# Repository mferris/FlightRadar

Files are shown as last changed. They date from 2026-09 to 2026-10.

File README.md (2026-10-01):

<p align="center">
  <picture>
    <source media="(prefers-color-scheme: dark)" srcset="assets/brand/logo-on-dark.svg">
    StratoScan
  </picture>
</p>

# StratoScan

*Formerly Radome, and before that FlightRadar.*

A live ADS-B flight radar on a round display, built on a
Raspberry Pi and a cheap SDR dongle — no subscription and no API keys. The
radar needs nothing but its own receiver and a browser; an optional iPhone
app brings it to your pocket.

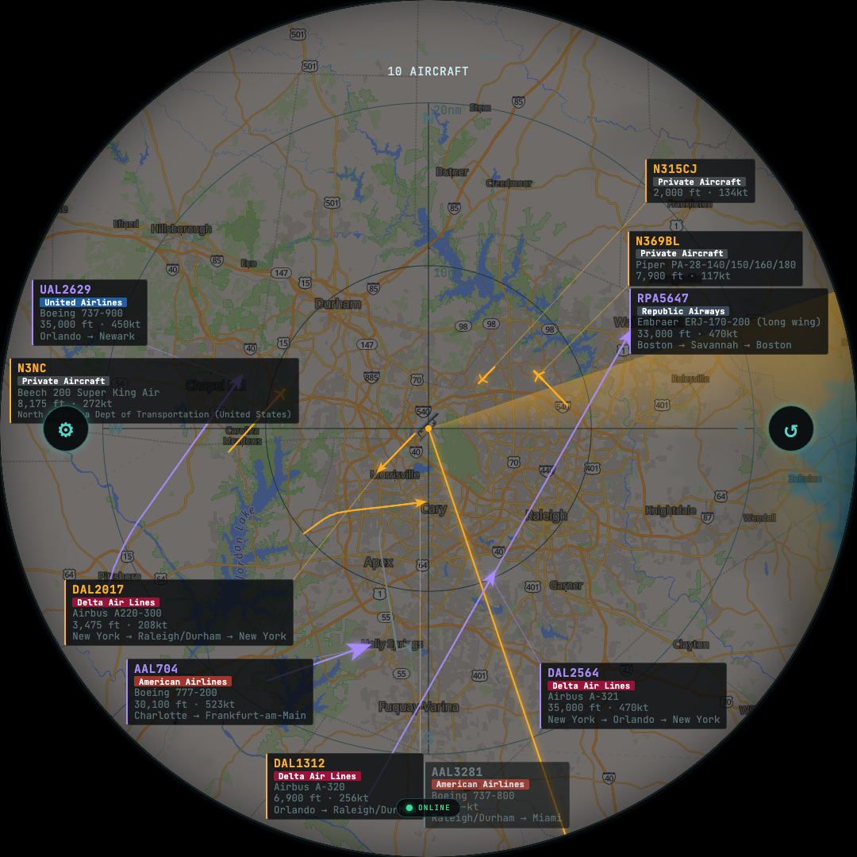
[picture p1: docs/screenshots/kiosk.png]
StratoScan running on the physical kiosk display


<sub>Centred on RDU airport. Map: OpenFreeMap © OpenMapTiles, data © [OpenStreetMap contributors](https://www.openstreetmap.org/copyright).</sub>

## Status

*As of 2026-09-30.* One unit (RDU) runs around the clock on release
`2026.09.30.11`. The plan is in [docs/ROADMAP.md](docs/ROADMAP.md), tracked
as [issues](https://github.com/mferris/StratoScan/issues), and the parts it still
needs are in the [shopping list](docs/SHOPPING.md).

| Area | State |
|---|---|
| The radar (kiosk) | Running unattended; updates itself from signed releases. One labelled aircraft feed on the unit for every screen (`/api/aircraft`); drawing cost halved |
| Phase 4 extras | Done: rewind, notable aircraft, empty-sky screen, spoken announcements, year in review, opt-in FlightAware feeding |
| Relay (push + fleet health) | Live on Cloudflare Workers |
| iPhone and iPad app | Working on a real iPhone: QR pairing, push alerts (including aircraft approaching *you*), widgets, Live Activity, home/away switching, the network's aircraft, zoom, a compass, Sky view with tracks, the logbook, weather, colour themes; a no-radar mode and an iPad layout (simulator-tested) |
| Apple Watch app | Built (glance radar, complications, Smart Stack); waiting for TestFlight to reach a real Watch |
| Security review | Full scan done 2026-09-28; every finding fixed and verified on the running unit |
| Factory SD image | Builds and passes its checks in CI; not yet test-flashed or published |
| Next up | Factory image test, the Watch on a real wrist, RTC battery fitting, alerts for aircraft approaching the phone, hardware v2 (light sensor, bezel) |

## What it does

Point an RTL-SDR dongle and a small antenna at the sky, and StratoScan turns
whatever ADS-B traffic it hears into a live circular radar display: bearing,
range, altitude, speed, heading, airline, aircraft type, route, and (when
available) a real photo of the airframe. It's designed to run unattended,
full-screen, on a small round touch panel — on a wall, or in the printed desk
cradle — but it's also just a web page, so it runs fine in a normal browser
too.

- **Live tracking** — polls a local [`readsb`](https://github.com/wiedehopf/readsb)
  instance every second; altitude-coded blips, smooth interpolation between
  polls, a "NO SIGNAL" banner on connection loss
- **Airline & route lookup** — badges each flight with its airline and shows
  its city-pair route where one's known, including multi-stop regional
  rotations
- **Aircraft type & photo** — human-readable type names ("Bombardier Regional
  Jet CRJ-900") and a real photo when one exists, falling back to a
  representative photo of the type
- **Background map** — real terrain, roads, and runway outlines (cached once
  fetched, so a restart doesn't wait on a fresh query), darkened and centered
  on the receiver, with an always-on live weather radar overlay and an
  optional satellite lightning-strike overlay
- **Approach visualization** — a real density heatmap of your home airport,
  built from actually observed landings over time rather than a canned
  flight-path overlay — busier stretches of the corridor read as more
  visually distinct than lightly-used ones, and it keeps sharpening the
  longer the receiver runs
- **Altitude-scaled blips** — a blip grows with altitude, from 0.68x on the
  ground to 1.30x at cruise, so height reads at a glance alongside the
  existing altitude colour. Deliberately not perspective: a higher aircraft
  is further away and would be smaller if this were about distance
- **Sighting counts** — every aircraft tracks how many distinct times this
  receiver has picked it up, and how many of those came within the
  nearby-alert radius; shown as a "SEEN ×N" badge once it's more than one,
  and as fields in the detail panel always
- **Registered-owner lookup** — for aircraft confirmed private (a real
  callsign, just not an airline one), the detail panel shows who the plane
  is registered to, pulled from public aircraft-registry data
- **Nearby-aircraft alert** — auto-pops flight details (with a chime) for
  anything passing within 2 miles of the receiver
- **Lightning proximity alert** — a chime + banner when a satellite-observed
  strike is detected within 15nm of the receiver, independent of the map's
  lightning overlay toggle
- **Rare aircraft alert** — a chime and an auto-popped panel for something
  worth walking outside for: an airframe on a military/government ICAO
  address, or an unusual type (747, A380, C-17, warbirds). Once the receiver
  has met enough traffic to know what normal looks like locally, it also
  flags aircraft it has never seen before
- **Emergency squawk alert** — an unmistakable alert (distinct chime + a red
  auto-popped panel) for 7500 (hijack), 7600 (radio failure), or 7700
  (general emergency)
- **Landing/takeoff highlight** — a bright green ring around the blip and
  label of anything currently landing or departing at your home airport, plus
  an optional quiet chime; pairs with an optional link to LiveATC.net's live
  approach/departure audio
- **Volume, mute, and a choice of alert sound** — every chime above goes
  through one master gain, adjustable up to 300% (with a limiter, so louder
  never means distorted) plus mute, and can play the original synth tones or
  real CC0-licensed recordings: cat sounds for a kitten-cased unit, or a real
  airline cabin chime for anyone — see `sounds/*/CREDITS.md` for what was
  recorded and how
- **Night dimming** — the display darkens between sunset and sunrise,
  computed from the receiver's own coordinates so it tracks the seasons
  without any configuration; alerts can optionally undim it
- **Screensaver** — the panel genuinely powers off after a configurable idle
  period (see [`deploy/`](deploy/)) and wakes on touch, or on an alert if
  you've enabled that
- **Settings menu** — a gear icon opens a menu grouped into short screens
  (Alerts, Map overlays, Display, ATC audio, Device setup) rather than one
  long list; every setting is one tap from the top, and the panel scrolls by
  dragging anywhere on it. Choices persist per-device
- **Configurable home airport** — 433 continental-US airports are bundled, so
  a unit can be moved or given away and re-pointed at a different field. The
  landing highlight, approach heatmap and ATC link all follow it
- **Set up entirely from the touchscreen** — WiFi (with an on-screen
  keyboard), receiver location, home airport, remote access and a factory
  reset, all without a phone or a shell. This is also the recovery path if
  the admin password is ever forgotten
- **First-run provisioning for a device you did not configure** — a unit with
  no known network raises its own `StratoScan-Setup` WiFi and displays what
  to join, what address to open and a claim code. A captive portal makes the
  setup page open automatically on a phone
- **Connectivity status** — a pill at the bottom of the display says whether
  the radar is actually working: online, on a network that is not reaching
  the internet, running its own setup WiFi, or receiving no aircraft data.
  On the device it reports what NetworkManager concludes about the
  connection; viewed remotely it falls back to whether data is still flowing
- **Restart from the screen** — a Restart row under Device setup, so a stuck
  unit does not need someone to find and pull the plug
- **Frozen-display watchdog** — the radar reports each painted frame to a
  local endpoint, and the device restarts the kiosk if the panel is powered
  on but nothing has been drawn for two and a half minutes. Chromium can
  lose its GPU context and stop painting while the page stays alive by every
  other measure, which otherwise leaves a stale radar on screen until
  somebody walks up to it. A blanked screen is not a fault: the watchdog
  checks the panel's real power state first
- **Statistics** — a Settings section that reads the accumulated flight
  history back: how many distinct aircraft have been heard and how many
  separate passes they made, how many came within two miles, and how much
  of it the antenna heard versus only saw through the network comparison.
  Broken down by operator (commercial / private / military — military
  recognised from the address block, so a military aircraft flying a
  civil-looking callsign still counts) and by airframe (heavy jets, jets,
  propeller, helicopters), using the same type database that decides each
  blip's shape. Plus all-time records — farthest contact, closest approach,
  highest, fastest — the busiest hour of the day and the busiest day of the
  week, and the most frequent visitors. The receiver scorecard lives here too
- **Network comparison** (on by default, and switchable off) — outlines the aircraft a public
  ADS-B network can see in your ring that your antenna did not hear, and
  keeps a scorecard of how you compare: overall coverage, which altitude
  bands and which bearings you are blind in, and position freshness against
  the network's. They are tracked, not just plotted: each keeps its identity
  between polls, is dead-reckoned forward from its last fix, and draws a
  dashed trail. Tap one to see what the network knows about it, clearly
  marked as reported rather than received. Measured here, the receiver was hearing 44% of the traffic
  in range, and 8 of the 9 it missed were below 4,000ft — the signature of a
  blocked horizon rather than a deaf receiver
- **Touch detail panel** — tap any aircraft for registration, squawk, vertical
  rate, and more
- **"What was that?"** — a rewind button lists the closest passes of the last
  hour and draws the chosen aircraft's track back onto the radar
- **Notable aircraft** — air ambulances, police, military and historic
  aircraft are labelled from [plane-alert-db](https://github.com/sdr-enthusiasts/plane-alert-db),
  refreshed weekly on each unit. Labels are neutral, and private owners'
  names are never shown
- **Empty-sky screen** — after 30 seconds with nothing overhead, a clock,
  the current weather and today's tally
- **Spoken announcements** (off by default) — a local
  [Piper](https://github.com/OHF-voice/piper1-gpl) voice names what is
  passing, generated on the unit with no cloud speech service
- **Year in review** — per-year counts of what the receiver heard
- **FlightAware feeding** (opt-in) — a setup-page card installs PiAware to
  share this receiver's data with FlightAware; it says plainly that the
  antenna's exact location is shared

### The iPhone app

A native SwiftUI app and widget ([`ios/`](ios/)), paired with a radar by
scanning a QR code on its screen:

- **The same radar in your pocket** — live aircraft, tap for details, and
  a label mode that keeps the map readable on a small screen
- **Alerts wherever you are** — emergency squawks, notable aircraft, low
  aircraft overhead and helicopters, pushed through the relay. Choose which
  kinds you want
- **Live Activity** (opt-in) — when the radar predicts a close pass (within
  2 miles in the next 3 minutes), a countdown appears on the lock screen and
  in the Dynamic Island, and closes itself after the pass
- **Home-screen and lock-screen widget** — how many aircraft are overhead and
  the nearest few; a radar widget for StandBy
- **Every aircraft, not just the ones the antenna hears** — the aircraft a
  public network (adsb.lol) reports are drawn hollow, with a "not heard" count
- **Zoom** — pinch on any spot, down to about a mile; the rings stay true
  distances from the radar. Follow an aircraft, or centre on yourself
- **Compass** — turn and the needle points at an aircraft, with which way it's
  coming from and going
- **Sky view** — hold the phone up and each aircraft's label sits where it is
  in the sky; tap one for its details. Away from home it can show the
  aircraft around you instead (opt-in; see [privacy](docs/privacy.md))
- **Logbook** — what your radar has seen: today, all-time totals, records
  (farthest, closest, highest, fastest), what flies over, when, and the
  regulars
- **Sky view tracks and Find in the sky** — each aircraft's path drawn
  across the sky; from any aircraft on the radar, a big arrow guides you to
  it in the camera view
- **Approaching you** (opt-in) — alerts for aircraft about to pass over
  where *you* are, not just the radar; your location is end-to-end
  encrypted to your own radar
- **Weather and themes** — rain, storms and lightning on the map, and the
  radar's four colour themes (Daylight by default)
- **iPad** — a big radar with details alongside, and a wall mode that dims
  at night
- **No radar yet?** — see live aircraft around you from the public
  adsb.lol network (opt-in), or play the demo
- **Home and away** — on your WiFi the app talks to the radar directly; away
  from home it switches to the radar's public HTTPS page by itself. The away
  address is learned from the radar
- **Demo mode** — a few minutes of real traffic recorded near RDU, so the
  app can be tried without a radar

## How it works

```
[Antenna] → [RTL-SDR dongle] → [readsb] → aircraft.json (local)
                                                 │
                                                 ▼
                                   [StratoScan: fetch + render]
                                                 │
                                                 ▼
                              [Chromium kiosk, full-screen] → [round display]

 Optional, for the phone app:

 [events.py on the unit] ──signed──▶ [relay: Cloudflare Worker + D1] ──APNs──▶ [iPhone]
        (what's worth an alert)        (pairing, push, fleet health)     (alerts, Live Activity)
```

The **relay** ([`relay/`](relay/)) is the project's one server. Units send it
signed events and opt-in health reports; it pairs phones with units and holds
Apple's push key, so no unit ever carries a secret that can act for the whole
fleet. The radar never depends on it: a unit that cannot reach the relay
works exactly as before. What it stores, and for how long, is in
[relay/README.md](relay/README.md).

`readsb` decodes raw ADS-B signals and writes `aircraft.json` to disk.
`index.html` is a single self-contained page — plain HTML/CSS/JS, Canvas for
the radar itself, [MapLibre GL JS](https://maplibre.org/) for the background
map — that polls that file and renders everything. No build step, no
framework, no server-side code beyond a couple of tiny same-origin proxies
(see [`deploy/`](deploy/)) for things browsers can't do directly, like
setting a custom User-Agent.

## Getting started

**Hardware and receiver setup** (Pi, RTL-SDR dongle, antenna, `readsb`
installation) is covered in [`docs/project-spec.md`](docs/project-spec.md),
including a suggested two-wave purchase plan so you can confirm reception
before buying a display.

One thing worth doing before you chase any reception problem: install
[`deploy/blacklist-rtlsdr.conf`](deploy/blacklist-rtlsdr.conf) to
`/etc/modprobe.d/`. The RTL2832U is sold as a TV tuner, so without it the
kernel's DVB-T driver claims the dongle on every plug and fights readsb for
it, producing `error -71` and constant disconnects.

**Running the web app locally**, against a receiver on your network:

```bash
python3 dev-server.py
```

Then open `http://localhost:8000/index.html`. `dev-server.py` proxies
`/tar1090/*` requests to your receiver so the page can be tested with the
exact same relative paths it uses once deployed — edit `PI_HOST` at the top
of the file to point at your own receiver. It's dev-only and isn't part of
the deployed app.

**Deploying as a kiosk**: `index.html` is a static file — copy it to your
receiver's web server docroot (same origin as `readsb`'s own web UI, to avoid
CORS). [`deploy/`](deploy/) has a systemd unit for launching Chromium in
kiosk mode on boot, plus small same-origin services: aircraft photos, the
shared approach-track store, the shared sighting-count store, the display-wake
endpoint, the optional network-comparison proxy, and (only relevant if you
expose the page to the public internet,
e.g. via Tailscale Funnel) a filtering gateway that rounds the receiver's
exact coordinates before they leave your network — see
[Security](#security) below.

**Device setup (optional)**: everything above works on a receiver you
configured yourself. If you want a unit someone *else* can set up — moved to a
new house, or given away — install the setup server:

```bash
sudo sh deploy/install-setup-server.sh
```

That adds a web setup page at `http://<device>/setup`, the same screens on the
radar's own touchscreen, and the pieces that make a device with no network
recoverable. The installer refuses to finish unless it can prove the public
gateway is refusing `/setup`, since that page accepts a WiFi password and a
Tailscale auth key.

How a fresh unit behaves:

1. It finds no known WiFi, so after ~45s it raises `StratoScan-Setup`
2. Its screen shows that network's name and password, the address to open,
   and an 8-character claim code
3. A phone joining that network gets the setup page automatically, via the
   captive portal
4. WiFi, receiver location, home airport and an admin password are set; the
   setup screen disappears

The same things can be done on the touchscreen instead, which is the only
route if the admin password is ever forgotten. **Erase everything** clears the
WiFi, the Tailscale identity, the password, the coordinates *and* the
accumulated flight history and approach heatmap — the last two are a record of
what flew over the previous owner's house — then raises the hotspot so the
next person can claim it.

Two services run as `systemctl --user` rather than system units (the
screensaver and display-wake endpoint) because they need the graphical
session's `WAYLAND_DISPLAY`. A `stratoscan-netwatchdog` timer rolls back any
unconfirmed network change at boot and raises the hotspot when there is no
usable connection — so a mistyped WiFi password reverts itself rather than
stranding the device.

**The 4am restart, and why it is a workaround.** Chromium on this platform
leaks unlinked `/dev/shm` mappings at roughly 200–300 MB/h of daytime
rendering. Left alone it fills the 4GB tmpfs in five to twelve hours, GPU
allocations start failing with `TransferBuffer::Initialize() failed`, and the
panel freezes on a stale frame — twice in one 34-hour stretch here.
`stratoscan-kiosk-restart.timer` restarts the kiosk at 04:00, when the panel
is already blanked and the sky is empty, returning `/dev/shm` from ~2GB to
~200MB. The frozen-display watchdog in `wake-listener.py` stays as the
backstop.

A second timer, `stratoscan-shmguard`, closes the gap the daily restart
leaves: it samples every five minutes and acts on the measurement rather than
the clock. **It reloads the page before it restarts the browser.** Tearing
down the document releases a third to a half of the accumulated shared memory
(151MB → 72MB and 124MB → 79MB, measured) without killing Chromium — no black
screen, no risk of coming back windowed — and the restart is kept as the
escalation for when a reload is not enough. Two marks, because a restart is only free when nobody is
looking — at **900MB it restarts only while the panel is blanked**, so most
restarts happen invisibly, and at **1500MB it restarts regardless**, which is
the one that actually prevents the freeze. It measures both `/dev/shm` usage
and the sum of Chromium's renderer shm mappings and acts on whichever is
larger, because the two diverge: `/etc/chromium.d/dev-shm` adds
`--disable-dev-shm-usage` when `/dev/shm` has under 3.8GB free at launch, so
after one bad day Chromium moves its backing to `/tmp` and the `df` number
stops tracking the leak. Restarts are rate-limited to one per 30 minutes — if
something other than the leak fills the arena, a guard that restarts forever
is worse than the freeze it was written to prevent. The 04:00 restart runs
through the same script (with `SHMGUARD_FORCE=1`) so both share that one rate
limit.

**Chromium must not be restarted while the panel is blanked.** It comes up
windowed — tab bar, address bar, desktop wallpaper — even with `--kiosk` on
its command line, because it cannot take an output that is off and does not
retry when the output returns. Reproduced both ways on the device: panel off
gives a windowed browser every time, panel on gives fullscreen every time.
This mattered most for the 04:00 restart, which by design runs when the
screensaver has blanked the panel, so it would have left the display windowed
every morning. The guard now wakes the panel, restarts, waits for Chromium to
take the display, and only then puts the panel back as it found it.

It also **repairs a windowed browser however it happens**, not just when the
guard itself caused it — that is the failure a recipient would simply live
with. Every run it grabs the screen and measures the top-left corner:
fullscreen reads 0 on this panel, windowed reads 232, so the threshold sits
at 60 with a wide margin. Verified by breaking it deliberately and watching
the guard put it back.

**A reload cannot be delivered while the panel is blanked**, and that took
two wrong diagnoses to see. The instruction rides the paint heartbeat, and
`reportPainted()` is driven by `requestAnimationFrame` — with nothing being
composited there are no frames, so the page never posts `/wake/alive` and
never collects the flag. Six attempts told the story cleanly: five with the
panel off freed 0MB each, with the listener logging no delivery at all, while
the one with the panel on freed **597MB of 700MB**.

The apparent pattern before that — "reloads stop working above ~600MB" — was
an artifact: every failed attempt happened to be panel-off. Memory level was
never the variable.

So the guard reloads only when the panel is on (at 700MB), and when the panel
is off it restarts outright at 600MB, which is invisible precisely because
the panel is off. A restart at 1400MB remains the backstop with the panel on.

The reload is requested without any control channel of its own. The page
already POSTs `/wake/alive` every 20 seconds as the frozen-display heartbeat;
the guard drops a file in `$XDG_RUNTIME_DIR`, and the listener answers that
next heartbeat with `{"reload":1}` instead of `204`. So there is no debug
port, no key-injection helper and no new listener: only a local process
running as the kiosk user can ask for a reload. Nothing is lost by reloading —
sightings, statistics and the approach heatmap all live in the server-side
stores — beyond trails and ghost tracks, which rebuild within a sweep.

It is a workaround and not a fix, because the cause is not in this codebase:
a blank page leaks the same way, the mappings are invisible to Chromium's own
`memory-infra` accounting, and a critical memory-pressure signal reclaims
none of them. Removing the map, the weather overlays and the canvas render
loop each failed to stop it. One caveat worth keeping in view: the observed
time-to-freeze was as short as 5.2 hours, so a single daily restart is not
guaranteed to cover a long, busy day on its own.

**The enclosure**: [`enclosure/`](enclosure/) has two printable cases for the
same hardware — the original ship's-instrument look, and one shaped like a
sitting cat with the round display as its face, printed in two colours. Both are parametric OpenSCAD,
everything deriving from the measured values at the top of each file. Each
folder's README covers how to export the parts, the interference checks, and
the dimensional mistakes that are easy to repeat.

**iOS app**: `ios/` is an [XcodeGen](https://github.com/yonaskolb/XcodeGen)
project (app plus widget extension, iOS 17.2 or later). Run `xcodegen generate`
inside `ios/` if you change `project.yml`, then open `StratoScan.xcodeproj` in
Xcode. To build your own, set your signing team, bundle id and App Group in
`project.yml`. On the radar, open Settings › Phone & Watch to show a pairing
code, then scan it from the app. Push alerts need your own relay and an APNs
key (see [relay/README.md](relay/README.md)); without them the app still
shows the live radar.

**Relay**: a Cloudflare Worker on the free plan. From `relay/`:
`npm test`, then `npm run db:init && npx wrangler deploy`. Apple's `.p8` key
goes in with `wrangler secret put APNS_KEY`, never into the repo.

## Project structure

```
index.html      the whole web app — single file, no build step
dev-server.py   local-only dev proxy (not deployed)
deploy/         systemd units, same-origin services, events, pairing and the setup server
docs/           roadmap, spec, privacy policy, gifting guide, screenshots
enclosure/      parametric OpenSCAD source for the printed cases (two designs)
tests/          regression tests for the security-critical paths
vendor/         vendored MapLibre GL JS (self-hosted, no CDN dependency)
sounds/         CC0 audio for the alert sound themes (see sounds/*/CREDITS.md)
ios/            native SwiftUI app, widget and Live Activity
relay/          Cloudflare Worker: pairing, push, fleet health
scripts/        signed release script
image/          factory SD-card image build (run in CI)
```

See [CHANGELOG.md](CHANGELOG.md) for release notes and
[HANDOFF.md](HANDOFF.md) for the detailed development history.

## Data sources

StratoScan leans entirely on free, no-key-required public data, same as
[tar1090](https://github.com/wiedehopf/tar1090) (GPL-2.0-or-later; it inspired
several of these choices, but no code is shared):

- **[readsb](https://github.com/wiedehopf/readsb)** — ADS-B decoding
- **[MapLibre GL JS](https://maplibre.org/)** (BSD-3-Clause, vendored under [`vendor/`](vendor/) — self-hosted, no CDN dependency) + **[OpenFreeMap](https://openfreemap.org/)** — background map tiles/style
- **[OpenStreetMap](https://www.openstreetmap.org/) via Overpass** — real runway/taxiway geometry
- **[adsb.im](https://adsb.im/)** — route (city-pair) lookups
- **[RainViewer](https://www.rainviewer.com/)** — live weather radar overlay (their API is free for personal/educational use only)
- **[planespotters.net](https://www.planespotters.net/)** — aircraft photos
- **[Wikimedia Commons](https://commons.wikimedia.org/)** — representative type photos when no tail-specific one exists, credited with author and license
- **[adsbdb.com](https://www.adsbdb.com/)** — registered-owner lookups for confirmed-private aircraft
- **[LiveATC.net](https://www.liveatc.net/)** — ATC audio for the configured airport, opened as a link to their own player (see [Security](#security) below for why it's a link, not an embed)
- **[SSEC RealEarth](https://realearth.ssec.wisc.edu/)** (UW-Madison) — satellite-observed lightning strike density (GOES-East GLM)
- **[Protomaps](https://protomaps.com)** OpenStreetMap builds (© OpenStreetMap contributors, ODbL) — the per-unit offline fallback map built by [`deploy/offline-map.py`](deploy/offline-map.py)
- **[OurAirports](https://ourairports.com/data/)** (public domain) — the bundled airport table in [`deploy/airports.json`](deploy/airports.json)
- **[plane-alert-db](https://github.com/sdr-enthusiasts/plane-alert-db)** (ODbL) — the notable-aircraft list
- **[tar1090-db](https://github.com/wiedehopf/tar1090-db)** — aircraft type and registration from the ICAO address, read from the unit's own tar1090 install
- **[Open-Meteo](https://open-meteo.com/)** — current weather on the empty-sky screen (free for non-commercial use)
- **[adsb.lol](https://adsb.lol/)** — community-run ADS-B aggregation, used only by the network comparison, which can be switched off. Queried at most once every 15s no matter how many people are viewing, with coordinates rounded to ~1.1km

Every obligation these carry, and how each is met, is in
[THIRD_PARTY_NOTICES.md](THIRD_PARTY_NOTICES.md). Please respect each
service's own terms if you build on this; RainViewer in particular is not
for commercial use.

## Security

If you expose this beyond your own LAN (e.g. a Tailscale Funnel URL, like the
live deployment this repo was built against), a few things are worth knowing
before you do:

- **The receiver's exact coordinates are not something you want publicly
  reachable.** `readsb`'s own `receiver.json` endpoint returns
  survey-precision lat/lon, and by default that's reachable by anyone who
  finds the URL. [`deploy/funnel-gateway.py`](deploy/funnel-gateway.py) sits
  in front of whatever you expose publicly and rounds those coordinates to
  ~0.7 mile precision for public traffic only — your LAN/kiosk always sees
  the exact value, which `readsb` itself needs for its own signal-range math.
  Point your public tunnel at this gateway instead of at `readsb`/lighttpd
  directly. The gateway also strips each aircraft's distance and bearing
  *from the antenna* (`r_dst`, `r_dir`) out of the public `aircraft.json`:
  with two or three aircraft positions, those fields pinpoint the receiver, which undid the rounding entirely.
- **External data (route text, photo credits, aircraft type) is escaped
  before it touches the DOM.** Some of it — a photographer's display name on
  planespotters.net, for instance — is third-party user-submitted content
  this app doesn't control.
- **The shared same-origin stores are read-only for public traffic.**
  `deploy/approach-store.py` and `deploy/sighting-store.py` have no
  authentication of their own, which was fine while only the LAN could reach
  them. Once the page is exposed through a tunnel they become writable by
  anyone holding the URL — confirmed by injecting a fake sighting through it
  — so the gateway now refuses any non-GET to `/sightings` and `/approaches`
  from public traffic (`READ_ONLY_PUBLIC_PATHS`). Reads stay open, because
  public viewers need them; the kiosk and LAN still write normally. They also
  cap request body size and validate input shape.
- **Privileged endpoints are refused for public traffic**, and the check
  normalises the path first. `/wake` (which powers the kiosk's panel on) and
  `/setup` are listed in `LOCAL_ONLY_PATHS` in
  [`deploy/funnel-gateway.py`](deploy/funnel-gateway.py) and 404 for anything
  arriving through the tunnel. The normalising matters: an earlier version
  compared the raw path, and because lighttpd percent-decodes and collapses
  traversal before routing, `/./wake`, `/x/../wake` and `/%77ake` all reached
  the endpoint anyway. [`tests/test_funnel_gateway_paths.py`](tests/test_funnel_gateway_paths.py)
  pins the behaviour — run it after touching that filter.
- **The setup server is split across a privilege boundary.** The HTTP tier
  runs unprivileged and can only ask a small root helper
  ([`deploy/setupd.py`](deploy/setupd.py)) to perform a closed list of verbs
  over a unix socket — there is no "run nmcli" passthrough, so compromising
  the HTTP parser does not yield arbitrary root. The root helper re-validates
  every parameter rather than trusting the caller, uses no shell, and keeps
  secrets out of argv (where any local user could read them from `/proc`).
  [`tests/test_setupd_validation.py`](tests/test_setupd_validation.py) pins
  the validation table and the `/etc/default/readsb` rewriter, which is a
  root-sourced shell file and therefore a command-execution sink.
- **On-device setup deliberately needs no password**, and the endpoint behind
  it is bound to loopback and not proxied, so reaching it means already being
  on the device. That is the same physical assumption every appliance makes,
  and it has to be true: it is the only way back in for someone who has
  forgotten the admin password. The web route, which *is* reachable across
  the LAN, still requires it.
- **Erasing a unit removes the accumulated data too.** The flight history
  and approach heatmap are a record of which aircraft passed over the
  previous owner's house — and the history now carries each aircraft's
  callsign and classification alongside its counts, which makes it more
  identifying than a bare tally, not less — so a full reset clears them
  along with the credentials and coordinates. A settings-only reset keeps them, and keeps
  the network, so it is safe to run remotely.
- **The network comparison is on by default and sends only a rounded
  position.** It can be switched off in Settings, and switching it off stops
  the device contacting adsb.lol at all. The device-side proxy makes
  no request of its own — it only fetches when a page with the setting on
  asks it to — and it queries with coordinates rounded to 2dp, the same
  precision the public gateway already exposes. Asking a stranger "what is
  near me" with survey-precision coordinates would undo the rounding the
  rest of this project does deliberately. `/network` is readable publicly
  but refuses writes, so nobody holding the URL can drive traffic at a
  community-run service on this device's behalf.
- **The display-wake endpoint answers only the device itself.** lighttpd
  refuses `/wake` from anything but `127.0.0.1` and `::1`, so a LAN device
  cannot power the panel on or fake the frozen-display heartbeat.
- **SSH is key-only.** The installer drops
  [`deploy/10-stratoscan-ssh.conf`](deploy/10-stratoscan-ssh.conf) into
  `sshd_config.d`: no passwords, no root login, no X11 forwarding. It
  validates the config with `sshd -t` before reloading.
- **Downloaded code is pinned.** The Piper speech engine installs with
  `pip --require-hashes` from
  [`deploy/tts-requirements.txt`](deploy/tts-requirements.txt), and its voice
  model is checked against [`deploy/tts-voice.sha256`](deploy/tts-voice.sha256).
- **Units and phones prove who they are to the relay.** Every unit request is
  signed with the unit's own Ed25519 key, and every phone request with a key
  generated on the phone. Pairing takes a one-time code shown on the radar's
  screen, which expires in 10 minutes or after five wrong guesses. Only a
  hash of it is stored.
- **No secrets in the repository or on units.** The radar's data sources are
  free and keyless (see [Data sources](#data-sources) above). The one secret
  the project has, Apple's push key, lives only in the relay as a Cloudflare
  secret.
- **ATC audio is a link, not an embed.** LiveATC.net's
  [Terms of Use](https://www.liveatc.net/legal/) require consulting them
  before linking directly to a raw audio stream, and separately bar making
  their service "directly available" through another dedicated application,
  for profit or not. The ATC toggle opens their own player page in a normal
  browser tab instead — ordinary use of their site, same as bookmarking it
  yourself — and is disabled outright on the kiosk itself (`?kiosk=1` on its
  launch URL), since a new browser window/tab inside `--kiosk` Chromium has
  no touch-reachable way back to the radar.

## License

MIT — see [LICENSE](LICENSE). The StratoScan name, logo and icons are not:
they identify the project, so a fork should use its own (see
[assets/brand/LICENSE](assets/brand/LICENSE)). Third-party components and data sources keep
their own licenses and terms; see [THIRD_PARTY_NOTICES.md](THIRD_PARTY_NOTICES.md).

## Setting one up somewhere else

The first build assumed the continental US in more places than was obvious,
and each one was a hard stop rather than a rough edge:

- **Coordinates were forced into the northern and western hemispheres.** The
  setup page and the touchscreen both "helpfully" made latitude positive and
  longitude negative, on the reasoning that a sign left off a US coordinate is
  unambiguous. It is — and it silently moved a receiver in the Netherlands
  (4.49°E) to 4.49°W, in the Atlantic, while making the entire southern
  hemisphere unreachable. `setupd` agreed, rejecting anything outside
  24–49.5°N and 66.5–125°W as "outside the continental US".
- **The airport list was 433 US airports.** Now 3,269 worldwide (large and
  medium fields with scheduled service, from OurAirports), so Schiphol and
  San Carlos are both a search away.
- **Time zone and WiFi region were baked into the image** as
  America/New_York and US, with no way to change either from setup. A unit
  abroad timestamped every sighting wrongly and ran its radio on the wrong
  channel set.
- **The lightning overlay is GOES-East**, which only sees the Americas.
  Outside that footprint every tile is a 404, so the setting now hides itself
  and says why rather than offering a toggle that cannot work.

**Location is entered as an address by default.** Nobody knows their
coordinates; everybody knows their address. The lookup runs on the *device*
rather than in the browser, because during first-time setup the phone is
joined to the device's own hotspot and has no route to the internet, while
the Pi was put on WiFi in the previous step — a browser-side lookup would
fail exactly when it is needed. The address reaches OpenStreetMap's
Nominatim and nothing else, the position it returns stays on the device, and
typing coordinates by hand remains one tap away for anyone who would rather
not send an address anywhere.

Picking the home airport sets the country, which seeds the time-zone step
with the one or two zones that country actually uses instead of all 485, and
sets the WiFi regulatory region to match. Both the phone page and the
touchscreen can complete setup on their own.

**The WiFi region only takes effect after a restart**, and both UIs say so.
Two things about `raspi-config nonint do_wifi_country` were found by running
it on the device rather than reading about it:

- **It exits non-zero on success.** Its NetworkManager and `wpa_cli` steps try
  to reach a session message bus, which does not exist when the call comes
  from a daemon, so it prints an error and returns 1 *after* writing the
  setting. Judging it by its exit code reports failure for a change that
  worked, so the result is judged by reading the value back instead.
- **The running regulatory domain does not change.** The Pi's Broadcom radio
  registers a custom regulatory table — `phy#0` reports `country 99` — so the
  driver overrides `iw reg set` and the global domain reads `98` until the
  next boot, when `cfg80211.ieee80211_regdom` on the kernel command line
  applies it for real.

The change is safe to make over WiFi: tested on a live link, the SSID, IP
address, connectivity, channel and an active SSH session were all unaffected
throughout.

Because it needs a restart, both surfaces offer one — but **only when the
region actually changed**. `set_wifi_country` reads the country before and
after and reports `changed`, so re-saving the same region never sends anyone
to power-cycle a working device. The prompt says the setting is stored, that
the radio still follows the old region until then, and that nothing else is
waiting on it, so leaving it until the next power-on is a legitimate choice
rather than an unfinished step.

## Updating a unit that has been given away

A gifted radar cannot be fixed by SSH, so it can update itself — carefully.

**Signed, or refused.** A release is accepted only if its manifest carries an
Ed25519 signature (`ssh-keygen -Y`) from the key in
`deploy/allowed_signers`, which is baked in before a unit ships. The private
half lives on the maintainer's machine and never touches a device, GitHub, or
CI. GitHub is delivery, not trust: a compromised account or token could
publish a release, it could not sign one. `ssh-keygen` rather than minisign or
gpg because it is already installed — no new dependency on a box nobody can
log into.

**Newer, or refused.** The device compares an integer serial, not a version
string. An old release stays correctly signed forever, so without this a unit
could be walked backwards onto a build whose bugs are already fixed.

**It undoes itself.** After installing, the display must paint a frame within
90 seconds or the previous files go back and the kiosk restarts again. This
reuses the heartbeat the frozen-display watchdog already depends on, so an
update that blanks the screen is caught by the thing already watching the
screen — with nobody in the room. Verified by signing and applying a build
that throws before rendering: it was staged, installed, failed to paint, and
rolled back, and the previous `index.html` came back byte-identical.

**It cannot install anywhere it likes.** Only an allowlisted set of
destinations is writable, which excludes `allowed_signers` itself — an update
must not be able to replace the key that vouches for it, or one bad release
owns the device forever.

Checking is a timer (twice a day, randomised). **Installing is a deliberate
act** from the settings screen or the setup page: a unit that silently
replaced its own software overnight would be a different thing to give
somebody. Neither surface ever claims "up to date" for a device that has
simply never looked.

The manifest carries each file's **executable bit** as well as its hash, and
only that bit — a manifest that could set arbitrary permissions on root-owned
files would be a much larger thing to sign off on than one that can say "this
is a program". It is there because the first real update installed a new
`ota.py` without its executable bit and broke its own updater; the services
survived only because their units run `python3 <script>` rather than exec'ing
it.

The paint check refuses to run at all if the heartbeat file is missing, rather
than rolling back every update. That, too, is from experience: the stamp
originally lived in `/run/stratoscan`, which is setupd's `RuntimeDirectory=`
— systemd recreates it root-owned whenever the root helper restarts, so the
kiosk user silently lost the ability to write it, and a perfectly good release
was reverted because nothing could record that the screen was painting. It now
lives in the kiosk user's own runtime directory.

To cut a release: `sh scripts/release.sh <version>`. It builds the bundle,
writes a manifest of per-file hashes, signs it, **verifies its own output with
the public key the devices carry**, and only then publishes to GitHub
Releases.

**Changed services are restarted.** A long-running service keeps its old code
until it restarts, and the updater originally restarted only the kiosk — so a
security fix to `funnel-gateway.py` was reported installed while the old
gateway kept running for hours. It now compares each file with the one it
replaces and restarts exactly the services whose code changed (and restarts
them again on a rollback). Like any change to `ota.py`, that behaviour starts
with the release *after* the one that installs it.

The serial is the commit count, so two releases cut from the same commit carry
the same serial and the second is refused as "not newer" — commit first.

## Built to run for ten years

Measured on the first unit and reviewed for a decade of unattended running at
busy sites (SFO, Schiphol) as well as quiet ones:

- **SD card wear.** The stores keep their data in memory and write at most
  every 10 minutes and on shutdown; they used to rewrite the whole file on
  every sighting (3.5 GB in 17 hours, ~100 GB/day at a busy site once full).
  Chromium's HTTP cache lives in RAM, and it keeps no shader cache on disk.
  Dirty pages are batched for two minutes before writeback. The history store evicts the aircraft
  seen *least recently*, so daily regulars survive a full store. Measured in
  steady state: 2.25 GB/day, about 8 TB over ten years, well under a 128 GB
  high-endurance card's rating.
- **Recovery without a person.** The hardware watchdog reboots a hung kernel;
  `kernel.panic=10` reboots a panicked one. `net-watchdog.py` also restarts
  `readsb` when its output goes stale and reboots after repeated failed
  restarts, and reboots when the frozen-display watchdog's browser restarts
  keep failing — never more than once every 6 hours, so a fault a reboot
  cannot fix degrades to a few reboots a day, not a loop.
- **A hung radio is power-cycled, not just rebooted.** The Pi 5 keeps USB
  power on through a reboot, so a wedged SDR stays wedged. Before rebooting,
  the watchdog cuts USB power with [uhubctl](https://github.com/mvp/uhubctl)
  for a few seconds and turns it back on (at most once every 30 minutes).
- **Security updates** via unattended-upgrades (Debian security and point
  releases, the Raspberry Pi archive, Tailscale), holding Chromium, the
  kernel and firmware — a bad unattended update to those strands a unit.
- **An offline map.** When the location is set or changed, the unit
  downloads its own area (2–7 MB) from [Protomaps](https://protomaps.com)'
  OpenStreetMap builds into `/offline-map/`, and the page falls back to it
  whenever OpenFreeMap can't be reached — so a dead tile service or a boot
  before WiFi is up shows a real map, not a blank disc.

These system-level pieces (unattended-upgrades, sysctl, unit files) are
installed by `deploy/install-setup-server.sh`, never by an update — re-run it
on any unit before it leaves the house. What remains is hardware: an RTC
battery (ML-2020, with `dtparam=rtc_bbat_vchg`) keeps the clock across power
cuts, and a high-endurance SD card or an NVMe drive is the better medium for
a decade.

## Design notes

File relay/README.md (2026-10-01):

# StratoScan relay

The one small server the project runs: a Cloudflare Worker with a D1
database. It receives **opt-in health reports** and **events** from units,
pairs phones with units by QR code, sends push alerts and Live Activities to
those phones through Apple (APNs), and shows the maintainer a fleet page. The design is
in [docs/ROADMAP.md](../docs/ROADMAP.md#architecture-the-relay).

**The radar never depends on it.** A unit that can't reach the relay, or has
reporting switched off, works exactly as before.

## What it stores

For each unit:
- its public key (which is its id);
- a name the maintainer gives it;
- first and last report times;
- its software version;
- its last ~30 days of health reports: uptime, receiver health, storage
  wear, temperature, clock battery, update state.

For each unit that sends **events** (roadmap 2.2; only once its owner
pairs a phone): the moments it decided a paired phone should hear about.
There are four kinds: emergency squawks, notable aircraft, low aircraft
overhead and helicopters. Each carries the aircraft's identity, type,
altitude, its distance from the unit rounded to half a nautical mile with
a compass direction, and its track (the direction it's travelling, which it
broadcasts itself). Events are kept for **48 hours** at most (500 per
unit), only long enough to deliver them. The fleet page shows how many
arrived, never what they were.

For **pairing** (roadmap 2.3): which phones are paired with which unit,
each phone's public key (its id) and the name it gave itself ("iPhone"),
and while a code is showing on a unit's screen, that code's SHA-256. The
code itself reaches the relay only when a phone presents it, is compared
and then discarded; it works once, and expires after 10 minutes or five
wrong guesses. A unit stops sending events when its last phone unpairs,
and the relay drops events from a unit with no phones.

For **push** (roadmap 2.1): each paired phone's APNs device token, whether
it is a development or App Store build, and which alert kinds it wants.
A token is only an address for Apple's push service. Apple tells the relay
when a token stops working, and the relay then forgets it. Each phone gets
at most 30 ordinary alerts an hour; emergencies always go through.

For **alerts about aircraft approaching a phone** (roadmap 2.7; only for
phones whose owner turns on "Approaching me"):
- each unit's X25519 "box" key, signed by the unit's own Ed25519 key;
- each such phone's latest location for each of its units, **as an opaque
  encrypted blob**. The phone seals it to that unit's box key, after
  checking the key's signature against the unit id it scanned at pairing,
  so the relay can neither read it nor substitute a key of its own. Kept 6
  hours at most, and deleted when the phone unpairs or turns the option
  off. The unit decrypts it and runs its approach prediction for that
  point; the approach event it sends back names the phone (it goes to that
  phone alone) and the aircraft, without distance or direction.

**No locations in the clear.** Reports or events carrying a latitude or
longitude field are rejected outright. No network addresses are stored either. An event
still says roughly where its unit is ("a helicopter passed within 2
miles"), which is why events are opt-in and kept so briefly.

## Security model

- Each unit signs every request with its own Ed25519 key, generated on the
  unit and never copied off it. No shared secret is baked into images.
- Requests are bound to their timestamp, method, path and body. The relay
  rejects anything more than 5 minutes off or replayed. Health reports may
  come at most every 10 minutes. Events are capped at 120 an hour per unit
  and 20 per request, and every field is validated and length-limited
  before it is stored.
- An unknown key registers on first contact. The number of units is capped,
  so this can't grow without bound.
- Phones sign the same way with their own Ed25519 key (CryptoKit on iOS),
  named in `X-FR-Phone`. A phone can only pair by presenting the code on a
  unit's screen, and can only unpair itself. A unit can list and remove its
  own phones.
- The fleet page requires HTTP Basic auth against the `FLEET_TOKEN` secret.
  With no secret set, the page doesn't exist at all. Its only form refuses
  cross-site posts.

## Deploy (once, by the maintainer)

```bash
cd relay
npm install
npx wrangler login                                  # opens a browser
npx wrangler d1 create stratoscan-relay             # copy the id into wrangler.toml
npm run db:init                                     # applies schema.sql
npx wrangler secret put FLEET_TOKEN                 # choose a long random password
npx wrangler secret put APNS_KEY < AuthKey_XXXX.p8  # the APNs auth key from developer.apple.com
                                                    # (key id, team id and app id go in wrangler.toml [vars])
npm run deploy                                      # serves the custom domain in wrangler.toml (and https://stratoscan-relay.<you>.workers.dev)
```

After a change to `schema.sql` (new tables only, never altered ones), run
`npm run db:init` again before `npm run deploy`. It is safe to repeat.

Then set `RELAY_URL` in `deploy/heartbeat.py` to that address and cut a
release; units that have opted in start reporting within a few minutes. The
fleet page is at `/fleet`.

The free Cloudflare plan covers this comfortably: one small request per unit
every 6 hours.

## Test

```bash
npm test
```

The tests run the Worker and its real SQL (Node's built-in SQLite behind a
D1 stand-in). They include a request signed by the Python unit client on a
real device, so the two sides can't silently drift apart.

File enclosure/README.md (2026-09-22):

# Enclosures

Two cases for the same radar. They use identical hardware — the 203.34mm round
panel, a Raspberry Pi 5, two 100×45mm speakers, a 30mm fan, an RTL-SDR dongle —
and identical fasteners, so a build can be moved from one to the other.

| | |
|---|---|
| [Retro Radar Enclosure](Retro%20Radar%20Enclosure/) | The original: ribbed, riveted, ship's-instrument look. Printed and validated. |
| [Kitten Enclosure Two-Tone](Kitten%20Enclosure%20Two-Tone/) | The round display as a cat's face — ears, whisker-dot speaker grilles, a nose on the bezel, and a stand with white paws, black toes and a black tail with a white tip. |

Neither has the old antenna turret. Both take the same bolt-on antenna mount,
screwed into brass inserts in the back plate, with the coax coming up through
the middle of the bolt circle. The retro's `antenna_turret_*` modules are
still in the file on purpose: they are the positive control for the
`no_turret` check, which cannot tell "the turret is gone" from "the probe
missed" without something for the probe to find.

## One case, two costumes

The interior and the back are the *same design*, not two designs that
resemble each other. Everything the hardware touches — the back plate and its
lip, USB-C cutout and grilles; the cradle rails, fan mount, speaker brackets
and back posts; the display retainer; the exhaust slots; the whole antenna
mount — is character-for-character identical in both `.scad` files, and all
115 shared parameters carry the same values. A back plate printed for one unit
fits the other; rendered from either file it is the same 15,474-triangle mesh.

Only three modules differ, and only outside: `shell` (rivets and ribs vs ears),
`front_trim` (the kitten adds a nose and whisker grooves, and omits the one
screw the nose sits on) and `stand`.

This is enforced, because drift here is invisible — both files still render,
and both still pass their own `checks.scad`. It went wrong once already: the
kitten's exhaust slots were upgraded to 12mm rounded slots and the retro was
left on the old flat rectangles for long enough that the retro still defined
`exhaust_slot_h = 12` without using it. `tests/test_enclosure_core.py` now
fails if a core module or a shared parameter diverges, or if a newly shared
module starts to.

STLs are committed alongside the source so each folder is self-contained, but
they are generated. Change a `.scad` and both must be re-exported and
committed together, or the mesh quietly stops matching the source it claims to
come from.

A single-colour kitten design lived here too and has been removed; the
two-tone one supersedes it, and `stand.stl` in that folder is the whole stand
in one piece if you do not want two filaments.

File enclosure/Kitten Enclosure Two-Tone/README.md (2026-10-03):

# Kitten enclosure — two-tone

The round display as a cat's face, in two colours: black stand, **white paws
with black toes**, and a **black tail with a white tip**. Ears, whisker-dot
speaker grilles, a nose on the bezel, and a stand with paws and a curled
tail.

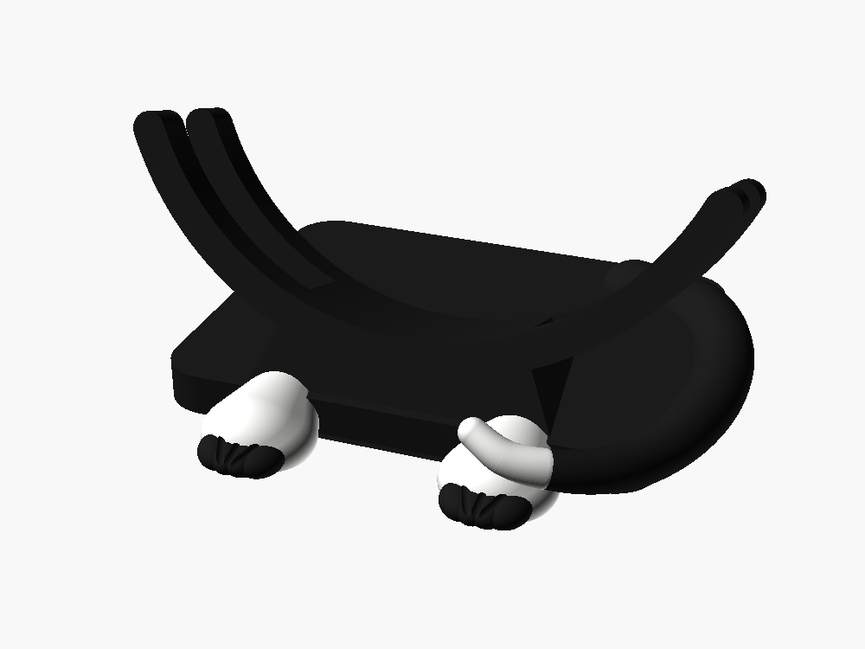
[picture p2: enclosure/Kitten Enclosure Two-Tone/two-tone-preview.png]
two-tone stand


Every dimension that touches a physical part comes verbatim from the
[Retro Radar Enclosure](../Retro%20Radar%20Enclosure/), which is printed and
validated: the 203.34mm round panel, the Pi's 58×49 standoff pattern, the two
100×45mm speakers, the 30mm fan, the M3 screw ring, the USB-C and SMA
bulkheads. Only the shape is new, so the two cases are interchangeable on the
same hardware.

This began as a fork of a single-colour kitten design, which has since been
removed — the paws and tail here are about 15% larger than they were in it,
because at two colours they stop being a silhouette detail and become the
thing the eye lands on. `stand.stl` is the whole stand as one piece if you
want it in a single filament.

## Parts

The head is one colour and prints as before:

| part | colour | what it is |
|---|---|---|
| `shell` | black | the head — body cylinder plus two ears, and all the internals |
| `front_trim` | black | the face — bezel ring with a nose, whisker grooves and seven screw holes |
| `retainer` | — | ring behind the glass (identical to the retro part) |
| `back_plate` | black | removable back — locating lip, standoffs, vents, one USB-C pass-through, antenna-mount inserts |
| `antenna_mount` | black | bolt-on arm carrying the antenna socket |
| `antenna_mount_sma` | alternative mount: same flange, arm and counter-tilt, ending in a panel-mount SMA jack instead of a socket cut for one antenna's base |
| `antenna_mount_twin` | **the one to print for the FlyCatcher:** same flange and three bolts, ending in a crossbar with two SMA jacks 80 mm apart, for the 1090 and 978 MHz whips; counter-tilted so both stand vertical with their hinges straight |
| `usbc_gauge` | — | test coupon: five candidate USB-C cutouts, to fit the connector before printing a plate |

The stand is split into five bodies, one per colour region:

| part | colour | what it is |
|---|---|---|
| `stand_body` | **black** | plinth, cradle arms, keel |
| `stand_paws` | **white** | both foot pads |
| `stand_toes` | **black** | the eight toe lobes |
| `stand_claws` | **white** | eight real claws, one per toe |

`kitten-stand-twotone.3mf` is all six of the above in one project file with
the filaments already assigned — the easiest way in, and the one that avoids
the multi-lump selection problem described under *Printing it in two colours*.
| `stand_tail` | **black** | the tail from root to the white tip |
| `stand_tail_tip` | **white** | the flicked-up end |

`stand` is the whole stand as one piece, the same shape in a single
filament — useful if you are not printing in two colours, and it is also the
reference the five coloured parts are checked against.

## The back comes off, and carries the antenna

The back used to be a fixed floor with the electronics standing on it, so the
only way in was through the glass. It is a separate plate now, screwed to
eight insert posts exactly as the faceplate is.

**This plate is the same part as the retro build's**, and so is the antenna
mount. Both cases are the same 223.34mm diameter, use the same eight-post
ring, and lean back by the same 18°. That is checked rather than asserted:
exported from each design, the two back plates are 15,410 facets that compare
equal as sets — the same solid, differing only in triangle order.

A rib on the inner face drops into the bore so the plate lands centred and
square and holds itself there while the screws go in, with a 1.2mm chamfer on
its outer top edge so it finds its own centre. It is eight arcs rather than a
ring: the insert posts span r=102.2–111.2 against a bore wall at
r=108.7–111.7, so they straddle the wall and a continuous ring would run
through all eight. Three checks hold it — `lip_present` as a positive
control, `lip_clears_posts`, and `lip_inside_bore`, since a lip larger than
the bore does not locate anything, it just stops the plate seating.

The two cable glands are gone, replaced by a single opening for a panel-mount
USB-C cable; the antenna's coax comes in through the mount's own bore
instead. **The cutout has been fitted to the real
connector** (2026-09-29): it fits, its two M3 mounting screws are 16.5mm
apart, and the holes are M3 clearance. For a different connector, print
`usbc_gauge`, a coupon carrying the cutout plus four neighbours at ±0.5 and
±1.0mm, and fit it before committing a plate.

The mount screws into three M3 heat-set inserts on the plate's inner face
rather than through bare holes, so it can be removed without holding a nut
inside the case. The insert pocket stops on a shoulder 1mm above the plate so
the insert cannot be pressed too deep. The bolt circle is clocked 30° off
vertical for clearance, not looks: at 0° one boss reaches y=106.5, into the
locating lip at 106.3.

The upper vent moved from y=+68 to y=−68. The mount's flange is a 40mm disc
centred at y=88, so at +68 the grille sat underneath it from y=68 to y=81,
venting into the back of a solid disc — which is what prompted this.
`vents_clear_of_mount` holds the new position, and `vents_were_under_mount`
is its paired control, finding the 257mm³ overlap the old one had.

The Pi is mounted to the LCD panel rather than to those standoffs, so taking
the plate off exposes the back of the Pi and its cabling rather than removing
it. **There is no fan mount** — the fan goes on the Pi. The two grille
patterns stay as plain vents.

The antenna mounts on the back of the plate rather than on a turret, since a
turret out of a cat's skull is a spike. It is a **bolt-on**: three M3 bolts
on a 30mm circle. That keeps both parts flat and support-free on the bed, and
lets the antenna angle change later without reprinting the tray. The cable
drops out of the socket and runs straight through the arm, the flange and the
plate into the case.

The mount sits inside the head's outline and cannot be seen from the front;
only the antenna shows, rising between the ears.

### Why the arm reaches straight back before the barrel rises

The arm goes **back** from the plate, and only then does a barrel rise from
its end along the antenna's own axis. That two-stage shape is forced, not
styled. A barrel coaxial with the antenna and rooted on the plate would have
to climb toward the head the whole way and would run into it.

The first attempt avoided that by hulling a pad on the plate to a disc at the
socket — which produced a *cone* with the socket bored into its flank, so the
antenna pointed sideways and down rather than up. A stub plus a barrel gives
a real cylindrical socket with a flat face square to the antenna.

The arm is 30mm because that is what the clearance costs. Swept against the
antenna's own envelope: at 22mm it fouls the head's top rim even at nominal
diameter, at 26mm it clears nominal but not +2mm, and at 30mm it still clears
with 6mm of radial slack. `antenna_clears_head` holds it.

## The plate fits one way only

The plate's locating rib is eight identical arcs between eight evenly
spaced posts, so it used to seat at any of eight positions 45° apart, and
only one of them puts the antenna mount at the top. A small block on the
shell's bore wall at 247.5° (lower left, between the posts at 225° and 270°)
now meets a matching notch in one arc of the rib: upright, the plate drops
in; turned to any other position, the block lands on the rib and the plate
stands proud before a screw goes in. It sits well clear of the antenna-mount
bosses at the top and the USB-C window, and both shells put it at the same
angle, so the one plate still fits both cases.

`key_fits` proves the upright plate meets the block with no volume, and
`key_blocks_45` … `key_blocks_315` prove each of the other seven positions
collides (43.7 mm³ each), each as its own check, because a key that blocked
only some angles would still let the plate in wrong.

## Printing it in two colours

The five stand bodies share one coordinate frame, so they occupy their true
positions relative to each other. That gives you two routes:

**Multi-material (AMS, MMU, tool changer).** Open
`kitten-stand-twotone.3mf`. It is the whole stand as one object with the six
bodies already inside it and a filament already assigned to each — nothing to
position, nothing to select.

That file exists because loading the STLs separately does not work well, for
a reason that is not obvious. Three of the bodies are physically several
disconnected lumps: two paws, two clumps of toes, and eight separate claws,
because that is what the shapes are. Slicers split a multi-lump mesh into
separate parts on import, so picking a filament for "the claws" colours **one
claw** and leaves the other seven — which looks like the tool ignoring you.
There is no way to fix that from the STL side; eight claws cannot be one
connected lump. So the assignment lives in the project file instead.

The filament slots are 1 for the black (body, toes, tail), 2 for the white
(paws, tail tip) and 3 for the claws, kept on their own slot so they can be a
third colour. Change any of them in the slicer.

If you would rather load the STLs by hand anyway: load the first, then "add
part"/"load as part" for the rest, which preserves their positions, and
assign a filament to each.
No supports needed for the paws or toes; the tail tip lifts off the paw and
wants a little support under the flick.

**Single extruder.** Print them as separate objects and glue. Every split
follows a real seam in the shape — pad to toe, tail to tip — so the joins
land where the eye already expects a line. Print `stand_body` flat on its
base; the paws, toes and tail parts are all small and sit stably on their cut
faces.

### Why the parts overlap slightly

The bodies deliberately interfere by 0.3mm (`colour_overlap`) along every
seam, and the first version of this design got that exactly backwards.

Cutting each part with the precise shape of its neighbour is the tidy answer
and it is the broken one. It produces a perfect partition — zero shared
volume — while leaving the two bodies sharing a *surface* at identical
coordinates. No renderer can decide which of two faces at the same depth is
in front, so the slicer stipples the seam with the other colour: a white paw
arrives speckled black, worst over the buried half of the paw where the
shared area is largest.

So each part is cut with a slightly inset copy of whatever takes precedence
over it, leaving a thin shell of shared material instead of a shared surface.
Nothing is coplanar, and the colour boundary moves by at most 0.15mm — a
fifth of a nozzle width, so which body a slicer awards the shell to cannot be
seen in the print.

The tail needed the opposite treatment. Its two parts are runs of the same
tapering tube, so wherever they overlap they carry the same outer skin —
and an overlap of identical skin is the very coincidence being avoided.
There the tip is grown rather than the body shrunk, so over the shared
stretch the white tip sits 0.15mm proud of the black tail it continues.

## The whisker grooves

Three short arcs engraved into the bezel face either side of the nose.

They were briefly in the wrong place, and it is worth recording how. The
nose sits at −y, the bottom of the face; the grooves were rotated about 0°
instead — the right-hand side — so all six landed 90° from the nose they
were meant to flank. That printed before anyone noticed, as six unexplained
indentations down one side of a faceplate.

They are now placed off `nose_angle` rather than a literal, and each sweeps
away from the nose so the two sides mirror. `whisker_off_nose` in
`checks.scad` pins it: the grooves must lie entirely within a 90° wedge
centred on where `nose()` actually puts itself. That wedge is written as a
literal 270 on purpose — deriving it from `nose_angle` would make the check
vacuous, since moving the angle would move the wedge along with the grooves.

## Where the colour goes, and why

- **Paws white, toes black.** The toes are the detail that makes a paw read
  as a paw, and they are small — they need the contrast more than the pad
  does. The clefts between them grew with the toes; the groove is the only
  thing making four toes read as four rather than one lumpy pad.
- **Claws are their own body, and they are real geometry.** The grooves
  between the toes were being read as the nails; they were never that — they
  are the only thing making four toes read as four. There are now eight
  actual claws, one off the front of each toe, following that toe's splay and
  drooping toward the desk the way a cat's does. Their base sits *inside* the
  toe rather than butted against it: a spike joined at a tangent point is a
  weak spot in the print, and a butted joint would share a surface with the
  toe, which is the coincidence that stipples the preview. The tip stops
  clear of the desk on purpose — claws that reached z=0 would carry the
  stand's weight on eight little points and rock, which `claws_off_the_desk`
  holds. `claws_stand_proud` is the paired positive control: a claw entirely
  buried in its toe passes every seam and volume check while being invisible
  on the print, which is exactly what the grooves-as-nails problem looked
  like.
- **Tail black, tip white, and the tip lifts.** The first version had the tip
  resting flat on the pad, which is what a sitting cat does — but that put a
  white tip on top of a white paw, where it vanished. The whole point of a
  white tip is that it reads against what surrounds it. Lifted, it is
  silhouetted from every angle, and a flicked tail tip is cat-like anyway.
  This was caught by rendering it and looking, not by any check.

## Smoothness

Curve resolution is set by `$fs` (0.4mm) and `$fa` (0.5°) in the `.scad`,
not by a fixed facet count.

A fixed count was what this had, and it makes the flats grow with the
feature — so the biggest, most looked-at surfaces come out roughest. At the
old `$fn = 96` the head's 223mm rim carried **7.3mm flats** and the cradle
8.2mm, while every 3mm screw hole also got 96 sides it had no use for. `$fs`
caps the chord — the width of one flat, which is what the eye reads as
faceting — so a large curve gets the facets and a small hole does not. The
head is now at 0.97mm and every sphere in the paws, toes and tail at 0.4mm,
which is one extrusion width: below that a 0.4mm nozzle cannot reproduce the
difference.

The meshes are exported as **binary STL**. At this resolution the stand is
173,000 facets, which is 52MB as ascii and 8.3MB as binary for byte-identical
geometry. Every slicer reads both.

`tail_smooth_steps` is the other half of it. The tail is hulls between
consecutive spheres, so every sphere leaves a crease running around the
tube. At the old resolution those creases were masked by the general
faceting; once the circumference was smooth they read as rings. 14 points
per control segment puts a joint every 2.4mm instead of 5.6mm, for about a
megabyte.

To go finer, lower `$fs` — but check the file sizes, because sphere cost
grows as the square.

**`use <>` does not carry `$fa`/`$fs`.** It imports modules and functions
only, so `checks.scad` and the preview files set them again at the top. Miss
that and they silently render at OpenSCAD's defaults, showing a faceting the
exported mesh does not have — or, worse, validating geometry that is not what
gets printed.

## Seven screws, not eight

The bezel has seven screw holes. There is an eighth insert post in the shell
at the same angle as the nose, and the nose stands on top of it — 2.6mm of
solid capping the hole, so that screw could never have been fitted. Rather
than leave a hole that cannot take a screw and reads as a moulding defect
under the chin, it is not cut at all.

The shell keeps all eight posts. An unused boss is invisible from outside and
keeps that part identical to the retro build it was copied from.

Found by probing the screw ring after a faceplate had already been printed.
`nose_screw_removed` now proves the hole is absent, and `other_screws_present`
is its paired positive control — an empty result from the first would also be
what a probe in the wrong place produces, so a probe at a normal position has
to find a real hole for the pair to mean anything.

## Heat-set inserts

Every screw that gets undone goes into a brass M3 heat-set insert. The holes are sized for the Kadrick M2–M5 kit: its M3 inserts are 4.5 mm across the knurl and 3.9 mm at the lead-in. Every insert hole is **4.0 mm**, so the lead-in drops in square and the knurl melts 0.25 mm a side into the plastic. (They were 4.2, which left a 4.5 mm insert only 0.15 mm of bite.)

| Where | Count | Insert | Screw | Notes |
|---|---|---|---|---|
| Front posts in the shell (front trim and retainer screw into these) | 8 posts, 7 used | M3 × 5 | M3 × 14 | Pressed from the front, flush with the shelf the retainer sits on |
| Back posts in the shell (back plate screws into these) | 8 | M3 × 6 | M3 × 8 | Pressed from the back face, flush |
| Antenna mount flange | 3 | M3 × 5 | M3 × 8 | The pocket is in the mount; the screws come from inside the case, through the back plate |
| Speaker bosses (optional) | 8 | M2 × 3 | M2 × 6 | The 2.6 mm pilot takes an M2 insert or the speaker's self-tapping screws |

**The front posts are new.** They used to be only 2 mm tall: an insert sat in 2 mm of plastic with open air under it and the wall on one side only (measured: a third of the ring round it was solid). Now each post hangs 8 mm below the shelf, merged into the wall, with a 45° cone under it so it prints without support. The holes are cut after the whole shell is unioned, so the speaker brackets at 0° and 180° can't fill them.

- `front_inserts_surrounded` proves every front insert has a 1.75 mm ring of plastic all round it for its full length. Run against the old shell, it finds 545 mm³ missing.
- `front_insert_holes_open` is its positive control.

The kitten's bezel has seven screws (see *Seven screws, not eight*). The post under the nose needs no insert.

**Pressing them:** a soldering iron with an M3 insert tip, at about 220 °C for PLA or 245 °C for PETG.
1. Start the insert square in the hole.
2. Let it sink under its own weight plus light pressure. Don't push hard.
3. Stop when it is flush.
4. Hold a flat, cool piece of metal on it for a few seconds while the plastic sets, so it stays square.

### The twin mount: 1090 and 978 MHz

The FlyCatcher has two antenna inputs, 1090 and 978 MHz, and the Nooelec bundle has a hinged whip for each. `antenna_mount_twin` holds both.
- **Same base as the others:** the flange and three bolts, so nothing else changes.
- **A crossbar** with a bulkhead jack at each end, 80 mm apart. Antennas this close in frequency detune each other when bunched together.
- **Counter-tilted,** like the single mounts, so the whips stand vertical with their hinges straight. Hinges hold firmly only at their stops, and part-way they sag over time.

**Cables:** two SMA male to SMA female bulkhead jumpers, RG316, about 30 cm (SMA, not RP-SMA). The small right-angle pigtails in the antenna bundle are MCX, for Nooelec's USB sticks, and aren't used.

**Fitting the cables:** thread each one plug-first, down its tower, along the tunnel in the crossbar, down the arm, and through the back plate's 11 mm hole. Then push the bulkhead up through its tower's panel and put the nut on top. The 1090 whip is the shorter one.

**Checks:**
- `twin_plug_path_clear`: an SMA plug's width is open along the whole route. A probe 12.5 mm across, too fat for the bore, does hit it.
- `twin_antennas_clear_case`: both whips, swept 220 mm up, miss the case (and the kitten's ears). The same envelopes moved 60 mm down do hit it.
- `twin_vs_plate`, `twin_vs_stand`: no collisions with the back plate or the stand.
- `twin_panels_present`, `twin_holes_open`: positive controls; the panels are there and the jack holes are open.

## Checks

`sh run-checks.sh` runs every target in `checks.scad` and reports the
**volume** each produces.

Volume, not facet count. A boolean between parts that touch leaves
zero-thickness films along the boundary — thousands of facets and no volume —
so counting facets calls a correct model broken. The threshold is 1mm³
against a paw of roughly 27,000mm³, and a real interference has nowhere to
hide in that gap.

Volume alone is not enough either, which is what the speckled first version
proved: a shared surface has no volume at all. That is what
`check-coincident.py` below is for.

Alongside the fit checks on the head and cradle, the colour split adds:

- `material_lost` — must be **zero**: a region of the one-piece stand that no
  coloured part claims. That would print as a hole.
- `material_gained`, `paws_vs_toes`, `body_vs_paws`, `tail_vs_tip` — must be
  **small but non-zero**: these are the colour seams, and zero here means the
  parts share surfaces instead of overlapping, which is the speckling bug.
  Bounded at 1500mm³, which is 0.15mm of thickness over 10,000mm² of shared
  surface — far more than these parts have.
- `canary` — must produce geometry. Without it, a typo in the `use <>` path
  makes every check above pass against nothing, which has happened here
  before.

`check-coincident.py` makes the check the volume tests cannot: it compares
the exported meshes face by face and counts triangles two parts have at
identical coordinates. Two parts sharing a surface have zero shared volume
and still stipple, so nothing about that bug is visible in a volume
measurement. All ten pairs must come out at zero. With the overlap disabled
(`-D colour_overlap=0`) the same check reports 3,502 shared faces between the
paws and the toes, which is precisely the speckling.

Run everything with `sh run-checks.sh`, which also runs the coincidence
check.

## Regenerating

```sh
for p in shell front_trim retainer stand back_plate antenna_mount usbc_gauge \
         stand_body stand_paws stand_toes stand_claws stand_tail stand_tail_tip; do
  openscad --backend=manifold --export-format binstl \
           -D "part=\"$p\"" -o "$p.stl" kitten-enclosure-twotone.scad
done
```

**The exporter is not deterministic.** Two consecutive exports of unchanged
source differ — 135 facets out of 210,448 on the stand, and even the facet
count moves (210,758 vs 210,448 across runs). It shows up on the stand and
not on the simple parts, which is consistent with it coming from the hundreds
of hulls the paws and tail are built from. Two consequences: re-exporting
everything makes the stand files show as modified whether or not anything
changed, so only re-export what actually changed; and comparing two STLs byte
for byte is not a test of whether they are the same shape — compare the
triangle sets instead.

The `.stl` files are committed alongside the source so the folder is
self-contained, but they are generated. Change the `.scad` and both must be
re-exported and committed together, or the mesh quietly stops matching the
source it claims to come from.

### The connector has to fit through, not just the cable

The bore was 9mm and the coax **connector** is 9.15mm across its widest
point, so it did not pass at all. Worse, the straight bore is cut along the
plate's normal while the socket above it is tilted by `stand_angle`, so the
two were not coaxial and the socket floor met the bore at an angle — leaving
a shoulder across the opening for the antenna's base to land on. Widening the
bore alone would not have removed that; it is a consequence of the two axes
disagreeing.

The socket floor is now opened square to the **antenna's** axis and hulled
down onto the straight run, so there is one continuous passage with no step
anywhere across it. `connector_passes` sweeps a 9.15mm plug gauge along that
path and must touch nothing; `connector_gauge_works` is its paired control,
an oversized gauge that must be caught. Swept by hand the passage clears
10.5mm and blocks at 11.0mm, so the connector has 1.35mm of margin.

Note for anyone tuning this: `-D` on the command line reaches `echo` but not
the CSG tree for these files, so a gauge sweep driven by `-D` silently
measures the file's own value at every step and reports that everything
passes. Edit the number instead.

### The antenna socket, and the lip that holds the base

The socket was Ø33 and a printed mount would not take the antenna at all: the
base is a flared cone slightly wider than that where it has to pass, so it
never got under the rim. It perched on top and tipped over — while the cable
underneath ran through perfectly, which is the part that had been checked.

Then the second printed one had its **rim snap off** while a base was being
levered under it, which says the approach was wrong and not just the number.
A 2mm chamfer left 2.5mm of wall at the edge, and a printed rim that thin,
pried outwards across its layer lines, is weak. Stiffness goes as thickness
cubed, so the barrel went 45 → 48 and the chamfer 2 → 1.2mm: 4.8mm of wall at
the edge, roughly seven times stiffer.

The deeper point is that **the base is held by depth, not by an overhang**.
The socket is 8mm deep, the antenna sits down inside it, and the chamfer is a
lead-in for a base that is already smaller than the hole — not a ramp for
forcing an oversized one past. If it has to be levered, the socket is too
small; make it bigger rather than pushing harder.

### What was actually stopping it, after three wrong guesses

The base measures **31.25mm across its flared bottom**, and **the lead leaves
the SIDE of the base 7.98mm above it** — both measured. The original socket was
Ø33, already 1.75mm of clearance, so *the bore was never what stopped it*, and
three attempts to fix the bore were fixing the wrong thing: that the base was
wider than the hole, that it was a cone flaring above a narrow bottom, that
the connector needed room beneath. None of them were true.

With the base seated, the lead is 7.98mm above the socket floor — and it
cannot go down through that floor, because the base is sitting on it. It has
to leave sideways. The printed mount gave it nowhere to go, so the connector
ended up jammed in the notch where the cable passage happens to break through
the wall, holding the base up at an angle. That notch was an accident of the
geometry; there is now a deliberate slot, 7mm wide, running from the floor up
past the rim.

It faces local +Y in the antenna's frame, which works out to world
(0, +0.309, −0.951) — down and back toward the plate — so the lead drops
straight into the passage that was already there instead of being led around
the barrel. `cable_slot_open` checks a rod at the measured exit height passes
out through the wall, and `cable_slot_other_side` is its control: the same rod
on the far side must be blocked, or "the slot is open" would be
indistinguishable from "the probe missed the mount".

`socket_takes_base` holds it, with `socket_gauge_works` as its paired control.
Its first version was wrong in a way worth recording: it ran a full-diameter
disc 12mm into the air above the mouth and failed at 283mm³, which was the
arm alongside. A 35mm cylinder held 12mm above the socket really does overlap
the arm — and means nothing, because the base is a cone that narrows and comes
in from outside. The question is whether the base fits the socket.

## Two antenna mounts, and which to print

`antenna_mount` holds the antenna itself: a 33mm socket cut around the
FlightAware desktop puck's 31.25mm base, with a slot for the lead that leaves
the side 7.98mm up. It fits that antenna beautifully and nothing else, which
makes the case choose the antenna.

`antenna_mount_sma` inverts that. Same flange, same three bolts into the same
inserts, same counter-tilt -- only the far end changes, to a panel-mount SMA
jack. Anything with an SMA plug now works: the same puck, a tuned whip
standing straight off the back, or coax running to an antenna somewhere with
a view of the sky. Swapping it is three screws; the back plate and both
shells are untouched.

Print the SMA one unless you specifically want the puck held on the case.
Measured on this hardware, an indoor puck saw **1 aircraft** while a properly
sited antenna saw **14 of the same sky at the same moment** -- so the ability
to put the antenna somewhere else is worth more than any mount that holds it
here.

The counter-tilt is the part not to touch. ADS-B is vertically polarised, and
`ant_axis_frame()` is what keeps the jack vertical while the case leans back
18 degrees in its cradle.

Four things are checked rather than assumed, and the interesting one is
`sma_passage_joins`: the cavity behind the jack has to actually meet the
cable bore, or the jack threads into a sealed pocket and the coax has nowhere
to go. That failure is invisible in preview -- both volumes are cut, the part
looks hollow, and the wall between them only exists in the print.

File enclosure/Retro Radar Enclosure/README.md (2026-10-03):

# Retro radar enclosure

The 3D-printable case for the retro build, as a single parametric
OpenSCAD source. Everything is driven from the measured values at the top of
[`retro-enclosure.scad`](retro-enclosure.scad) — change those and
the rest follows.

## Parts

| part | what it is |
|---|---|
| `shell` | the body: Pi, dongle, wiring, speakers |
| `front_trim` | bezel in front of the glass, rabbeted so it seats flush |
| `retainer` | ring behind the glass; the glass rests on its front face |
| `stand` | desk cradle — two ring-arc arms on a plinth with two ridges all the way round, standing 4mm proud so the slicer supports their undersides (BambuStudio skipped the old 1mm strips and they printed rough) |
| `back_plate` | removable back — locating lip, PCB standoffs, both vent grilles, one USB-C pass-through, antenna-mount inserts |
| `antenna_mount` | bolt-on arm carrying the antenna socket (identical to the kitten's) |
| `antenna_mount_sma` | alternative mount: same flange, arm and counter-tilt, ending in a panel-mount SMA jack instead of a socket cut for one antenna's base |
| `antenna_mount_twin` | **the one to print for the FlyCatcher:** same flange and three bolts, ending in a crossbar with two SMA jacks 80 mm apart, for the 1090 and 978 MHz whips; counter-tilted so both stand vertical with their hinges straight |
| `usbc_gauge` | test coupon: five candidate USB-C cutouts, to fit the connector before printing a whole plate |

Two extra targets, `test_antenna` and `test_speaker`, clip the real shell
geometry to a small box so a fit test prints in minutes instead of hours.

## Rendering and exporting

Set `part` at the top of the file, or override it from the command line:

```bash
openscad --backend=manifold --export-format binstl \
         -D 'part="shell"' -o shell.stl retro-enclosure.scad
```

Binary STL: the shell is 75,000 facets, which is far smaller as binary than
as ascii for byte-identical geometry, and every slicer reads both.

`part="preview"` shows the whole stack assembled; `part="exploded"` separates
it.

Exporting an STL already forces a full geometry evaluation, and OpenSCAD
prints the result on stderr — check for `Status: NoError` and the
`Top level object is a 3D object (manifold)` line before printing. (Earlier
notes here said to pass `--render`; as of OpenSCAD 2026.06 that flag takes an
argument and a bare `--render` just prints the usage text, so a script using
it silently exports nothing.)

## Things that are easy to get wrong

These are all mistakes that were actually made and fixed here, kept as
warnings rather than as history:

- **`glass_thickness` is the glass sheet alone (1.62mm), not
  `panel_glass_depth`** (6.45mm, the whole panel module). The rabbet spans
  the glass; using the module depth leaves a gap you have to squeeze shut.
- **The antenna mount is counter-tilted forward by `stand_angle`.** The case
  leans back by that same angle in the cradle, so the two cancel and the
  antenna ends up vertical. Get the sign wrong and it is off by double.
- **The cradle only cups the case; the retention rails are what hold it.**
  With the bowl's axis tilted, gravity pushes the case straight down that
  axis, and nothing else opposes it.
- **Speaker brackets must be clipped to the outer cylinder.** They are flat
  slabs across a curved wall, so their corners otherwise punch through it.
- **Grille holes have to cut through the bracket as well as the wall**, or
  they dead-end in solid plastic and no sound gets out.

## The back comes off

The back used to be a fixed floor with the electronics standing on it, which
meant the only way to a Pi was through the glass. It is a separate plate now,
screwed to eight insert posts exactly as the faceplate is, and everything
that stood on the floor went with it. Undo eight screws and the tray lifts
out as one assembly.

**This plate is the same part as the kitten's.** Both cases are the same
223.34mm diameter, both use the same eight-post ring, and both lean back by
the same 18°, so one plate and one antenna mount serve both builds. That is
checked rather than asserted: exported from each design, the two meshes are
15,410 facets that compare equal as sets — the same solid, differing only in
triangle order.

**There is no fan mount.** There was a plate standing perpendicular to the
tray carrying a 30mm fan; the fan goes on the Pi instead. `fan_mount()` and
its variables are left defined but unused — the same treatment the wall-mount
keyhole code above gets — so putting it back is a one-line change. Both
grille patterns stay as plain vents.

The insert holes are drilled in `shell()`'s difference stage rather than
inside the post module. The speaker brackets reach the wall at 0° and 180°,
exactly where two of the posts stand, so a hole subtracted inside the module
gets unioned shut again by the bracket landing on top of it — two of the
eight would have printed solid. `back_inserts_open` is the check that holds
this, and it is a positive control: it has to *find* eight open bores.

### The locating lip

A rib on the plate's inner face drops into the bore, so the plate lands
centred and square and stays put while the screws go in, instead of being
juggled against eight holes at once. The outer top edge is chamfered by
1.2mm so it finds its own centre rather than catching square.

It is eight arcs, not a ring. A continuous ring at bore diameter is the
obvious shape and it is unbuildable here: the insert posts span r=102.2–111.2
and the bore wall is r=108.7–111.7, so the posts straddle the wall and a ring
would run through all eight of them. One arc per gap between posts locates
just as well — three points fix a circle and this has eight.

Three checks hold it, because a single "does the plate fit" test passes just
as happily when the lip is missing: `lip_present` (a positive control — it
must find the lip at all), `lip_clears_posts`, and `lip_inside_bore`, since a
lip larger than the bore does not locate anything, it just stops the plate
seating.

### One pass-through, not two

The USB-C power gland and the SMA antenna gland are replaced by a single
opening for a panel-mount USB-C cable. The antenna no longer needs a bulkhead
here at all — its coax comes in through the antenna mount's own cable bore,
inside the bolt circle.

**The cutout has been fitted to the real connector** (2026-09-29): it fits
the window, and its two mounting screws are 16.5mm apart. Those screws are
M3, so the holes are M3 clearance (3.4mm) like every other screw hole. The
listing publishes no cutout size, so for a different connector print
`usbc_gauge` — the cutout plus four neighbours at ±0.5 and ±1.0mm — and fit
it before committing a back plate. A coupon is minutes; a plate is hours.

### The plate fits one way only

The plate's locating rib is eight identical arcs between eight evenly
spaced posts, so it used to seat at any of eight positions 45° apart, and
only one of them puts the antenna mount at the top. A small block on the
shell's bore wall at 247.5° (lower left, between the posts at 225° and 270°)
now meets a matching notch in one arc of the rib: upright, the plate drops
in; turned to any other position, the block lands on the rib and the plate
stands proud before a screw goes in. It sits well clear of the antenna-mount
bosses at the top and the USB-C window, and both shells put it at the same
angle, so the one plate still fits both cases.

`key_fits` proves the upright plate meets the block with no volume, and
`key_blocks_45` … `key_blocks_315` prove each of the other seven positions
collides (43.7 mm³ each), each as its own check, because a key that blocked
only some angles would still let the plate in wrong.

### The antenna mounts on the back, and the turret is gone

The turret grew the socket out of the top of the case wall. The socket now
lives on a bolt-on arm on the removable plate, which is the same part the
kitten build uses — so both cases carry the identical antenna assembly, and
the angle can be changed without reprinting a shell.
`antenna_turret_solid()`/`antenna_turret_cuts()` are left defined but unused,
the same treatment the wall-mount keyhole code gets.

`no_turret` holds it, and its first version was wrong in an instructive way:
"nothing may stand proud of `outer_dia`" reported 13,632mm³ of turret that
was actually the decorative rivets and the cradle rails, which stand proud on
purpose out to r=115.7. The turret reached r=128, so the probe sits at 116.67
— outside the rivets, well inside a turret. `turret_probe_works` is its
paired control: the retired turret module has to be *caught* by that same
probe, or an empty result would only prove the probe was set too wide.

### The antenna mount screws into inserts

Three bosses on the plate's inner face take M3 heat-set inserts, so the mount
screws into the plate rather than needing a nut held inside the case while
the bolt is turned outside. The bores are two diameters on purpose: the
insert pocket stops on a shoulder 1mm above the plate rather than running out
through it, so the insert cannot be pressed too deep and the bolt still
passes freely from outside.

The bolt circle is clocked 30° off the vertical, which is not cosmetic. At
the obvious 0° one bolt points straight up the plate, putting its boss at
y=103 with an outer edge at 106.5 — into the locating lip, whose inner face
is at 106.3.

### The vents moved

Both grille patterns stay as plain vents, but the upper one moved from
y=+68 to y=−68. The antenna mount's flange is a 40mm disc centred at y=88, so
at +68 the grille sat underneath it from y=68 to y=81 — venting into the back
of a solid disc. `vents_clear_of_mount` holds the new position and
`vents_were_under_mount` is its paired control, finding the 257mm³ overlap
the old position had.

### Side slots: top only, and cut through

The shell's side slots were cut all the way round. At each speaker, three of them ran across the grille. Underneath, six landed on the cradle's retention rails. None of them were vents: each cut was centred on the outer face, so it went only 2.5mm into the 3mm wall.

Now there are nine, across the top between the speakers (`exhaust_a0`..`exhaust_a1`, 30–150°), and they go right through. That gives the fan's air a way out at the top, where warm air goes anyway.

- `exhaust_top_only` checks that nothing is cut outside that arc.
- `exhaust_reaches_inside` checks that each slot breaks out past the wall's inner face. It finds about 115mm³, about 13 per slot; a blind dent finds nothing.

### Speaker grilles: one clean block each

Each speaker's grille is now only the rows in front of the ribs: five rows of 21 holes. Two things went:

- **The single row between the two ribs.** It read as a stray line of holes, not part of the grille.
- **The three rivets of the front ring that fell on each grille.** They stood up among the holes. The ring keeps its other 18.

These checks hold the change:
- `grille_in_front_of_ribs` and `rivets_clear_of_grilles` must come out empty. Both find the old geometry when run against it.
- `grille_present` and `rivets_present` are their positive controls.

## Heat-set inserts

Every screw that gets undone goes into a brass M3 heat-set insert. The holes are sized for the Kadrick M2–M5 kit: its M3 inserts are 4.5 mm across the knurl and 3.9 mm at the lead-in. Every insert hole is **4.0 mm**, so the lead-in drops in square and the knurl melts 0.25 mm a side into the plastic. (They were 4.2, which left a 4.5 mm insert only 0.15 mm of bite.)

| Where | Count | Insert | Screw | Notes |
|---|---|---|---|---|
| Front posts in the shell (front trim and retainer screw into these) | 8 | M3 × 5 | M3 × 14 | Pressed from the front, flush with the shelf the retainer sits on |
| Back posts in the shell (back plate screws into these) | 8 | M3 × 6 | M3 × 8 | Pressed from the back face, flush |
| Antenna mount flange | 3 | M3 × 5 | M3 × 8 | The pocket is in the mount; the screws come from inside the case, through the back plate |
| Speaker bosses (optional) | 8 | M2 × 3 | M2 × 6 | The 2.6 mm pilot takes an M2 insert or the speaker's self-tapping screws |

**The front posts are new.** They used to be only 2 mm tall: an insert sat in 2 mm of plastic with open air under it and the wall on one side only (measured: a third of the ring round it was solid). Now each post hangs 8 mm below the shelf, merged into the wall, with a 45° cone under it so it prints without support. The holes are cut after the whole shell is unioned, so the speaker brackets at 0° and 180° can't fill them.

- `front_inserts_surrounded` proves every front insert has a 1.75 mm ring of plastic all round it for its full length. Run against the old shell, it finds 545 mm³ missing.
- `front_insert_holes_open` is its positive control.

**Pressing them:** a soldering iron with an M3 insert tip, at about 220 °C for PLA or 245 °C for PETG.
1. Start the insert square in the hole.
2. Let it sink under its own weight plus light pressure. Don't push hard.
3. Stop when it is flush.
4. Hold a flat, cool piece of metal on it for a few seconds while the plastic sets, so it stays square.

### The twin mount: 1090 and 978 MHz

The FlyCatcher has two antenna inputs, 1090 and 978 MHz, and the Nooelec bundle has a hinged whip for each. `antenna_mount_twin` holds both.
- **Same base as the others:** the flange and three bolts, so nothing else changes.
- **A crossbar** with a bulkhead jack at each end, 80 mm apart. Antennas this close in frequency detune each other when bunched together.
- **Counter-tilted,** like the single mounts, so the whips stand vertical with their hinges straight. Hinges hold firmly only at their stops, and part-way they sag over time.

**Cables:** two SMA male to SMA female bulkhead jumpers, RG316, about 30 cm (SMA, not RP-SMA). The small right-angle pigtails in the antenna bundle are MCX, for Nooelec's USB sticks, and aren't used.

**Fitting the cables:** thread each one plug-first, down its tower, along the tunnel in the crossbar, down the arm, and through the back plate's 11 mm hole. Then push the bulkhead up through its tower's panel and put the nut on top. The 1090 whip is the shorter one.

**Checks:**
- `twin_plug_path_clear`: an SMA plug's width is open along the whole route. A probe 12.5 mm across, too fat for the bore, does hit it.
- `twin_antennas_clear_case`: both whips, swept 220 mm up, miss the case (and the kitten's ears). The same envelopes moved 60 mm down do hit it.
- `twin_vs_plate`, `twin_vs_stand`: no collisions with the back plate or the stand.
- `twin_panels_present`, `twin_holes_open`: positive controls; the panels are there and the jack holes are open.

## Checks

`sh run-checks.sh`. Every target must come out with no real volume except
`back_inserts_open`, which must find geometry, and `canary`, which proves
the modules are being found at all — without it a typo in the `use <>` path
makes every other check pass against nothing.

## Smoothness

Curve resolution is set by `$fs` (0.4mm) and `$fa` (0.5°), not a fixed facet
count.

A fixed count makes the flats grow with the feature, so the biggest surfaces
come out roughest. At the old `$fn = 96` this shell's 223mm rim carried
**7.3mm flats** and the cradle 8.2mm, while every 3mm screw hole also got 96
sides it had no use for. `$fs` caps the chord — the width of one flat, which
is what the eye reads as faceting — so a big curve gets the facets and a
small hole does not.

**This is the only design here that has actually been printed**, so the small
fit-critical features keep their own explicit `$fn` and are untouched. What
changed is the geometry that had no explicit setting, plus the four wide
arcs. Measured against the previous meshes, the largest dimensional change
anywhere is **+0.064mm** on the shell's outer diameter — the flats moving
outward toward the true circle, which is the direction that matters — and
every other extent moves by 0.003mm or less. Volumes rise 0.08–0.15%. All of
that is an order of magnitude under print tolerance, so nothing about the
fit changes.

## Generated STLs

Committed alongside the source so the folder is self-contained, but they are
generated. Change the `.scad` and both must be re-exported and committed
together, or the mesh quietly stops matching the source it claims to come
from.

### The connector has to fit through, not just the cable

The bore was 9mm and the coax **connector** is 9.15mm across its widest
point, so it did not pass at all. Worse, the straight bore is cut along the
plate's normal while the socket above it is tilted by `stand_angle`, so the
two were not coaxial and the socket floor met the bore at an angle — leaving
a shoulder across the opening for the antenna's base to land on. Widening the
bore alone would not have removed that; it is a consequence of the two axes
disagreeing.

The socket floor is now opened square to the **antenna's** axis and hulled
down onto the straight run, so there is one continuous passage with no step
anywhere across it. `connector_passes` sweeps a 9.15mm plug gauge along that
path and must touch nothing; `connector_gauge_works` is its paired control,
an oversized gauge that must be caught. Swept by hand the passage clears
10.5mm and blocks at 11.0mm, so the connector has 1.35mm of margin.

Note for anyone tuning this: `-D` on the command line reaches `echo` but not
the CSG tree for these files, so a gauge sweep driven by `-D` silently
measures the file's own value at every step and reports that everything
passes. Edit the number instead.

### The antenna socket, and the lip that holds the base

The socket was Ø33 and a printed mount would not take the antenna at all: the
base is a flared cone slightly wider than that where it has to pass, so it
never got under the rim. It perched on top and tipped over — while the cable
underneath ran through perfectly, which is the part that had been checked.

Then the second printed one had its **rim snap off** while a base was being
levered under it, which says the approach was wrong and not just the number.
A 2mm chamfer left 2.5mm of wall at the edge, and a printed rim that thin,
pried outwards across its layer lines, is weak. Stiffness goes as thickness
cubed, so the barrel went 45 → 48 and the chamfer 2 → 1.2mm: 4.8mm of wall at
the edge, roughly seven times stiffer.

The deeper point is that **the base is held by depth, not by an overhang**.
The socket is 8mm deep, the antenna sits down inside it, and the chamfer is a
lead-in for a base that is already smaller than the hole — not a ramp for
forcing an oversized one past. If it has to be levered, the socket is too
small; make it bigger rather than pushing harder.

### What was actually stopping it, after three wrong guesses

The base measures **31.25mm across its flared bottom**, and **the lead leaves
the SIDE of the base 7.98mm above it** — both measured. The original socket was
Ø33, already 1.75mm of clearance, so *the bore was never what stopped it*, and
three attempts to fix the bore were fixing the wrong thing: that the base was
wider than the hole, that it was a cone flaring above a narrow bottom, that
the connector needed room beneath. None of them were true.

With the base seated, the lead is 7.98mm above the socket floor — and it
cannot go down through that floor, because the base is sitting on it. It has
to leave sideways. The printed mount gave it nowhere to go, so the connector
ended up jammed in the notch where the cable passage happens to break through
the wall, holding the base up at an angle. That notch was an accident of the
geometry; there is now a deliberate slot, 7mm wide, running from the floor up
past the rim.

It faces local +Y in the antenna's frame, which works out to world
(0, +0.309, −0.951) — down and back toward the plate — so the lead drops
straight into the passage that was already there instead of being led around
the barrel. `cable_slot_open` checks a rod at the measured exit height passes
out through the wall, and `cable_slot_other_side` is its control: the same rod
on the far side must be blocked, or "the slot is open" would be
indistinguishable from "the probe missed the mount".

`socket_takes_base` holds it, with `socket_gauge_works` as its paired control.
Its first version was wrong in a way worth recording: it ran a full-diameter
disc 12mm into the air above the mouth and failed at 283mm³, which was the
arm alongside. A 35mm cylinder held 12mm above the socket really does overlap
the arm — and means nothing, because the base is a cone that narrows and comes
in from outside. The question is whether the base fits the socket.

## Two antenna mounts, and which to print

`antenna_mount` holds the antenna itself: a 33mm socket cut around the
FlightAware desktop puck's 31.25mm base, with a slot for the lead that leaves
the side 7.98mm up. It fits that antenna beautifully and nothing else, which
makes the case choose the antenna.

`antenna_mount_sma` inverts that. Same flange, same three bolts into the same
inserts, same counter-tilt -- only the far end changes, to a panel-mount SMA
jack. Anything with an SMA plug now works: the same puck, a tuned whip
standing straight off the back, or coax running to an antenna somewhere with
a view of the sky. Swapping it is three screws; the back plate and both
shells are untouched.

Print the SMA one unless you specifically want the puck held on the case.
Measured on this hardware, an indoor puck saw **1 aircraft** while a properly
sited antenna saw **14 of the same sky at the same moment** -- so the ability
to put the antenna somewhere else is worth more than any mount that holds it
here.

The counter-tilt is the part not to touch. ADS-B is vertically polarised, and
`ant_axis_frame()` is what keeps the jack vertical while the case leans back
18 degrees in its cradle.

Four things are checked rather than assumed, and the interesting one is
`sma_passage_joins`: the cavity behind the jack has to actually meet the
cable bore, or the jack threads into a sealed pocket and the coax has nowhere
to go. That failure is invisible in preview -- both volumes are cut, the part
looks hollow, and the wall between them only exists in the print.

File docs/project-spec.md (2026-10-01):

# StratoScan — Project Spec & Shopping List
*(Pi 5 build, two-wave purchase order)*

A live ADS-B flight radar on a true round 7" display, built custom (not ported), 3D-printed enclosure on the Bambu H2D.

---

## 1. Concept

- Local RTL-SDR receiver picks up real ADS-B signals from aircraft overhead
- A small local web app renders a circular radar UI, full-screen on the round panel
- Runs as a kiosk — boots straight into the display, no desktop, no monitor/keyboard needed after setup
- Pi, dongle, and display all live together in one enclosure on the wall — only a power cord and antenna cable exit it

## 2. Architecture

```
[Antenna] --> [RTL-SDR USB dongle] --> [readsb/dump1090] --> aircraft.json (local)
                                                                    |
                                                                    v
                                          [Small web app: fetch + render]
                                                                    |
                                                                    v
                                    [Chromium kiosk, full-screen] --> [7" round HDMI panel]
```

All housed in one wall-mounted enclosure. Power cord runs down to the nearest outlet inside a paintable cord raceway. Antenna cable runs a short distance to the nearest window.

**Why this is simpler than it sounds:** your panel is HDMI (video) + USB-C (touch as a standard USB input). To the Pi, it's just a monitor. No custom drivers, no ribbon cables, no firmware overlays.

## 3. Purchase Plan — Two Waves

**Wave 1 — validate reception before the big spend (~$168):**
Confirms you actually receive real aircraft at your location before committing to the display.

| Item | Spec | Approx. Price | Buy |
|---|---|---|---|
| Raspberry Pi 5, 8GB | — | $80 | [pishop.us](https://www.pishop.us/product/raspberry-pi-5-8gb/) |
| Official Active Cooler | — | $5 | [pishop.us](https://www.pishop.us/product/raspberry-pi-active-cooler/) |
| Official 27W USB-C PSU | — | $12 | [pishop.us](https://www.pishop.us/product/raspberry-pi-27w-usb-c-power-supply-black-us/) |
| microSD card | 32–64GB, A2 rated | $8 | Amazon, generic is fine |
| FlightAware Pro Stick Plus (RTL-SDR) | Built-in 1090MHz filter/amp, SMA input | $46 | [flightaware.store](https://flightaware.store/products/pro-stick-plus) |
| Basic indoor/window 1090MHz antenna | SMA, short cable | $18 | [Amazon bundle](https://www.amazon.com/1090MHz-ADS-B-Antenna-Filter-FlightAware/dp/B01F8DQV24) |

**→ Checkpoint:** install `readsb`, confirm real aircraft show up in `aircraft.json`. Only proceed to Wave 2 once this is working.

**Wave 2 — the display and finishing hardware (~$195):**

| Item | Spec | Approx. Price | Buy |
|---|---|---|---|
| Waveshare 7" Round LCD | 1080×1080 IPS, HDMI, 10-pt capacitive touch, USB-C | $160 | [waveshare.com](https://www.waveshare.com/7inch-1080x1080-lcd.htm) |
| Short HDMI + USB-C cables (panel to Pi) | — | $12 | Amazon |
| Paintable cord raceway (3–6ft) | For the power cable run to the outlet | $12 | Amazon / hardware store |
| Wall anchors / mounting screws | Skip if you already have some on hand | $10 | any hardware store |
| Filament for enclosure | Matte PLA/PETG, 2 colors via AMS2 Pro | — | you already have this |

**Total: roughly $360–370**

## 4. Software Project Spec (for Claude Code)

**Goal:** a local web app, rendered full-screen in a Chromium kiosk on the Pi, showing a live circular radar of aircraft overhead using local ADS-B data.

**Stack:**
- Backend: `readsb` (or `dump1090-fa`) for signal decoding → serves `aircraft.json` on localhost
- App: single-page web app (plain HTML/CSS/JS), Canvas for the radar — a working prototype of the renderer already exists and proves the circular geometry, sweep animation, and bearing/range plotting
- Display: Chromium `--kiosk` pointed at `http://localhost:PORT`, launched by systemd on boot
- Target hardware: Raspberry Pi 5 (8GB) — comfortable headroom for the renderer, with room to add live map tiles later if desired

**Milestones — build in this order:**
1. **Environment** — flash Raspberry Pi OS, confirm the panel works as a plain HDMI monitor + USB touch device, nothing custom needed
2. **ADS-B pipeline** — install `readsb`, confirm `aircraft.json` is populating with real aircraft; note your home lat/long for range/bearing math *(this is Wave 1's checkpoint)*
3. **Wire up the existing prototype** — replace the prototype's fake `planes` array with a `fetch()` against the local `aircraft.json`, convert lat/lon to bearing/range from home
4. **Live data validation** — confirm real aircraft plot correctly, basic altitude/speed labels
5. **Interaction (optional)** — tap an aircraft for a detail panel
6. **Kiosk + boot** — Chromium kiosk mode + systemd service, auto-restart on crash, comes up clean on power-on
7. **Polish** — color-coded altitude (already in the prototype), plane icons, dark theme matching your enclosure finish

**Hand this section to Claude Code as-is**, along with the existing prototype file, to kick off the build — it's scoped as incremental steps with a visual checkpoint at each stage.

**License:** plan to publish the finished app on GitHub under MIT — the foundation (`readsb`, Raspberry Pi OS, Chromium) is all open source, and this makes your renderer a contribution back rather than just a consumer of it.

## 5. Enclosure Plan (Bambu H2D)

- **All-in-one housing** — Pi, dongle, and cabling live inside the same enclosure as the display; only power and antenna cables exit
- **Bezel ring** — thin, flush frame around the glass edge; this is the part people see, worth the extra print time for a clean fit
- **Rear shell** — houses the Pi 5, RTL-SDR dongle, and cable routing; leave an access panel for the microSD card
- **Cable exits** — two small grommeted openings at the bottom edge: one for power (feeding into the cord raceway), one for the antenna cable
- **Wall mount** — French cleat or keyhole slots printed directly into the rear shell
- **Two-tone option** (AMS2 Pro) — matte black bezel with a thin accent-color ring for a premium finish
- **Ventilation** — a few discreet slots on the rear shell near the active cooler; don't seal it up completely for 24/7 operation

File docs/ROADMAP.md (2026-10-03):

# Roadmap: the five phases

**Baseline:** [v2.0.0](https://github.com/mferris/StratoScan/releases/tag/v2.0.0),
identical to OTA release `2026.09.27.15`. It is the revert point for
everything below.

Progress is tracked as GitHub
[milestones](https://github.com/mferris/StratoScan/milestones) and
[issues](https://github.com/mferris/StratoScan/issues). This file holds
the design decisions those issues depend on.

## Ground rules

- **Open source, license-clean.** Nothing is added without checking its
  license and terms first, and recording it in
  [THIRD_PARTY_NOTICES.md](../THIRD_PARTY_NOTICES.md). Anything
  non-commercial-only (such as RainViewer) is labelled as such.
- **The radar never depends on a cloud service.** The relay (below) adds
  push and fleet health. A unit that can't reach it keeps working exactly
  as it does today.
- **Privacy by default.** The exact home location never leaves the device.
  Anything sent off-device is opt-in, minimal and rounded.
- **No secrets on units.** Gifted units are in other people's houses. Keys
  that can act for the whole fleet (such as Apple's push key) live only in
  the relay.
- **Every fix is verified on the running device**, not just installed.

## What to buy

The parts each item needs are in [SHOPPING.md](SHOPPING.md).

## Architecture: the relay

One small **Cloudflare Worker** (`relay/`) with a D1 database. It is the
only server the project runs.

```
unit ──(signed heartbeat, events)──▶ relay ──(APNs)──▶ iPhone / Watch
unit ◀────(nothing: units only ever call out)──────────┘
phone ──(pairing, notification rules)──▶ relay
```

- **Unit identity:** each unit generates an Ed25519 keypair at install, and
  signs every request with it. The relay stores public keys only. Nothing
  shared or fleet-wide is baked into images.
- **Pairing:** the unit's screen shows a QR code with its ID plus a
  one-time pairing secret (valid 10 minutes). The phone scans it, and the
  relay links that phone's push token to the unit.
- **Heartbeat (opt-in):** every 6 h the unit sends its version, uptime,
  receiver health, SD wear estimate and last-error class. **No location.**
  A fleet page shows the maintainer every unit's health.
- **Events:** the unit decides locally what matters (notable aircraft,
  emergency squawk, low overhead…) and posts a small event. The relay fans
  it out to paired devices over APNs. Payloads carry aircraft data only,
  never the home location: identity, type, altitude, and distance rounded
  to half a nautical mile with a compass direction. That still hints where
  a unit is, so events are off until the owner pairs a phone, and the relay
  keeps them only 48 hours. A factory reset turns them off.
- **Failure mode:** if the relay is down, units keep a short queue, drop it
  on overflow, and the radar is unaffected.

## Phase 1: reliability you can see

| # | Item | Done when |
|---|---|---|
| 1.1 | RTC battery support: installer sets `dtparam=rtc_bbat_vchg` when a rechargeable cell is fitted; clock health in status | A unit keeps correct time across a power cut with no network |
| 1.2 | Storage off the SD card: NVMe boot via the Pi 5 M.2 HAT+ (or CM5 eMMC). Migration script, enclosure fit, installer checks | A unit boots and runs from NVMe; the enclosure fits |
| 1.3 | Relay foundation: Worker, D1 schema, signed-request auth, heartbeat endpoint, fleet status page | Deployed; tests pass; RDU's heartbeat shows on the fleet page |
| 1.4 | Unit side: keypair generation, opt-in heartbeat (setup toggle), sent every 6 h | RDU reports; turning it off stops it |
| 1.5 | Factory image: pi-gen build in GitHub Actions (Arm runner); first boot runs the installer; GPL source offer for readsb/tar1090 included | A fresh SD flashed from the release boots to the setup hotspot |
| 1.6 | Re-measure SD writes after the storage fixes (scheduled 2026-09-28) | Result recorded; any remaining large writer fixed |
| 1.7 | Recover a hung radio without a human: the watchdog power-cycles USB (uhubctl) before it reboots, since a Pi 5 reboot keeps USB powered | A hung SDR comes back on its own on a real unit |
| 1.8 | Core feed on the device: one service merges the antenna's and the network's aircraft, labels them once (operator, type, route, owner, notable), caches the lookups, and serves `/api/aircraft` to every screen; no antenna-relative fields | Live on RDU; labels match the kiosk's on a recorded sample |
| 1.9 | Kiosk and public page read the core feed; route and owner lookups move off visitors' browsers onto the unit | Same picture as before; public visitors no longer contact adsb.im or adsbdb |
| 1.10 | ~~`events.py` reads the core feed;~~ the copied classification tables are deleted. **Done 2026-09-30:** the tables are shared from `labels.py`; `events.py` stays on readsb's `aircraft.json` on purpose (it needs the antenna-relative fields, and alerts shouldn't depend on the core feed) | Same alerts from the same fixtures, with no tables of its own |
| 1.11 | Cut the radar's drawing cost: static layers drawn once, the sweep rotated by the compositor, only moving things redrawn | Measured on RDU: the GPU process well under half its current ~94% of a core, and cooler |
| 1.12 | Visitor counts for each radar's public page, for its owner: views, unique visitors (a daily-salted hash, never stored), the owner's app counted apart, hour of day, device type, referring site; no cookies, no stored addresses; on the radar's screen, setup page and app (#50) | Visits from a phone on mobile data show within a minute; nothing stored holds an address |
| 1.13 | Fleets with their own administrators on the relay: radars join by their owner's invite code and can leave any time; administrators see health and visit counts per radar and in total, never locations, phones or alerts; per-administrator sign-in (#51) | The family fleet with RDU in it; a second fleet sees none of it |

## Phase 2: the pocket

| # | Item | Done when |
|---|---|---|
| 2.1 | Relay push: APNs token auth, fan-out, per-phone rules, rate limits | A test event reaches a real iPhone |
| 2.2 | Unit events: notable / emergency / low overhead / helicopter, decided on the unit and queued to the relay | Events arrive for real traffic at RDU |
| 2.3 | QR pairing on the device screen, and in the app | Pair and unpair with a phone, end to end |
| 2.4 | iOS app v2: notification rules, home and lock-screen widgets, Live Activity (inbound overhead), StandBy radar | Each feature working on a real phone |
| 2.5 | iOS app v2: away mode (community feed when not home), logbook/collection, AR sky view fed by the unit | Each feature working on a real phone |
| 2.7 | Location-aware app: a "You" marker relative to the antenna and a centre-on-me map; opt-in alerts for aircraft approaching the phone, its location end-to-end encrypted to the paired radar, which runs the prediction | Alerts for aircraft near the phone arrive on a real iPhone away from home, within the radar's coverage |
| 2.8 | App shows the network's aircraft too (the kiosk's "not heard" ghosts from `/network`), marked distinctly, with matching counts and the ODbL credit; setting to turn off | The app and the kiosk show the same sky on a real iPhone |
| 2.9 | Zoom in the app: pinch from 20 nm to about 1 nm, centred on the radar, the phone, or a followed aircraft; optionally the same on the kiosk, returning to full view by itself | A real aircraft sits on the right street at full zoom on a real iPhone |
| 2.10 | Logo and app icon: a round radar-sweep mark with a nod to altitude, legible at 16 px and in one colour; app icon (with dark and tinted variants), favicons, README header, repo social preview; logo files under their own notice, not MIT | Claude | The icon on a real iPhone home screen, and favicons everywhere the project shows its face |
| 2.11 | iPad app: a big radar with details, logbook and settings in a side panel; landscape and portrait; optional full-screen wall mode | On a real iPad, both orientations, nothing changed on the iPhone |
| 2.12 | Sky view tracks: a fading line where each aircraft has been and a dotted one where it's going, projected across the sky like the labels | Outdoors on a real iPhone, the lines follow the aircraft's real path |
| 2.13 | The app without a radar: live aircraft around the phone from adsb.lol (opt-in, rounded location), radar view and Sky view; alerts and the logbook stay radar-only | On a real iPhone with no radar: real aircraft around you; pairing later switches cleanly |
| 2.14 | Weather in the app: the kiosk's precipitation radar (RainViewer) and lightning (RealEarth) on the iPhone and iPad map, with the same switches | On a real iPhone, rain shows where the kiosk shows it |
| 2.15 | The kiosk's four colour themes in the app, Daylight by default (the kiosk's default too, from 2026-10-01), and a lighter map | Each theme matches the kiosk on a real iPhone; new installs open in Daylight |
| 2.16 | Alerts about where I am, the radar, or both: low overhead, helicopter and notable alerts measured from the phone's (encrypted) location as well as the antenna, by the owner's choice; within the radar's reach first | Away from home, a helicopter near the phone alerts "near you"; one over the house doesn't |
| 2.17 | Radar names: set during setup (default from the place), shown on the radar and carried to phones by the pairing link; a rename on the radar reaches phones that haven't named it themselves | A new radar pairs and shows its own name on the phone |
| 2.18 | Set up a new radar from the app: one QR code on the first-boot screen, the app joins the setup hotspot, sends home WiFi, the phone's location, time zone and name, and pairs in the same session; the browser and on-screen setup stay | A radar fresh from the factory image is set up and paired from the app alone |
| 2.19 | Public web address during first setup: nothing to type or renew; proposed: the relay mints a one-time `tag:stratoscan` Tailscale key for a radar being set up (Cloudflare Tunnel the alternative) | A radar set up from the app is reachable away from home, and can reach nothing on the tailnet |
| 2.20 | CarPlay, within what Apple allows without an entitlement: the approach Live Activity in CarPlay (iOS 26) and a text-only nearest-aircraft widget; alerts already reach CarPlay. No CarPlay app: a radar isn't one of Apple's CarPlay categories | In a CarPlay car or the CarPlay simulator: the Live Activity, the widget, an alert |

## Phase 3: the wrist

| # | Item | Done when |
|---|---|---|
| 3.1 | watchOS app: nearest-plane complication, glance radar | Complication live on a real Watch |
| 3.2 | Distinct wrist taps per alert type; Smart Stack Live Activity | Felt on a real Watch |
| 3.3 | "Look up" mode: a compass arrow toward the aircraft, and a countdown to overhead | Arrow points correctly outdoors |
| 3.4 | Approach compass on the phone as well as the Watch: where the aircraft is, where it is coming from and heading, in the notification, a north-up dial on the Live Activity, and a live compass in the app | The needle points at a real aircraft outdoors, on a phone and a Watch |

## Phase 4: delight

| # | Item | Done when |
|---|---|---|
| 4.1 | "What was that?": the unit keeps a rolling hour of tracks in RAM; tap to rewind and see what passed overhead | Rewind works on the kiosk and in the app |
| 4.2 | Notable aircraft from plane-alert-db (**license check first**) | Categories show and alert; notices updated |
| 4.3 | Empty-sky mode: clock, weather (source license checked), today's tally | Shows when nothing is in range, and leaves when traffic returns |
| 4.4 | Spoken announcements with offline TTS (Piper; **voice license checked**, permissive only) | Announces real traffic with no internet |
| 4.5 | Yearly "Wrapped" from the sighting store, shareable from the app | Generated from RDU's real history |
| 4.6 | Opt-in feeding to FlightAware / FR24 (their feeder licenses checked; precise-location sharing is explicit) | A unit feeds; the perk account activates |
| 4.7 | Quiet hours: silence the unit's alert sounds (chimes and speech) in a set window or sunset to sunrise; alerts still show on screen; emergencies can still sound | No sound inside the window on RDU, and sound returns on time |

## Phase 5: hardware v2

| # | Item | Done when |
|---|---|---|
| 5.1 | Rotating bezel (rotary encoder) for range and paging: enclosure redesign plus input handling | Turning the bezel changes range on the kiosk |
| 5.2 | Presence wake (LD2410 mmWave over UART, or PIR) replacing the 20-min idle timer | The screen wakes on approach and sleeps when the room is empty |
| 5.3 | 978 MHz UAT receiver for US units (dump978 into readsb) | UAT-only GA aircraft appear on the radar |
| 5.4 | Retro stand: ridges all the way round the plinth, standing out ~4 mm so the slicer supports them (as the case ribs were fixed) | Printed, with clean ridges on all four sides |
| 5.5 | Ambient light sensor: dim the display with the room, with an adjustable darkest level; a sensor window on both cases; first find a real backlight control (the panel's HID report 9, or DDC) | The display follows the room on RDU, down to the owner's floor |
| 5.6 | Key the back plate so it seats only upright (antenna at the top): a key on each shell's bore wall and a matching gap in one arc of the plate's locating rib; checks prove the seven wrong orientations are blocked | The plate goes in only upright, on both cases |

## Work order (agreed 2026-09-30)

The open items are done in this order, chosen so the display is never
at risk for long.

**Rules**

- **One change to the unit at a time.** Each goes out as a small signed
  update, which rolls itself back if the screen stops painting. Leave 2–3 days
  on RDU between updates.
- **Add, then switch, then delete.** A new service runs alongside the old
  path with nothing depending on it. Screens move onto it one at a time,
  riskiest last. Old code goes only once the new path has proved itself.
- **The phone app goes first.** App changes cannot break the radar, so the
  app is where a new foundation is tested for real.
- **Hardware features change nothing without the part.** A unit without the
  sensor, bezel or receiver behaves exactly as it does today.

| Step | Items | Why here | Risk to the display |
|---|---|---|---|
| 0. Quick wins, anytime | 5.4 stand ridges, 5.6 back-plate key (CAD only); 4.7 quiet hours (off by default); 1.1 RTC cell and 1.7 radio recovery (confirm when the cell arrives or a hang happens) | Small and independent | None, or minimal |
| 1. Measure, then cool it down | **1.11** drawing cost | Its measurement script is how every later step is checked. It changes only drawing, not data | Low: screenshot comparison |
| 2. Core service, alongside | **1.8** core feed | Nothing reads it yet. Run for days with a live comparison against the kiosk's labels | None |
| 3. First user: the app | 2.8 network aircraft in the app | Real use; a bug only affects the app, which falls back to the old feed | None |
| 4. Alerts, trial run first | 1.10 `events.py` | Run the old and new logic side by side for days, logging disagreements, then switch | Alerts only |
| 5. The kiosk, last | 1.9 kiosk and public page | Riskiest change, after a week or more of the feed. Tried on the public page first; the old path kept for one release | Medium, contained |
| 6. App features | 2.9 zoom, the map part of 2.7, 3.4 (phone), the rest of 2.4/2.5, then the alerts part of 2.7 | Map parts are app-only; 3.4's direction of travel and 2.7's alerts need step 4 | None (app); low (alerts) |
| 7. Watch | 3.1 → 3.2 → 3.3 / 3.4 (Watch) | Straightforward once there is one feed to read | None |
| 8. Hardware v2 | 5.5 light sensor, 5.1 bezel, 5.2 presence, 5.3 978 MHz | As parts arrive: case, print, then software that changes nothing without the part. 5.5's first step (finding a real backlight control) is read-only and can be done anytime | Low |
| Factory image | 1.5 | Test-flash today's image soon, to prove the pipeline; rebuild after step 5 so gifted units carry the new architecture | None |

**Next, agreed 2026-10-03** (after the radar names and app setup work):
1. **Releases to RDU**, 2–3 days apart: the location-polling fix with the radar side of 2.18 (about Oct 4–5), then 1.9's switch to the core feed on its own (about Oct 7).
2. **1.12** visitor counts (#50).
3. **1.13** fleets (#51). Moved ahead of CarPlay because the family gift units need them.
4. **2.20** CarPlay (#49).

**Dependencies** (still true within the order above)

- 1.8 comes before 1.9, 1.10 and 2.8. 1.11 is independent.
- 2.7's alerts and 3.4's direction of travel need 1.10.
- 3.x needs 3.1 first; 3.4 extends 3.3.
- 1.5's final image comes after 1.9.

## Status

| Item | State | Waiting on |
|---|---|---|
| 1.1 RTC battery | Software done: the installer reports the battery; `RTC_RECHARGEABLE=1` enables charging | Fitting a cell and checking the clock survives a power cut |
| 1.3 Relay | **Done.** Live at relay.stratoscan.io (D1 attached; the old workers.dev address still answers); RDU reporting; fleet page password-protected | — |
| 1.4 Health reports | **Live**; RDU opted in and reporting every 6 h | — |
| 1.6 SD re-measure | **Done.** 2.25 GB/day in steady state (was 8.8): about 8 TB over 10 years against a rough 40–70 TB ceiling for a 128 GB card. Last fixes: 2-minute writeback batching, no Chromium shader disk cache. Remaining: journald ~1 GB/day, kept on purpose (logs that survive a crash are worth more) | — |
| 1.2 Storage off the SD card | **Not needed**, from the 1.6 measurement. Gift units use high-endurance SD cards. The fleet page flags any unit writing over 5 GB/day | Reopen #2 if a unit is ever flagged |
| 4.1 "What was that?" | Done: rewind button, closest passes from tar1090's in-RAM hour, track on radar | — |
| 4.2 Notable aircraft | Done: plane-alert-db weekly on each unit; neutral labels; no private names; PIA dropped | — |
| 4.3 Empty-sky screen | Done: clock, weather (Open-Meteo), today's tally after 30 s of empty sky | — |
| 4.4 Spoken announcements | Done: Piper + LJSpeech voice on the unit; setting off by default | — |
| 4.5 Year in review | Done: per-year counters; RDU's history carried over (44,332 visits in 2026) | — |
| 4.6 FlightAware feeding | Done: opt-in setup-page card; PiAware relays readsb; remote updates off; FR24 linked, not automated | Owner turns it on and claims the feeder |
| 2.2 Unit events | **Done.** `deploy/events.py` service on RDU; relay `POST /v1/events` live. First real events 2026-09-28: a US Army helicopter (ZEUS11), sent as notable + helicopter. Off by default on new units until a phone pairs (2.3) | — |
| 2.3 QR pairing | **Done.** A real iPhone paired with RDU from its screen (2026-09-28); RDU listed it and switched its events on. Unpairing from either side verified in the simulator | — |
| 2.1 Relay push | **Done.** Token-based APNs from the relay. Verified in the simulator, then on a real iPhone paired with RDU: the test notification arrived (2026-09-28) | — |
| 2.4 Widgets, Live Activity, StandBy | Widget done. **Live Activity done** and verified on a real iPhone (2026-09-28): RDU predicts a close pass (low, helicopter or notable, within 2 mi in the next 3 min), the relay starts a lock-screen / Dynamic Island countdown by push-to-start and ends it after the pass. Opt-in (Settings › Alerts › Approaching aircraft). Also: tap-for-details, compact labels, demo mode. **StandBy radar built** (181c308): a Radar widget (small and large) for StandBy and the home screen | A real-iPhone check of the StandBy widget |
| 2.5 Away mode, logbook, AR sky view | Away mode done and verified on a real iPhone (2026-09-28): the app and widget switch between the radar's home address and its public HTTPS page (Tailscale Funnel) as the phone leaves and rejoins home WiFi; the away address is learned from the radar. **Sky view verified on a real iPhone** (2026-09-30): hold the phone up and each aircraft's label (callsign, type, altitude, range) sits where it is in the sky, upright however the phone is held; tap for details, sideways too. Motion sensors plus the camera picture (ARKit never started on the phone). Away from the radar, opt-in: the aircraft around the phone from adsb.lol, location rounded to ~5 km. **Logbook built** (2fbf5cd) and installed on the owner's iPhone: today, all-time totals, records, what flies over, arrivals by hour, the regulars, this year | Sky view's "around me" away from home; the owner's look at the logbook |
| 1.8 Core feed | **Live on RDU** (2026-09-30, release 2026.09.30.8 plus the installer): `deploy/core-feed.py` serves `/api/aircraft`, labelled by `deploy/labels.py`, the one shared copy; `?network=1` adds the network's aircraft. Read-only on the public address (POST refused). 23 service checks, 14 parity checks | — |
| 2.8 Network aircraft in the app | Built (c8e25d9): the app reads the core feed, draws the network's aircraft hollow, counts "not heard", falls back to aircraft.json on radars without the feed. **Verified on a real iPhone with RDU** (2026-09-30): hollow network blips and the "not heard" count | — |
| 4.7 Quiet hours | **Done** (2026-09-30): Settings › Alerts › Quiet hours silences chimes and speech in a set window (default 22:00–07:00, half-hour steps) or sunset to sunrise; alerts still show; emergencies can sound; sounds you trigger in Settings still play. Off by default | — |
| 1.7 Hung-radio recovery | **Done: recovered a real failure on RDU** (2026-09-30): the FlyCatcher dropped off USB at 16:50 ("Cannot enable", error -71; no under-voltage); the watchdog restarted readsb three times, then power-cycled USB at 16:57 and the radio came back, data flowing again within a minute. About 7 minutes of "No signal" in all | — |
| 2.10 Logo and app icon | **Done** (2026-09-30): the Climb mark in Stratosphere colours. App icon (light, dark, tinted) verified on a real iPhone; Watch icon. The logo on the radar's start-up and empty-sky screens, its settings and the setup page (live on RDU); in the app's header and Settings, the Watch glance, the widget and the Live Activity. Favicons; README header; social preview ("Window to the Sky"). Files in `assets/brand/`, all rights reserved, not MIT | The social preview uploaded on GitHub; the fleet page favicon with the next relay deploy |
| 2.11 iPad app | First version built (38352db): scaled-up radar and controls, details in a side panel, wall mode. Simulator only | A real iPad; landscape layout with the panel; night dimming in wall mode |
| 2.7 Approaching me | **Live** (2026-10-01): relay deployed, RDU on 2026.10.01.1, the owner's phone opted in; RDU decrypts its location and watches for approaches to it. One countdown per aircraft per phone (3b46f89) | A real "approaching you" alert |
| 2.13 App without a radar | Built (45cf2ff): live aircraft around the phone from adsb.lol (opt-in, rounded location), centred on you; radar view, Sky view, weather, themes; logbook and alerts explained as radar-only | On a real iPhone with no radar paired |
| 2.14 App weather | Built (b7a5f81): rain and storms (RainViewer) and lightning (RealEarth) on the app's map, with switches; RainViewer is personal-use only, so a commercial release needs another source | Seen with real rain in view |
| 2.15 App colour themes | Built (826a16e): the kiosk's four themes, Daylight by default; map filter and labels follow; logo light/dark | The owner's look on the real phone |
| 2.16 Alerts about where I am | Built and live (relay 5b11035 deployed, unit release 2026.10.01.4 on RDU, app 9276216): Settings › Alerts › "Nearby alerts are about" My radar / Where I am / Both. Low overhead, helicopter and notable alerts measured from the phone's encrypted location, titled "near you"; emergencies still go to every phone. Within the radar's reach only | Away from home: an alert near the phone, none for the house |
| 2.17 Radar names | **Verified** on a real iPhone and RDU (2026-10-02): a Name setting on the radar (its screen and the setup page), suggested from the home airport's city; carried in the pairing code; a paired phone follows a rename when it's home, unless it was named on the phone. LAN only: not on the public page, not on the relay | — |
| 2.18 Set up from the app | Built: one QR code on the first-run screen; the app joins the setup network, claims the radar (admin password kept in the Keychain), sets location, airport, time zone, region and name from the phone, sends the home WiFi (the radar joins and confirms in the background), and pairs with a code only the phone holds. Tested in the simulator against the real setup server with a stand-in for setupd; also fixed the setup page's time-zone and update buttons, which had never saved | A real first-time setup: needs a radar that hasn't been set up (a gift unit) |
| 1.11 Radar drawing cost | **Done** (2026-09-30, release 2026.09.30.12): GPU process 96% → 37% of a core, Chromium total 128% → 52%. Aircraft canvas at 5 fps with the sweep on the compositor (smooth), and labels that touch the page only when something changed. Measurements on #35 | — |
| 2.9 Zoom | **Verified on a real iPhone** (2026-09-30): pinch from 20 nm to 1 nm on any spot (it stays under the fingers), double-tap to zoom in on a spot, drag to move, follow an aircraft, centre on the phone. The app's map is now at the radar's true scale (63e21ed; it had been drawn at twice it) | Kiosk zoom (optional) |
| 2.7 Location-aware app | Map part **verified on a real iPhone** (2026-09-30): a "You" marker where the phone is, and centre-on-me; location stays on the phone. The alerts near the phone are 2.7 Approaching me and 2.16, both live | — |
| 3.4 Approach compass | Built: the approach alert says where the aircraft comes from and heads (258778f, relay deployed 2026-09-30); a live compass in the app (a165624, **verified on a real iPhone** 2026-09-30: it points at the aircraft); a north-up dial on the Live Activity | A real approach alert with the new wording; the Watch |
| 3.1 watchOS app | Built (037b07a): a glance radar and complications, fed by the phone; runs in the Watch simulator. The maintainer's Watch can't be reached by Xcode (2026-09-30): not listed after re-pairing, Bluetooth off, the iPhone's hotspot, and everything on one Wi-Fi; the Watch never offers itself for pairing on the network, so Developer Mode never appears. A development build is refused without it | Install through TestFlight once the App Store Connect record exists |
| 3.2 Wrist taps, Smart Stack | Smart Stack Live Activity built (4853ebc); distinct taps not started | A real Watch |
| 5.4, 5.5 | Planned 2026-09-29 as issues #26, #27 | — |
| 1.5 Factory image | Built: CI produces a 1.6 GB image that passes its checks (working unit, no per-unit secrets, GPL sources attached). Last built 2026.09.28 under the old name; to be rebuilt as StratoScan after 1.9. Not yet published | A test flash on a spare SD card |

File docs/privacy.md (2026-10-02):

# StratoScan privacy policy

*Last updated 2026-09-29.*

StratoScan is an open-source radar for the aircraft flying over your home,
built around a receiver you own. This page covers the StratoScan radar, the
StratoScan iPhone app, and the small StratoScan relay service that connects them.
The code for all three is public at
[github.com/mferris/StratoScan](https://github.com/mferris/StratoScan).

## The short version

- Your radar's exact location never leaves it.
- The app uses your phone's location only if you ask it to show you on the
  radar, and only on the phone. One exception, off unless you turn it on:
  Sky view away from home asks adsb.lol for the aircraft around you, with
  your location rounded to about 5 km. It doesn't track you and shows no ads.
- The relay keeps the minimum it needs to deliver alerts, and deletes it
  when it's no longer needed.

## The radar

The radar receives aircraft broadcasts with its own antenna and keeps that
data on the device. It sends data off the device only for features you
turn on:

- **Phone alerts** (on when you pair a phone): short messages about notable
  aircraft, emergencies, helicopters and low aircraft nearby. Each message
  names the aircraft and gives its distance rounded to half a nautical
  mile with a compass direction, and the direction the aircraft is
  travelling (which it broadcasts itself). It never includes a position.
- **The radar's name** (from its home airport's city unless you choose one)
  stays on your home network. It's in the pairing code on the radar's
  screen, so a phone you pair shows it, and a paired phone reads it again
  when it's home. It's not on the public page and doesn't go to the relay.
- **Health reports** (off unless you turn them on): software version,
  receiver health, storage wear, temperature. No location, no network
  details, nothing about what flew over.
- **Network comparison** (off unless you turn it on): sends an approximate
  location to adsb.lol, to compare what your antenna hears with theirs.
- **Map tiles, routes, photos and weather** are fetched from the public
  services credited on the radar and in the app. Like any web request,
  they see an IP address and the area or aircraft being looked up.

## The iPhone app

The app reads your radar directly on your home network. To deliver alerts
it gives the StratoScan relay:

- a random key it generates (so your radars can recognise your phone);
- Apple's push-notification address for your phone;
- the generic device name iOS provides (for example "iPhone").

It collects nothing else: no location (but see Sky view below), contacts,
usage analytics or advertising identifiers.

**Your location.** If you tap the location button to see yourself on the
radar, iOS asks whether the app may use your location while it's open. It
is used on your phone, to place a "YOU" marker, centre the view and aim the
compass and Sky view. It is never sent to your radar or the relay. You can
turn it off at any time in the iPhone's Settings.

**Alerts for aircraft approaching you** (off unless you turn on
"Approaching me" in the app's alert settings). So your radar can warn you of
an aircraft about to pass over where *you* are, the app tells your paired
radar where your phone is when it moves significantly (iOS's
significant-change service: roughly every 500 m or more, which needs the
"Always" location permission). The location is **end-to-end encrypted to
your radar**: the app seals it with your radar's own key, which it checks
against the identity it learned when you paired, so the StratoScan relay
that carries it only ever stores an unreadable blob, for at most 6 hours.
Your radar decrypts it, keeps it in memory to run the prediction, and
never writes it down, logs it or sends it on. The alert itself names the
aircraft and when it will pass, not how far or which way from you; but an
aircraft's track is public, so an alert does hint where you were, to
anyone who could read it on its way through the relay (it is kept only
briefly). Turning the option off withdraws your location from every radar.

**Aircraft around you, without a radar** (off unless you turn it on: "See
aircraft around you", or Settings › Without a radar). For someone with no
StratoScan radar, the app shows live traffic around the phone from adsb.lol,
centred on where you are. To ask for it, the app sends adsb.lol your
location **rounded to about 5 km** (0.05°), every 5 seconds while the app is
open. adsb.lol sees that rounded location and your IP address, like any web
request. Nothing goes to the StratoScan relay. The map is centred on your
exact position on the phone only. Pairing a radar switches this off.

**Sky view away from home** (off unless you turn it on). When the phone is
more than 3 nm from your radar, Sky view offers to show the aircraft around
you instead. If you say yes, the app asks adsb.lol, a public ADS-B network,
for the aircraft within 25 nm of your location **rounded to about 5 km**
(0.05° of latitude and longitude), every 5 seconds while Sky view is open.
adsb.lol sees that rounded location and your IP address, like any web
request. Nothing else is sent, and a button in Sky view turns it off again.
The camera picture in Sky view is never recorded or sent.

### Setting up a radar from the app

Scanning a new radar's first-run code lets the app set it up:
- It joins the radar's own setup network.
- It sends the radar **this phone's location** (you are standing next to it), time zone and region.
- It sends a name and your home WiFi password, over that network straight to the radar.
- It claims the radar with an admin password that it makes and keeps in this phone's Keychain.

Pairing needs no second code. The phone makes a one-time secret and gives the radar only a fingerprint of it, which the radar hands the relay once it's online. Nothing from setup is kept in the app beyond the paired radar and that password.

## The relay

The relay is a small service run by the StratoScan maintainer on Cloudflare.

| What | Kept for |
|---|---|
| Which phones are paired with which radar | Until either side unpairs |
| A phone's push address and alert choices | Until it is no longer paired with any radar |
| Alerts waiting to be delivered | At most 48 hours (500 per radar) |
| Health reports (only if turned on) | About 30 days |
| A one-time pairing code's fingerprint (never the code itself) | Until used, or 10 minutes |

A factory reset of a radar unpairs its phones and gives it a new identity.
Nothing on the relay is sold or shared, or used for advertising or
tracking.

## Contact

Questions or requests:
[github.com/mferris/StratoScan/issues](https://github.com/mferris/StratoScan/issues).

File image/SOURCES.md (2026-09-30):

# Source code for the StratoScan factory image

The factory image is Raspberry Pi OS with StratoScan installed on top. It
contains software under the GNU GPL and other copyleft licences. As its
distributor, the StratoScan project offers the corresponding source as
follows.

**StratoScan itself** (MIT): https://github.com/mferris/StratoScan, at the
project commit named in `MANIFEST.txt`.
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

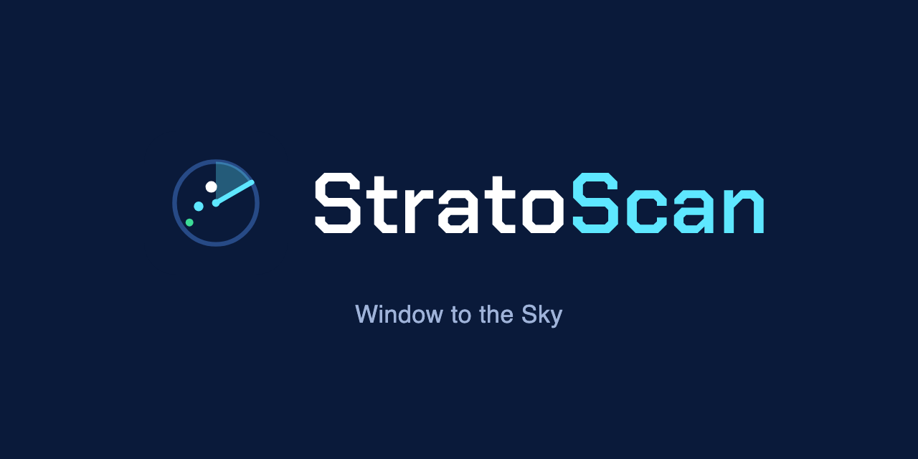
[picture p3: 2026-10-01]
assets/brand/social-preview.png

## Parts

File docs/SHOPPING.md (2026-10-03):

# Shopping list

Everything you need to build a StratoScan from nothing: the radar, the case, and
optionally the iPhone app. After that is what is still to come for the
features in progress.

Claude keeps this current. A part is added when the design or an issue first
needs one, and moved along as it is ordered and fitted.

*Last updated 2026-09-30. Prices are approximate, in US dollars.*

## Build one StratoScan

### 1. The radar: receiver, computer, power

You need all of these. They also make a working radar on their own, in a web
browser, before any display or case.

| Part | Qty | Approx. | Notes |
|---|---|---|---|
| [Raspberry Pi 5, 8 GB](https://www.raspberrypi.com/products/raspberry-pi-5/) | 1 | $80 | What StratoScan is developed and measured on. The kiosk browser needs the headroom |
| [Raspberry Pi Active Cooler](https://www.raspberrypi.com/products/active-cooler/) | 1 | $5 | Needed: it drives the radar full-time, and the case holds heat in |
| [Raspberry Pi 27 W USB-C power supply](https://www.raspberrypi.com/products/27w-power-supply/) | 1 | $12 | A weaker supply causes under-voltage and USB drop-outs |
| High-endurance microSD card, 64–128 GB | 1 | $15–25 | For example SanDisk High Endurance or Samsung PRO Endurance. Writes measure about 2.25 GB/day, fine for about 10 years on an endurance card |
| ADS-B receiver (1090 MHz SDR with a built-in filter) | 1 | $30–46 | Either the Nooelec FlyCatcher (what RDU uses) or the [FlightAware Pro Stick Plus](https://flightaware.store/products/pro-stick-plus) |
| [NooElec ADS-B Discovery 5 dBi antenna bundle](https://www.amazon.com/NooElec-ADS-B-Discovery-Antenna-Bundle/dp/B01J9DH9U2) | 1 | $25 | Hinged whips for 1090 and 978 MHz; the FlyCatcher has an input for each. Its small right-angle pigtails are MCX, for USB-stick receivers, and aren't needed. **Placement matters more than any part:** a window or outdoor spot heard 14 aircraft where an indoor puck heard 1 |

**Connect the receiver directly.** The FlyCatcher mounts on the Pi as a HAT,
but its data still goes over USB: use the short USB-A to micro-USB jumper that
comes with it, plugged straight into one of the Pi's ports. **Don't add a
USB adapter or extension** (a right-angle USB-A adapter, a panel-mount
passthrough). On RDU a right-angle adapter made the receiver drop off USB
dozens of times an evening ("Cannot enable. Maybe the USB cable is bad?");
the screen showed NO SIGNAL each time until the watchdog reset it. With the
adapter removed, the drop-outs stopped.

**If the speakers won't fit beside it** (2026-10-02): the straight USB-A plug in
the Pi, plus the curve of its cable, sticks out about 35–45 mm past the Pi's
edge, where the cases' side speakers sit. The fix to try first is a **one-piece
short micro-USB to USB-A cable, about 15–20 cm, with a right-angle (90°) USB-A
end**. It's moulded as one part, so unlike the adapter it adds no extra
connection. Angled ends come as "up" or "down"; which one turns the cable toward
the back plate depends on which of the Pi's ports it's in, so a pair of each is
the easy way (about $8–12). If the drop-outs come back with it, go back to the
FlyCatcher's own cable: the watchdog still recovers the receiver either way.

**Check first:** set up the Pi, receiver and antenna, and confirm real
aircraft appear before you buy the display. See
[project-spec.md](project-spec.md), "Purchase Plan".

### 2. The display

| Part | Qty | Approx. | Notes |
|---|---|---|---|
| [Waveshare 7″ round LCD, 1080×1080](https://www.waveshare.com/7inch-1080x1080-lcd.htm) | 1 | $160 | HDMI video plus USB touch. The cases are designed around it |
| Micro-HDMI to HDMI cable, short (30 cm or less) | 1 | $8 | The Pi 5 has **micro**-HDMI ports. A slim or right-angle cable is easier to fit in the case |
| USB-A to USB-C **data** cable, short | 1 | $6 | Carries the touch signal from the panel to the Pi. **Charge-only cables leave touch dead** while the picture still works |
| Waveshare 8 Ω 5 W speaker pair | 1 pair | $10 | For the alert chimes and spoken announcements. They connect to the panel's driver board, and the sound travels over HDMI. The cases have brackets for them |

### 3. The case (3D printed)

Two designs, both in [`enclosure/`](../enclosure/):
- **Retro:** a ship's-instrument look.
- **Kitten:** a cat with the display as its face.

They share the back plate and antenna mount.

| Part | Qty | Approx. | Notes |
|---|---|---|---|
| SMA male to SMA female **bulkhead** jumper, RG316, ~30 cm (12") | 2 | ~$8–10 a pair | One per antenna, for the twin antenna mount (`antenna_mount_twin`): the bulkhead end in the mount, the plug on the FlyCatcher. **SMA, not RP-SMA** (RP-SMA has no centre pin) |
| Filament: **ASA** recommended | ~1 kg | $25–30 | Retro: one colour. Kitten: two colours for the head, more for the stand; see its README. **Why ASA:** a radar usually sits in a window for reception, where sun on a dark case can pass 60 °C. PLA starts to soften around 55–60 °C, so it's fine for a test fit but can sag or warp in a sunny window. PETG holds to about 75–80 °C; ASA and ABS hold to about 95–100 °C. ASA also doesn't yellow or go brittle in sunlight, and prints as cleanly as ABS. It needs an enclosed printer (the Bambu H2D is one). On a two-nozzle printer, print the support *interface* in a material that won't bond, so supports lift off cleanly: PETG under ASA/ABS (or Bambu Support for ABS), PLA under PETG. **Bought on Amazon:** Polymaker ASA, Dark Grey Green for the retro case (Grey if it sits in full sun), with PETG as the support interface |
| M3 brass heat-set inserts: **have them** (Kadrick M2–M5 kit, 520 pcs) | 19 per case (18 for the kitten) | — | Holes sized for this kit (4.0 mm). 8 × M3×5 for the front, 8 × M3×6 for the back plate, 3 × M3×5 in the antenna mount; optionally 8 × M2×3 for the speakers. Pressed in with a soldering iron. Any M3 insert about 4.5 mm across fits |
| M3 socket-head screws | 21 per case (20 for the kitten) | $8 | **M3 × 14:** 8 for the front trim (7 on the kitten). **M3 × 8:** 8 for the back plate and 3 for the antenna mount. 2 more for the USB-C connector, if it doesn't come with its own. A kit with these lengths is easiest |
| M2 × 6 screws (optional) | 8 | — | Only if the speakers go on M2 inserts rather than their self-tapping screws |
| M2.5 screws, about 6 mm | 4 | — | Hold the Pi onto the back plate's standoffs. Usually in the same kit |
| Panel-mount USB-C extension cable, **rated 5 A / 100 W (e-marked)**, with two M3 screw holes 16.5 mm apart | 1 | $10–15 | Brings power in through the back plate. **The rating matters:** a thin extension dropped the Pi's 5 V supply to 4.96 V and caused under-voltage several times an hour, gone when the supply was plugged straight in (5.08 V). The cutout is 11 × 6.5 mm; print `usbc_gauge` to test-fit a different connector first |
| **Antenna mounting, choose one:** | | | |
| · puck socket (`antenna_mount`) | — | — | Holds FlightAware's desktop puck antenna directly. Nothing extra to buy |
| · SMA jack (`antenna_mount_sma`), **recommended** | | | Takes any SMA antenna, such as the whip above, or coax to a better spot |
| SMA female-to-female bulkhead barrel, with O-ring and nut | 1 | $8 (2-pack) | For example [onelinkmore](https://www.amazon.com/onelinkmore-Female-Waterproof-Bulkhead-Adapter/dp/B0GTV677Z4). **Not RP-SMA** |
| SMA male-to-male RG316 jumper, about 20 cm | 1 | $8 (2-pack) | Barrel to receiver. For example [HCFeng](https://www.amazon.com/HCFeng-Extension-Coaxail-coaxial-Assembly/dp/B0C2KQB1H3). **Not RP-SMA** |

**Tools:**
- a 3D printer (designed on a Bambu Lab printer, with an AMS for the kitten's colours);
- a soldering iron with a heat-set insert tip;
- hex keys.

### 4. Optional

| Part | For | Approx. | Notes |
|---|---|---|---|
| ML-2020 **rechargeable** RTC cell | Keeping the clock through power cuts | $5 | Plugs into the Pi 5's battery connector. Run the installer with `RTC_RECHARGEABLE=1`. **Never enable charging for a CR2032**, which isn't rechargeable |
| Wall anchors and screws | Wall mounting | — | Both cases also have a desk stand |

### 5. The iPhone app

| Need | Notes |
|---|---|
| An iPhone on iOS 17.2 or later | For the app, widget, alerts and Live Activity |
| An Apple Watch, Series 5 / SE or later | Only for the Watch app, still to come (Phase 3). Earlier models have no compass |
| **To build the app yourself:** a Mac with Xcode, and the Apple Developer Program ($99/yr) | Only needed to build and install the app yourself |
| **To run your own relay (push alerts):** a free Cloudflare account | See [relay/README.md](../relay/README.md) |

**Rough total for one unit:** about $400, plus filament and the phone you
already have.

## Coming later

These are for roadmap items that aren't built yet. **Wait until each item
starts before buying:** the exact part may change.

| Part | For | Approx. |
|---|---|---|
| [Adafruit VEML7700 lux sensor (#4162)](https://www.adafruit.com/product/4162) and [STEMMA QT cable (#4397)](https://www.adafruit.com/product/4397) | [5.5 light sensor](https://github.com/mferris/StratoScan/issues/27) | $6 |
| Rotary encoder | [5.1 rotating bezel](https://github.com/mferris/StratoScan/issues/22) | ~$5 |
| Presence sensor: LD2410 mmWave, or a PIR | [5.2 presence wake](https://github.com/mferris/StratoScan/issues/23) | ~$10 |
| 978 MHz SDR, for example FlightAware's 978 MHz Pro Stick Plus (the antenna is already in the bundle above) | [5.3 UAT receiver, US only](https://github.com/mferris/StratoScan/issues/24) | ~$25–40 |

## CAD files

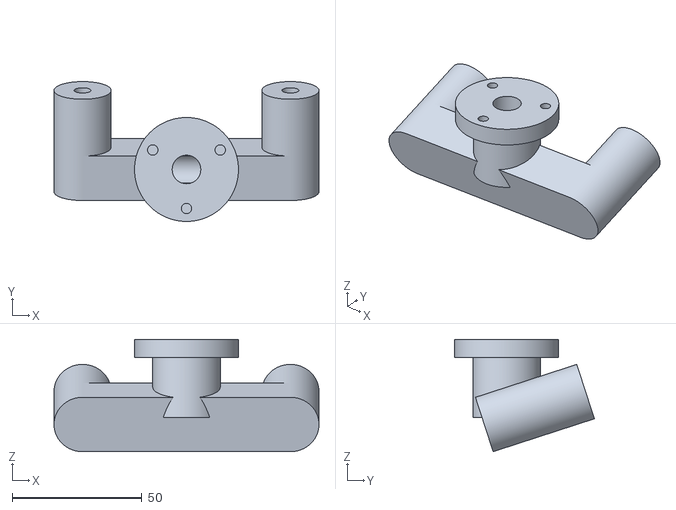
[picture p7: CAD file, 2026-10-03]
enclosure/Kitten Enclosure Two-Tone/antenna_mount_twin.stl
102.0 x 53.8 x 43.2

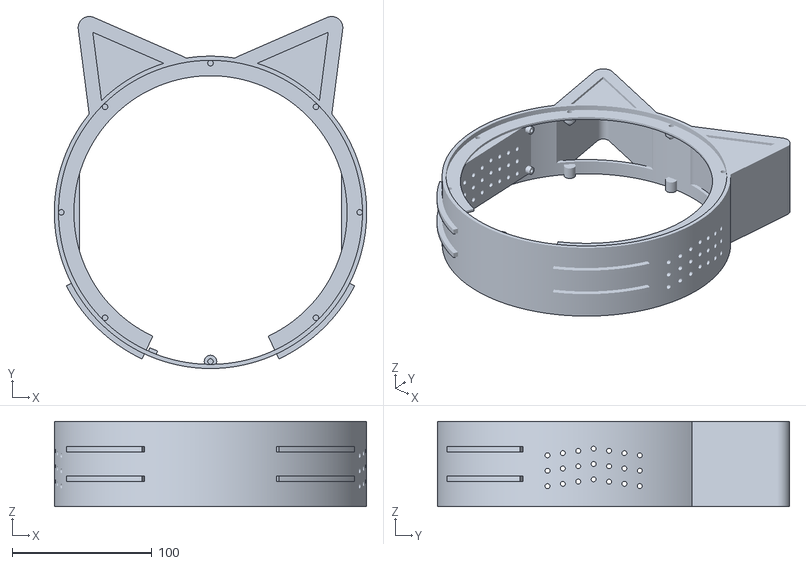
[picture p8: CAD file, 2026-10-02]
enclosure/Kitten Enclosure Two-Tone/shell.stl
223.3 x 251.7 x 61.0

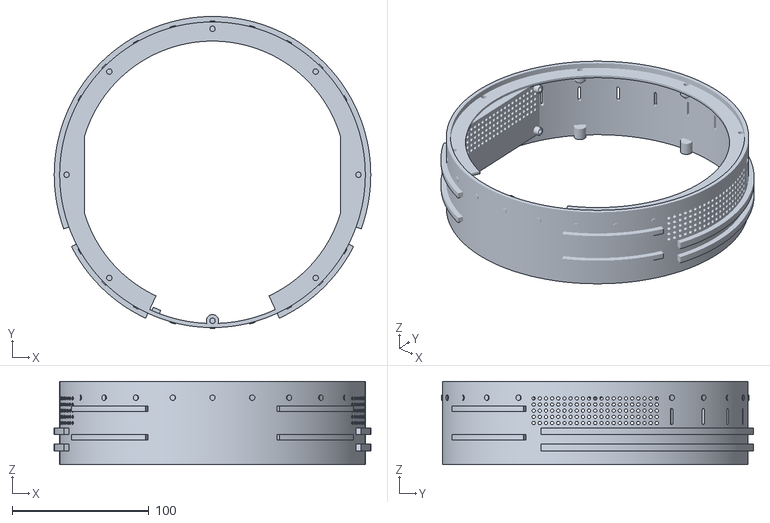
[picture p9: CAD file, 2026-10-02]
enclosure/Retro Radar Enclosure/shell.stl
231.3 x 228.0 x 61.0

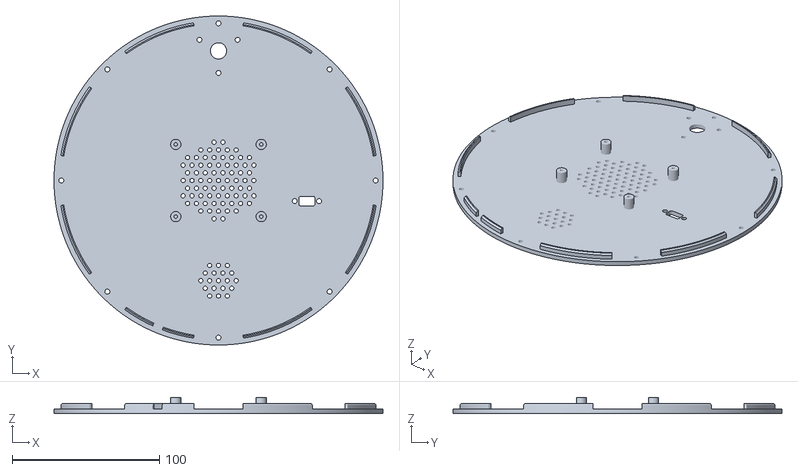
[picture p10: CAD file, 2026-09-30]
enclosure/Kitten Enclosure Two-Tone/back_plate.stl
223.3 x 223.3 x 11.0

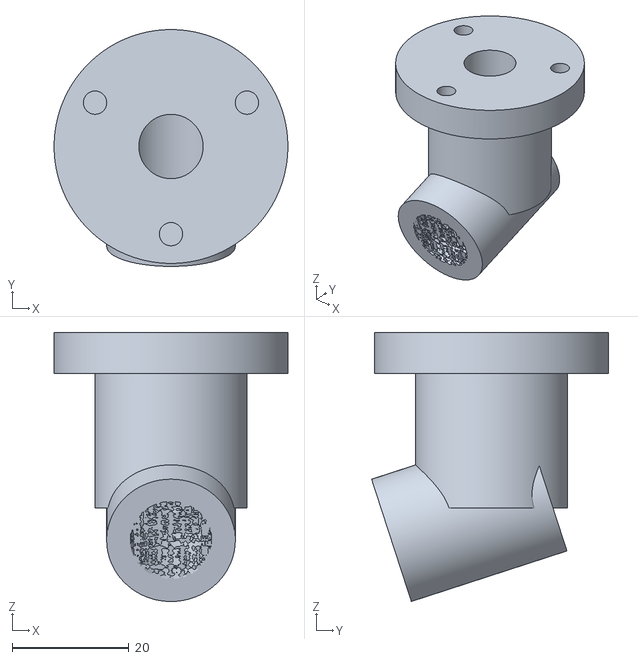
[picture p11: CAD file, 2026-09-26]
enclosure/Kitten Enclosure Two-Tone/antenna_mount_sma.stl
40.0 x 40.5 x 46.0

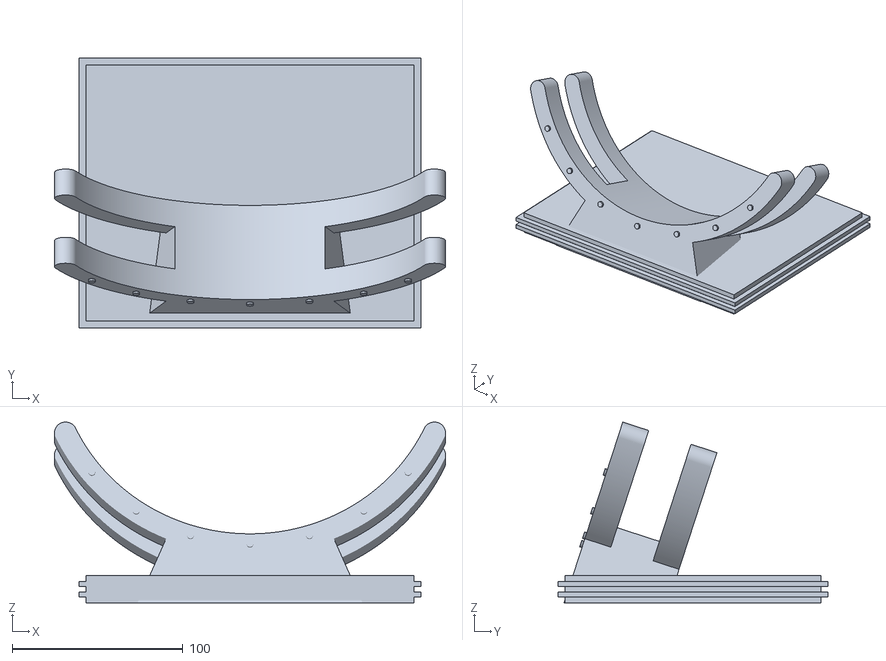
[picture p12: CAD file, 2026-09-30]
enclosure/Retro Radar Enclosure/stand.stl
229.0 x 158.0 x 105.9

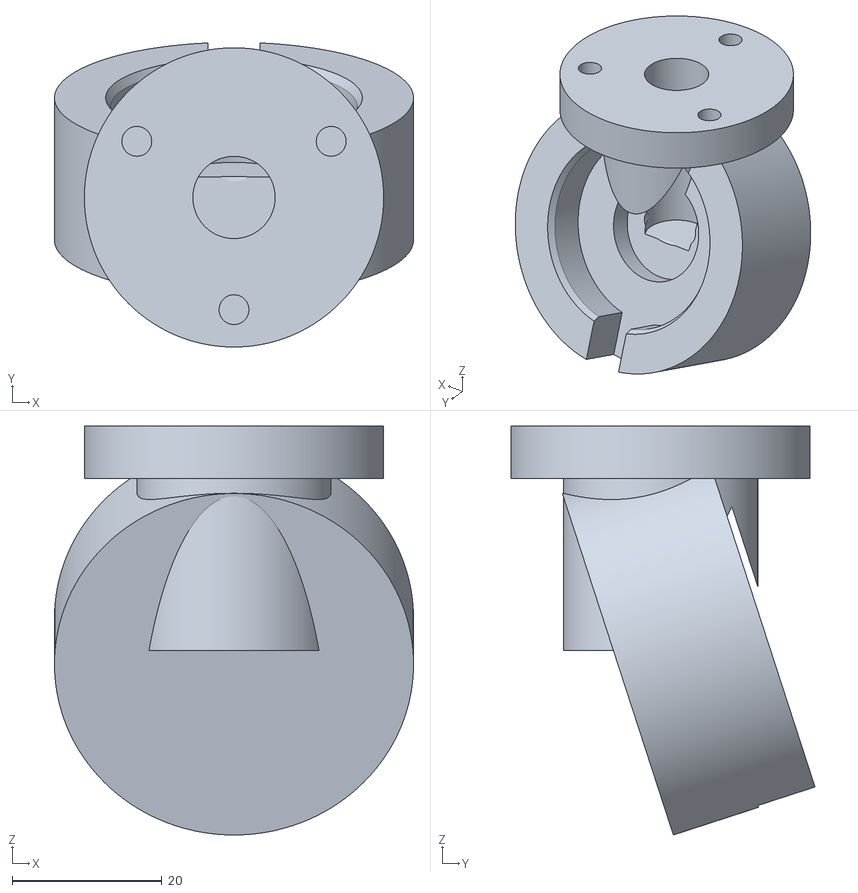
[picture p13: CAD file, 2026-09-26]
enclosure/Kitten Enclosure Two-Tone/antenna_mount.stl
48.0 x 40.7 x 54.7

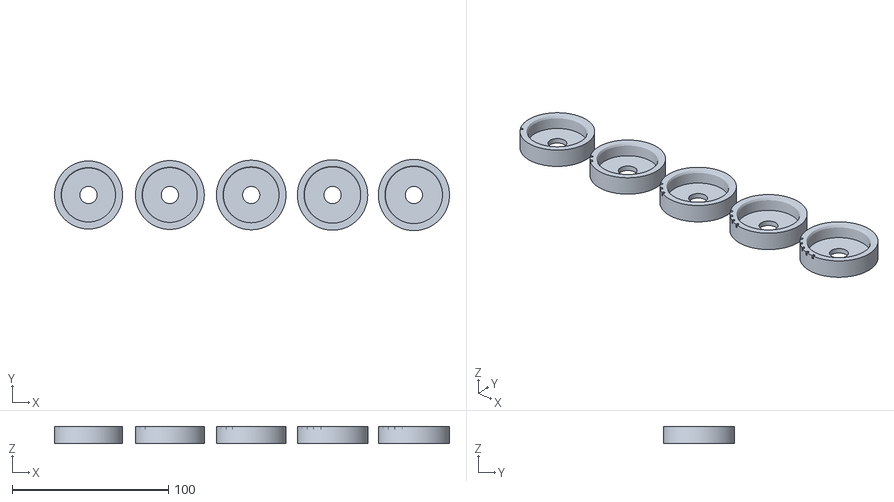
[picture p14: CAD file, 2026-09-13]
enclosure/Kitten Enclosure Two-Tone/antenna_socket_gauge.stl
252.5 x 45.5 x 11.0

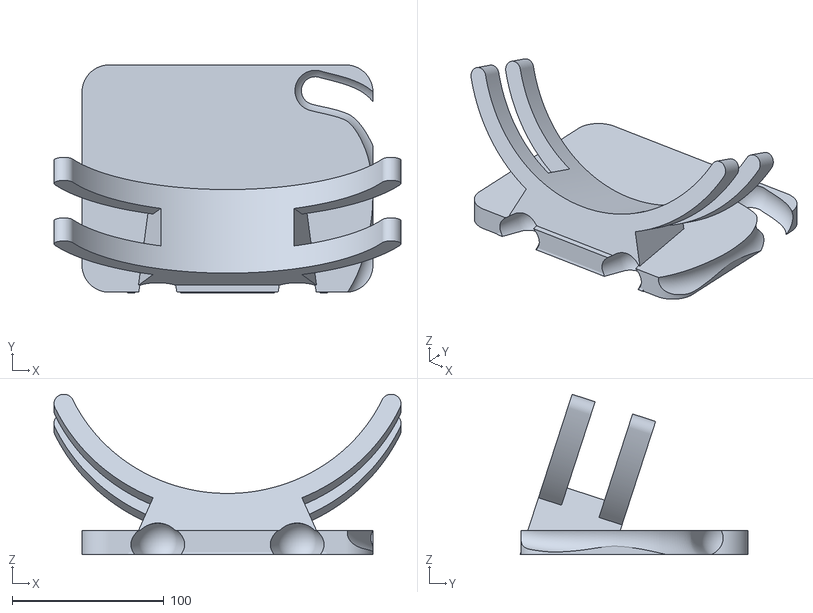
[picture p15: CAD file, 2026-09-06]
enclosure/Kitten Enclosure Two-Tone/stand_body.stl
229.0 x 150.5 x 105.9

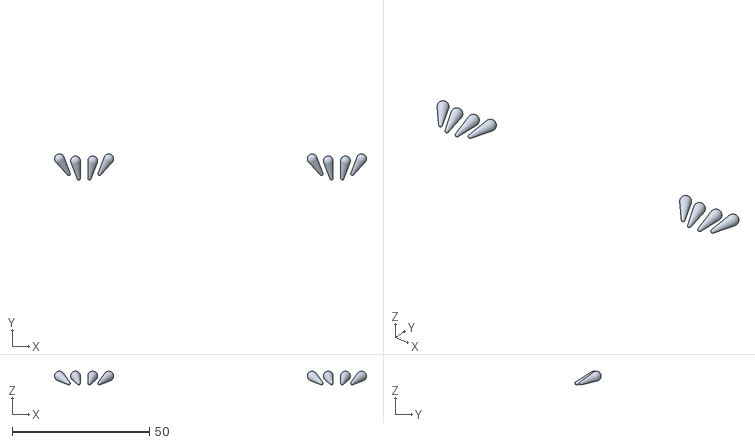
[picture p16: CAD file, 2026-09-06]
enclosure/Kitten Enclosure Two-Tone/stand_claws.stl
113.6 x 9.57 x 4.96

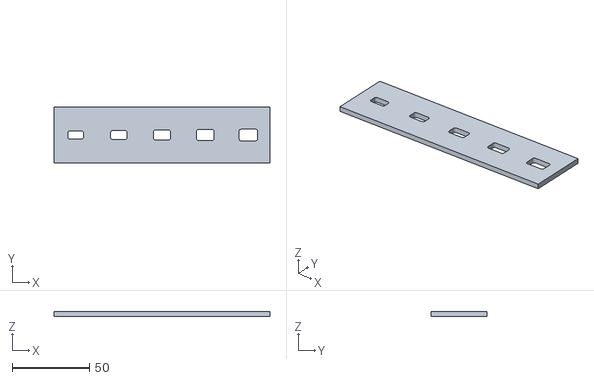
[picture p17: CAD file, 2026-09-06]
enclosure/Retro Radar Enclosure/usbc_gauge.stl
140.0 x 36.0 x 3.00

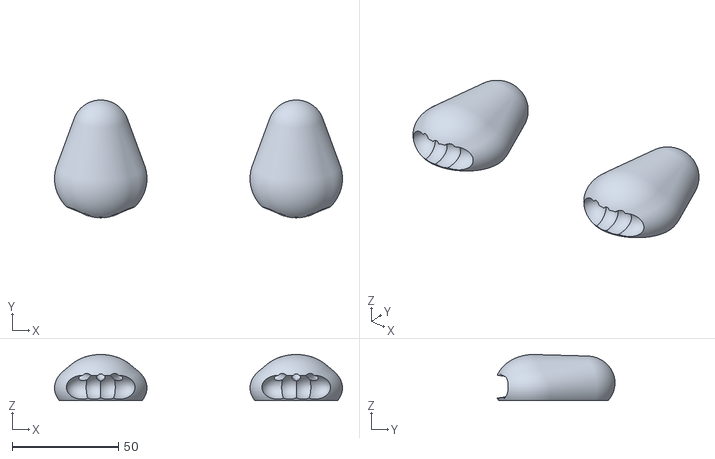
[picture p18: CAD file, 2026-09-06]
enclosure/Kitten Enclosure Two-Tone/stand_paws.stl
135.5 x 55.5 x 21.6

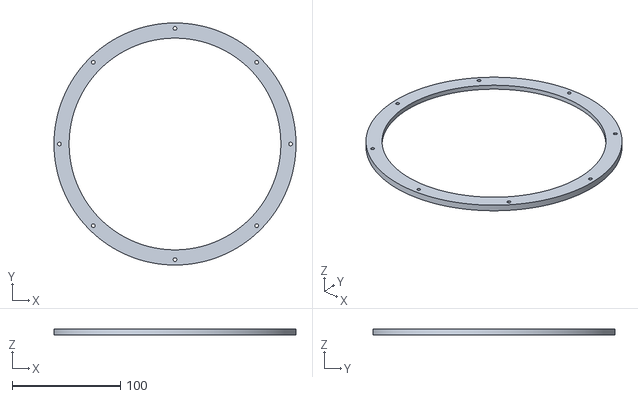
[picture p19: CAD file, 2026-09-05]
enclosure/Retro Radar Enclosure/front_trim.stl
223.3 x 223.3 x 5.62

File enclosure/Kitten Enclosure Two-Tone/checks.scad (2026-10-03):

// Fit checks for the two-tone kitten enclosure. Each target is an
// INTERSECTION (or a DIFFERENCE) that must come out with no real volume.
//
// Not "empty": run these with `sh run-checks.sh`, which measures the volume
// of what each produces. Wherever two parts share a surface -- which is the
// whole point of the colour split -- a boolean leaves a zero-thickness film
// along that boundary, with thousands of facets and no volume. Judging by
// facet count calls a correct model broken.
//
// Lives beside the design on purpose: `use <>` resolves
// relative to the file that contains it, so a copy in /tmp silently finds
// nothing and every check "passes" against empty geometry.
use <kitten-enclosure-twotone.scad>
check = "none";
// front heat-set inserts (restated): shelf top face, insert length, hole
fi_top = 57; fi_len = 5; fi_hole = 4.0;
// Must match the design's resolution or the checks validate different
// geometry from what gets exported. This said $fn=96 while the design moved
// to adaptive $fa/$fs, and the giveaway was the canary reporting volume to
// the milligram across a resolution change that should have moved it.
$fs = 0.4;
$fa = 0.5;
outer_dia=223.34; shell_depth=61; wall=3; lip_height=6; shelf_h=2;
screw_r=106.67; n_screws=8; post_od=9;
screw_clear_dia=3.4; nose_angle=270; front_trim_h=4;
back_plate_t=3; ant_mount_y=88; ant_stub_len=30; ant_barrel_len=14; ant_socket_dia=33; ant_socket_depth=6;
speaker_bracket_depth=15; speaker_d=45;
cradle_id=outer_dia+2; cradle_od=cradle_id+26; arm_gap=26; arm_w=16;
base_h=16; stand_angle=18;
// Restated because `use <>` imports modules and functions but NOT variables.
// These must track the design file: paws and tail are bigger here than in
// the single-colour version, and a stale value here would check the old
// geometry and pass.
paw_x=46; paw_h=18;
n_toes=4; toe_dia=13.5; toe_splay=21; claw_len=6.5;
ant_conn_dia=9.15; ant_boss_dia=45; ant_socket_lead=2;
// Measured off the antenna: 31.25mm across the flared bottom, its widest
// point. ant_relief_* is the clear space under the socket floor for the
// connector, which is what was actually stopping the base from seating.
ant_base_dia=31.25; ant_relief_dia=18; ant_relief_h=4;
ant_cable_slot_w=7; ant_cable_exit_h=7.98; ant_flange_t=7; ant_flange_insert_d=5.5;

// The SMA bulkhead variant. Restated here for the same reason as everything
// above: `use <>` brings in modules, not variables, so a check that names one
// of these directly needs its own copy.
ant_sma_hole=6.5; ant_sma_panel_t=3; ant_sma_cavity=14;
ant_sma_boss_d=22; ant_sma_boss_h=10; ant_sma_cavity_d=25;

// The back-plate features added with the locating lip. Restated here for the
// same reason as everything above: `use <>` brings in modules, never values.
back_lip_h=4; back_lip_t=2; back_lip_gap=0.35; back_lip_skip=9;
back_post_h=9; ant_bolt_pcd=30; n_ant_bolts=3; ant_flange_d=40;
usbc_cut_pos=[60,-14]; usbc_cut_w=11.0; usbc_cut_h=6.5; usbc_screw_pitch=16.5; usbc_screw_dia=3.4;
mount_hole_x=58; mount_hole_y=49;

if (check=="ear_vs_post") {
  intersection() {
    ears_hollow();
    for (i=[0:n_screws-1]) { a=i*360/n_screws;
      translate([screw_r*cos(a), screw_r*sin(a), shell_depth-lip_height-1])
        cylinder(d=post_od+1, h=shelf_h+3); }
  }
}
// Does the inner-ear dish reach an insert post? That is the thing that
// actually matters. An earlier version of this check probed the whole rim
// band with a +0.01 fudge on its outer diameter, which reported a 0.06mm
// "interference" that was nothing but the 96-gon's flats dipping inside
// the true radius at the shared boundary -- a measurement artifact, not
// geometry. Posts stop at r=111.17, half a millimetre inside the wall, so
// probing them directly has real clearance and no boundary ambiguity.
else if (check=="recess_vs_post") {
  intersection() {
    inner_ear_recess();
    for (i=[0:n_screws-1]) { a=i*360/n_screws;
      translate([screw_r*cos(a), screw_r*sin(a), shell_depth-lip_height-1])
        cylinder(d=post_od, h=lip_height+2); }
  }
}
else if (check=="whisker_through") {
  r_mount = outer_dia/2 - wall - speaker_bracket_depth;
  zc = (shell_depth-speaker_d)/2 + speaker_d/2;
  intersection() {
    shell();
    translate([r_mount, 0, zc]) rotate([0,90,0]) cylinder(d=1.2, h=speaker_bracket_depth+wall+2, $fn=8);
  }
}
else if (check=="head_in_cradle") {
  arm_lift = base_h + cradle_od/2 - 3;
  intersection() {
    stand();
    translate([0,0,arm_lift]) rotate([90-stand_angle,0,0]) translate([0,0,-shell_depth/2]) shell();
  }
}
// The tail now rests ON the right paw on purpose, so "must not touch" is
// the wrong assertion. What must not happen is the tail passing THROUGH the
// foot at pad height, which reads as one fused lump instead of a tail
// draped over a paw. So: it may meet the paw's upper half, but must not
// intrude into the lower half at all.
else if (check=="tail_over_paw") {
  intersection() {
    tail();
    intersection() {
      union() { paw(paw_x); paw(-paw_x); }
      // the paw's lower half, which scales with the paw
      translate([-200,-200,-50]) cube([400,400,50 + paw_h*0.7]);
    }
  }
}
// It should still be nowhere near the LEFT paw.
else if (check=="tail_vs_left_paw") {
  intersection() { tail(); paw(-paw_x); }
}
// The tail must also stay under the cradled head, whose underside comes
// down to about z=27.
else if (check=="tail_vs_head") {
  arm_lift = base_h + cradle_od/2 - 3;
  intersection() {
    tail();
    translate([0,0,arm_lift]) rotate([90-stand_angle,0,0]) translate([0,0,-shell_depth/2]) shell();
  }
}
// Paws must not reach the head either, now that they are taller.
else if (check=="paws_vs_head") {
  arm_lift = base_h + cradle_od/2 - 3;
  intersection() {
    union() { paw(paw_x); paw(-paw_x); }
    translate([0,0,arm_lift]) rotate([90-stand_angle,0,0]) translate([0,0,-shell_depth/2]) shell();
  }
}
else if (check=="ears_vs_cradle") {
  arm_lift = base_h + cradle_od/2 - 3;
  intersection() {
    stand();
    translate([0,0,arm_lift]) rotate([90-stand_angle,0,0]) translate([0,0,-shell_depth/2]) ears_solid();
  }
}
// The five colour bodies must add back up to exactly the one-piece stand,
// with nothing left over and nothing missing. Both directions are checked
// because each catches a different mistake: material_lost finds a region no
// part claims (a hole in the print), material_gained finds a region two
// parts both claim (an overlap, where which colour wins depends on the
// slicer's load order).
else if (check=="material_lost") {
  difference() { stand(); stand_colour_parts(); }
}
else if (check=="material_gained") {
  difference() { stand_colour_parts(); stand(); }
}
// Overlap between any two coloured bodies, checked pairwise rather than
// against the whole, since a body cannot overlap itself and the union above
// would hide a mutual overlap inside the total.
else if (check=="paws_vs_toes")     { intersection() { part_stand_paws(); part_stand_toes(); } }
// The claws are a colour body like any other, so they overlap the toes they
// grow out of by colour_overlap and must not share a surface with them.
else if (check=="claws_vs_toes")    { intersection() { part_stand_toes(); part_stand_claws(); } }
// ...and they must actually STAND OFF the toes. A claw entirely buried in
// its toe still passes every seam and volume check above while being
// invisible on the print -- which is exactly what the grooves-as-nails
// problem looked like. Positive control: material must exist forward of the
// toes' own envelope.
else if (check=="claws_stand_proud") {
  difference() {
    union() { part_stand_claws(); }
    union() { paw_toes(paw_x); paw_toes(-paw_x); paw_pad(paw_x); paw_pad(-paw_x); }
  }
}
// A claw that reaches the desk plane would carry the stand's weight on four
// points per paw and rock. Nothing below z=0.6.
else if (check=="claws_off_the_desk") {
  intersection() {
    part_stand_claws();
    translate([-300,-300,-300]) cube([600,600,300.6]);
  }
}
else if (check=="paws_vs_tail")     { intersection() { part_stand_paws(); part_stand_tail(); } }
else if (check=="body_vs_paws")     { intersection() { part_stand_body(); part_stand_paws(); } }
else if (check=="tail_vs_tip")      { intersection() { part_stand_tail(); part_stand_tail_tip(); } }
// The whiskers have to sit in the band between the nose and the screw holes
// either side of it. The first version of them missed by ninety degrees and
// printed before anyone noticed, so both ends of that band are now pinned.
else if (check=="whisker_vs_screws") {
  intersection() {
    whisker_grooves();
    for (i=[0:n_screws-1]) { a=i*360/n_screws;
      translate([screw_r*cos(a), screw_r*sin(a), -5])
        cylinder(d=screw_clear_dia, h=20); }
  }
}
else if (check=="whisker_vs_nose") {
  intersection() { whisker_grooves(); nose(); }
}
// ...and that they are actually beside the NOSE. An intersection can only
// prove two things do not touch; it cannot prove a feature is in the right
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

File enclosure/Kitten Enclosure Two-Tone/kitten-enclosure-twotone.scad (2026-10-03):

// ============================================================
// StratoScan — KITTEN enclosure
//
// Same radar, same hardware, different animal. Every dimension that
// touches a physical part is copied verbatim from the Retro Radar
// build, which is printed and validated: the 203.34mm round panel, the
// Pi's 58x49 standoff pattern, the two 100x45mm speakers, the 30mm fan,
// the M3 screw ring, the USB-C and SMA bulkheads. Only the SHAPE is new.
//
// The design idea is that the round display IS the face. Everything
// else follows from that: ears above it, whiskers where the speakers
// already were, a nose on the bezel, and a stand shaped like a sitting
// cat with front paws and a curled tail.
//
// Parts (print all four):
//   1. front_trim — the face: bezel ring, nose, whisker grooves
//   2. retainer   — ring behind the glass (identical to the retro part)
//   3. shell      — the head: body cylinder + ears, all the internals
//   4. stand      — sitting body: plinth, cradle, paws, tail
//
// Assembly is unchanged: front_trim -> [glass] -> retainer -> shell,
// 8 M3 screws through the trim and retainer into heat-set inserts in
// the shell's posts. The head then sets down into the stand.
// ============================================================

part = "preview";  // front_trim | retainer | shell | stand | preview | exploded | test_ear
// ---- Curve resolution ------------------------------------------------
// $fa/$fs rather than a fixed $fn, which is what this was before.
//
// A fixed count makes the flats grow with the feature, so the biggest, most
// looked-at surfaces come out roughest: at $fn=96 the head's 223mm rim had
// 7.3mm flats and the cradle 8.2mm, while every 3mm screw hole also got 96
// sides it had no use for. $fs caps the chord -- the width of one flat,
// which is what the eye reads as faceting -- so a big curve gets the facets
// and a small hole does not.
//
// 0.4mm is one extrusion width: below that the printer cannot reproduce the
// difference. $fa then bounds the count on very large radii. Together these
// give the head 0.97mm flats for about a quarter more mesh than $fn=96 --
// cheaper than raising $fn would have been, because the savings on small
// holes pay for the big surfaces.
$fs = 0.4;   // max chord in mm
$fa = 0.5;   // max degrees per fragment

// ============================================================
// HARDWARE CONTRACT — do not change these to suit the styling.
// They describe real parts. Copied from the Retro Radar build.
// ============================================================
panel_diameter    = 203.34;
panel_active      = 178.15;
panel_glass_depth = 6.45;   // whole panel module (preview only, NOT the rabbet)
glass_thickness   = 1.62;   // the glass sheet alone — this is what the rabbet spans

pcb_w = 108; pcb_h = 72;
mount_hole_x = 58; mount_hole_y = 49;

// ---------- MEASURE ON YOUR ASSEMBLED UNIT, THEN SET ----------
// 42 -> 56 gave the side-mounted speakers (45mm along this axis) room
// without touching the Pi/heatsink stack. 56 -> 61 is the FlyCatcher: it
// is a HAT, so it stacks onto the BACK of the Pi, and the Pi hangs off the
// LCD panel at the front -- which puts the HAT's pre-amp slide switches
// facing the back plate. At 56 they fouled it as the plate was screwed
// down, which is the worst kind of interference: everything appears to fit
// until the last two turns, and then it is loading the board.
//
// Deeper is nearly free here -- a bigger box, more filament, a longer
// print -- and too shallow is a case that cannot be closed without
// pressing on a switch. Measure YOUR stack before printing: this is the
// one number that has had to move every time the internals changed.
shell_depth_note = "56 -> 61 for the FlyCatcher HAT's pre-amp switches";
shell_depth = 61;           // front glass face to back of the tallest component
rim = 10;
outer_dia = panel_diameter + 2*rim;   // 223.34
wall = 3;

glass_overlap     = 4;
retention_opening = panel_diameter - 2*glass_overlap;
front_trim_h  = 4;
retainer_h    = 4;
lip_height    = 6;
shelf_h       = lip_height - retainer_h;
rabbet_depth  = glass_thickness;

screw_r = panel_diameter/2 + rim/2;
n_screws = 8;
screw_clear_dia = 3.4;
// Heat-set inserts: the Kadrick M2-M5 kit. Its M3 inserts are 4.5mm across
// the knurl and 3.9mm at the lead-in, 3-8mm long. A 4.0 hole gives the knurl
// 0.25mm a side to melt into (4.2 left 0.15mm). Same as the retro case.
insert_hole_dia = 4.0;
post_od = 9;
// The 8 front posts hang 8mm below the shelf's top face, merged into the
// wall, with a 45-degree cone under each, so an M3x5 insert has plastic all
// round it. They were 2mm tall. Screws: M3x14. See the retro case's notes.
front_insert_len = 5;
front_post_h     = 8;
front_post_cone  = 4;

relief_center_deg = 270;
relief_arc_deg    = 50;

// ---- Removable back plate --------------------------------------------
// The back was a fixed floor with the electronics standing on it, so the
// only way in was through the glass. It is now a separate screwed plate,
// and everything that stood on the floor went with it: the standoffs, the
// fan mount, the intake and fan grilles, and the two cable glands.
//
// The Pi itself is mounted to the LCD panel rather than to these standoffs,
// so taking the plate off exposes the back of the Pi and its cabling rather
// than removing it. The 58x49 standoffs are kept as an alternative mounting
// position; they cost nothing and removing them is a one-line change.
//
// No locating spigot: a ring into the bore lands exactly where the eight
// screw posts are, since those straddle the bore wall. Eight screws on a
// 213mm circle locate the plate perfectly well on their own.
back_plate_t   = 3;    // same as the floor it replaces

// ---- Antenna mount ---------------------------------------------------
// The retro build carries the antenna on a turret out of the top of the
// case. There is no turret here -- it would be a spike out of a cat's
// skull -- so the antenna mounts on the back plate instead, behind the
// head, and only the antenna itself shows above the ears.
//
// Same socket as the retro turret, and counter-tilted by stand_angle the
// same way, so the antenna reads vertical once the whole case leans back in
// its cradle.
//
// The standoff is what makes that possible, and it is not decoration. A
// vertical antenna rising from a plate the same diameter as the head has to
// travel outward past a 111.7mm radius to clear it, and it gains z the whole
// way -- so mounted flat against the plate it converges on the head and
// fouls the top rim. Standing the socket back from the plate buys the height
// it needs to clear: at 12mm the antenna's 33mm envelope passes the rim with
// room to spare, at 0mm it cuts straight through it. antenna_clears_head in
// checks.scad is what holds that.
// Bolted on rather than moulded into the plate: it prints flat and
// support-free on its own, the plate does too, and the antenna angle can be
// changed later without reprinting the tray.
ant_stub_dia   = 26;   // the arm reaching back from the plate
ant_stub_len   = 30;   // how far back it reaches
// 30 is measured, not chosen. A vertical antenna rising from a plate the
// diameter of the head must travel out past a 111.7mm radius to clear it,
// gaining height toward the head the whole way -- so the arm is what buys
// the room to do that behind the head rather than through it. Swept against
// the antenna's own envelope: at 22mm it fouls the top rim even at nominal
// diameter, at 26mm it clears nominal but not +2mm, and at 30mm it still
// clears with 6mm of radial slack. antenna_clears_head holds it.
ant_barrel_len = 14;   // socket barrel, along the antenna's own axis
ant_flange_d   = 40;
ant_flange_t   = 7;   // 4 -> 7: the insert now lives in the FLANGE, not the plate
ant_flange_insert_d = 5.5;  // heat-set pocket depth, leaving 1.5mm of flange behind it
ant_bolt_pcd   = 30;
ant_bolt_d     = 3.4;
n_ant_bolts    = 3;
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

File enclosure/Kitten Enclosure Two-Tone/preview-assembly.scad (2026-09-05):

// Whole-unit preview: head seated in the stand. Must live beside the
// design -- `use <>` resolves relative to THIS file, so a copy elsewhere
// silently renders nothing at all.
use <kitten-enclosure-twotone.scad>
// `use <>` imports modules and functions but NOT special variables, so the
// design's own $fa/$fs do not come with them. Without these two lines this
// renders at OpenSCAD's defaults ($fa=12, $fs=2) and shows a faceting that
// the exported mesh does not have -- a preview that lies about the model.
$fs = 0.4;
$fa = 0.5;
outer_dia=223.34; shell_depth=56; base_h=16; stand_angle=18;
cradle_id=outer_dia+2; cradle_od=cradle_id+26;
arm_lift = base_h + cradle_od/2 - 3;
color("DimGray") stand();
translate([0,0,arm_lift]) rotate([90-stand_angle,0,0]) translate([0,0,-shell_depth/2]) {
    color("Gainsboro") shell();
    color("LightPink") translate([0,0,shell_depth+1.62]) front_trim();
}

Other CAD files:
enclosure/Kitten Enclosure Two-Tone/preview-colours.scad
enclosure/Kitten Enclosure Two-Tone/front_trim.stl
enclosure/Kitten Enclosure Two-Tone/retainer.stl
enclosure/Kitten Enclosure Two-Tone/stand.stl
enclosure/Kitten Enclosure Two-Tone/stand_tail.stl
enclosure/Kitten Enclosure Two-Tone/stand_tail_tip.stl
enclosure/Kitten Enclosure Two-Tone/stand_toes.stl
enclosure/Retro Radar Enclosure/checks.scad
enclosure/Retro Radar Enclosure/flightwall-enclosure.scad
enclosure/Retro Radar Enclosure/retainer.stl
enclosure/Retro Radar Enclosure/retro-enclosure.scad

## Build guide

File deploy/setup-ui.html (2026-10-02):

# StratoScan setup

Getting started…

## Sign in

This device has not been set up yet. Enter the code shown on the radar's own screen, then choose a password for it.

Code on the screen

Password Continue

## WiFi ✓

Scan for networks

Password for Join network

Changing WiFi may briefly disconnect you. If this page stops responding, rejoin your home network and open this address again — the radar puts its old network back automatically if the new one doesn't work.

## Receiver location ✓

Where the antenna physically is. Used to centre the radar. Kept on the device; if you later publish a public page, the position it shows is rounded to about half a mile.

Address

Looked up via OpenStreetMap. The address is sent to their geocoder and nowhere else; the position it returns stays on the device. Prefer not to? Enter coordinates instead.

Find address

Latitude

Longitude

Type the number without a sign and pick the hemisphere. Pasting a signed value works too. Look up an address instead.

Save location

## Home airport ✓

Sets the landing/takeoff highlight and the approach heatmap.

Search LiveATC feed name (optional)

Feed names can't be worked out from the airport code, so this is left blank unless you fill it in. Find yours at liveatc.net and paste the mount value. Blank simply turns the ATC feature off.

Save airport

## Name

What this radar is called on its screen and on paired phones, such as "Raleigh" or "Mom's radar". Left blank, it's the home airport's city. Not shown on the public page.

Save name

## Time zone and region ✓

Sets the clock the radar timestamps everything with, and the WiFi regulatory region the radio is allowed to use. Both were fixed to the United States before; a unit used anywhere else showed the wrong time on every sighting.

Time zone show all time zones WiFi region

The time zone applies immediately. The WiFi region is a radio setting and only takes effect after the device restarts.

Save time zone and region

## Software update ✓

Updates are signed. The device will refuse anything that is not signed by the maintainer's key, and anything older than what it already has. If a new version fails to start, the old one is put back automatically — you do not have to be nearby.

Checking…

Check for updates Install update

## Share with FlightAware

Optional. Sends what this antenna hears to FlightAware (https://www.flightaware.com/adsb/), and in return gives you a free FlightAware Enterprise account (normally paid) for as long as it keeps sharing. It also shares this antenna's exact location with FlightAware, which they need to locate aircraft more precisely; you set it in your own FlightAware account. By turning it on you agree to FlightAware's terms (https://www.flightaware.com/about/termsofuse). The radar on this device is unaffected either way.

Share with FlightAware

Flightradar24 offers a similar free plan to people who share data. Their software is installed with their own instructions: stratoscan24.com/build-your-own.

## Phone app

Pair the StratoScan iPhone app to get alerts from this radar: emergencies, notable aircraft, helicopters and anything low overhead. Alerts say what flew by and roughly how far away, never where this radar is.

Pair this phone

Cancel

## Health reports

Optional. Every few hours the device sends the maintainer a short health check (software version, whether the receiver is working, storage wear, temperature) so a problem can be spotted and fixed without you having to notice it. It never includes your location, your network, or what flew overhead. Turn it off any time.

Send health reports

## Public web address ✓

Optional. Uses your own Tailscale account, so the device and its location stay under your control. Create a free account, generate an auth key, and paste it here. Skip this to keep the radar on your home network only.

Tailscale auth key Device name Also publish a public https page Connect

## Change password

Current password New password Change password

Changing it signs out every other device.

## Reset

Show reset options

Reset settings clears the location and home airport but keeps this radar on your WiFi, so you can carry on using it.

Erase everything is for giving the radar to someone else. It removes your WiFi, your Tailscale account, your password, the receiver's location, and the flight history and approach heatmap built up at this address. The radar then starts its own setup network so the next person can claim it.

Your password Type RESET to confirm Erase everything (giving it away) Reset

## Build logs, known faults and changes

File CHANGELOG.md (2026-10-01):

# Changelog

## Unreleased

- The app's internal names are StratoScan too (2026-10-01): the Xcode
  project (`ios/StratoScan.xcodeproj`), its folders and targets, the Swift
  types, the `stratoscan://` pairing link (units from 2026.10.01.2 make it;
  the app still accepts `radome://`), and the push payload's key. Kept on
  purpose: the bundle ID and App Group (until the company name is
  settled), the stored settings keys and Keychain entry (renaming them
  would lose every owner's settings and unpair their radars), and the
  home-screen widget's kind (renaming it would remove placed widgets).
- Renamed from Radome to **StratoScan** (2026-09-30). The GitHub repo moves to
  `mferris/StratoScan` (old links redirect). As before, internal names stay as
  they were so units in service update cleanly, and so do the iPhone app's
  bundle ID, App Group, `radome://` pairing links and stored settings keys.
  New units announce `StratoScan-Setup` as their hotspot and use the
  hostname `stratoscan`.
- Renamed from FlightRadar to **Radome** (2026-09-28), to stay clear of the
  Flightradar24 trademark. The GitHub repo moved to `mferris/Radome` (old
  links redirect). Internal paths and service names keep the old name so
  units already in service update cleanly.

## v1.0.0 — 2026-08-23

First tagged release. FlightRadar has been under active development for a
while (see [HANDOFF.md](HANDOFF.md) for the full development history); this
tag marks the first point the project has a version number attached to it.

### Features

- **Live tracking** — polls a local `readsb` instance every second;
  altitude-coded blips, smooth interpolation between polls, a "NO SIGNAL"
  banner on connection loss
- **Airline & route lookup** — badges each flight with its airline and shows
  its city-pair route where one's known
- **Aircraft type & photo** — human-readable type names and a real photo
  when one exists, falling back to a representative photo of the type
- **Background map** — real terrain, roads, and cached runway outlines,
  darkened and centered on the receiver, with a live weather radar overlay
- **RDU approach visualization** — a real density heatmap built from
  actually observed landings over time
- **Sighting counts** — tracks how many distinct times each aircraft has
  been picked up, and how many of those came within the nearby-alert
  radius; shown as a "SEEN ×N" badge and in the detail panel
- **Registered-owner lookup** — for confirmed-private aircraft, shows who
  the plane is registered to
- **Nearby-aircraft alert** — auto-pops flight details with a chime for
  anything within 2 miles of the receiver
- **Emergency squawk alert** — a distinct urgent chime and a red auto-popped
  panel for 7500 (hijack), 7600 (radio failure), or 7700 (general emergency)
- **RDU landing/takeoff highlight** — a bright green ring around the blip
  and label of anything currently landing or departing at RDU, plus an
  optional quiet chime
- **RDU ATC audio link** — an optional link to LiveATC.net's live
  approach/departure audio for the airport (deliberately a link, not an
  embed — see [README's Security section](README.md#security) for why),
  automatically disabled on the physical kiosk itself since it can't be
  safely reopened there via touch
- **Settings panel** — a gear icon opens on-screen toggles for all of the
  above alert/sound behaviors, persisted per-device
- **Touch detail panel** — tap any aircraft for registration, squawk,
  vertical rate, precise range/bearing, and flight trail
- **Native iOS companion app** — a SwiftUI rebuild of the same radar for
  iPhone, talking to the same receiver over Tailscale

### Security

- Public exposure (e.g. via Tailscale Funnel) goes through a filtering
  gateway that rounds the receiver's exact coordinates before they leave
  the network
- External/third-party data is HTML-escaped before touching the DOM
- Shared same-origin stores (approach track, sighting counts) validate
  input shape and cap request body size
- No secrets or API keys anywhere — every external data source is free and
  keyless

See [README.md](README.md) for full setup/deployment docs and
[HANDOFF.md](HANDOFF.md) for the detailed development history behind each
of these.

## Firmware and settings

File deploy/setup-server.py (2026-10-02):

#!/usr/bin/env python3
"""Unprivileged HTTP tier for StratoScan device setup.

Runs as a normal user and holds no privileges of its own. Anything that
touches the system is delegated to setupd.py over a unix socket, which
re-validates every parameter. This process only parses HTTP, checks
authentication, and renders the UI -- deliberately, because the HTTP parser
is the part most exposed to hostile input and therefore the part that must
not be root.

Reachable on the LAN at http://<device>/setup via lighttpd. It is listed in
funnel-gateway.py's LOCAL_ONLY_PATHS, so it is refused for anything arriving
through the public tunnel -- which matters, since it accepts a WiFi password
and a Tailscale auth key.

Claiming: on first boot the device is UNCLAIMED and the first person to
reach it sets the admin password. That is a deliberate trade-off, chosen
because a label-printed secret has a manufacturing lead time. The window is
narrowed by requiring a code shown on the device's own screen, so claiming
needs physical sight of the unit rather than merely being on the network.
"""
import hashlib
import hmac
import http.server
import json
import os
import re
import secrets
import socket
import threading
import time
import unicodedata

LISTEN = ("127.0.0.1", 8086)
SOCK_PATH = "/run/stratoscan/setupd.sock"
STATE_DIR = "/var/lib/stratoscan-setup"
STATE_FILE = os.path.join(STATE_DIR, "setup.json")
CLAIM_FILE = "/run/stratoscan/claim-code"
AIRPORTS_JSON = "/opt/stratoscan/airports.json"
UI_FILE = "/opt/stratoscan/setup-ui.html"

MAX_BODY = 64 * 1024
SESSION_TTL = 8 * 3600
SESSION_IDLE = 30 * 60
MAX_SESSIONS = 8

_sessions = {}          # sha256(token) -> {created, seen}
_lock = threading.Lock()
_fail = {"count": 0, "until": 0.0}


# ------------------------------------------------------------------ state

def load_state():
    try:
        with open(STATE_FILE) as f:
            return json.load(f)
    except Exception:
        # An unreadable or corrupt state file must read as UNCLAIMED, never
        # as "locked out" -- otherwise a single bad write bricks the owner
        # out of their own device with no way back.
        return {"schema": 1, "claimed": False}


def save_state(st):
    os.makedirs(STATE_DIR, mode=0o700, exist_ok=True)
    tmp = STATE_FILE + ".tmp"
    with open(tmp, "w") as f:
        json.dump(st, f, indent=1)
        f.flush()
        os.fsync(f.fileno())
    # 0660, not 0600: the root helper shares this directory by group so both
    # tiers can read it. See share_state_dir() in setupd.py for why.
    os.chmod(tmp, 0o660)
    os.replace(tmp, STATE_FILE)
    dfd = os.open(STATE_DIR, os.O_DIRECTORY)
    try:
        os.fsync(dfd)
    finally:
        os.close(dfd)


# hashlib.scrypt needs OpenSSL 1.1+ and is absent from some Python builds.
# Preferred where present, but never depended on: a missing hash function at
# password-creation time would lock the owner out of their own device, which
# is a brick-class failure for the sake of a nicety. The algorithm is
# recorded per-record so existing passwords keep verifying either way.
HAVE_SCRYPT = hasattr(hashlib, "scrypt")


def hash_password(pw, salt=None):
    salt = salt or os.urandom(16)
    if HAVE_SCRYPT:
        h = hashlib.scrypt(pw.encode(), salt=salt, n=2**14, r=8, p=1, dklen=32)
        return {"algo": "scrypt", "n": 2**14, "r": 8, "p": 1,
                "salt": salt.hex(), "hash": h.hex()}
    h = hashlib.pbkdf2_hmac("sha256", pw.encode(), salt, 600_000, dklen=32)
    return {"algo": "pbkdf2", "iters": 600_000,
            "salt": salt.hex(), "hash": h.hex()}


def verify_password(pw, rec):
    if not rec:
        return False
    try:
        salt = bytes.fromhex(rec["salt"])
        if rec.get("algo") == "scrypt":
            if not HAVE_SCRYPT:
                return False
            h = hashlib.scrypt(pw.encode(), salt=salt, n=rec["n"], r=rec["r"],
                               p=rec["p"], dklen=32)
        elif rec.get("algo") == "pbkdf2":
            h = hashlib.pbkdf2_hmac("sha256", pw.encode(), salt,
                                    rec["iters"], dklen=32)
        else:
            return False
    except Exception:
        return False
    return hmac.compare_digest(h.hex(), rec["hash"])


def claim_code():
    """Shown on the device's own screen; never served over HTTP.

    Behind lighttpd's proxy every request appears to come from 127.0.0.1, so
    a 'localhost only' HTTP route would have been readable by the entire LAN.
    The code is read from a file the on-screen console also reads.
    """
    try:
        with open(CLAIM_FILE) as f:
            return f.read().strip()
    except Exception:
        return None


# ------------------------------------------------------------- setupd link

def call_setupd(verb, params=None, timeout=120):
    s = socket.socket(socket.AF_UNIX, socket.SOCK_STREAM)
    s.settimeout(timeout)
    try:
        s.connect(SOCK_PATH)
        s.sendall((json.dumps({"verb": verb, "params": params or {}}) + "\n").encode())
        buf = b""
        while not buf.endswith(b"\n"):
            chunk = s.recv(65536)
            if not chunk:
                break
            buf += chunk
        return json.loads(buf or b'{"ok":false,"code":"no_response"}')
    except FileNotFoundError:
        return {"ok": False, "code": "setupd_unavailable"}
    except socket.timeout:
        return {"ok": False, "code": "timeout"}
    except Exception as e:
        return {"ok": False, "code": "setupd_error", "detail": str(e)[:120]}
    finally:
        s.close()


# ---------------------------------------------------------------- sessions

def new_session():
    tok = secrets.token_urlsafe(32)
    now = time.time()
    with _lock:
        if len(_sessions) >= MAX_SESSIONS:
            oldest = min(_sessions, key=lambda k: _sessions[k]["seen"])
            _sessions.pop(oldest, None)
        _sessions[hashlib.sha256(tok.encode()).hexdigest()] = {"created": now, "seen": now}
    return tok


def valid_session(token):
    if not token:
        return False
    key = hashlib.sha256(token.encode()).hexdigest()
    now = time.time()
    with _lock:
        s = _sessions.get(key)
        if not s:
            return False
        if now - s["created"] > SESSION_TTL or now - s["seen"] > SESSION_IDLE:
            _sessions.pop(key, None)
            return False
        s["seen"] = now
        return True


def drop_sessions():
    with _lock:
        _sessions.clear()


def throttled():
    """Exponential backoff, capped, always self-clearing.

    Never a permanent lockout: the owner forgetting their password must not
    require re-flashing the device.
    """
    return time.time() < _fail["until"]


def note_failure():
    _fail["count"] += 1
    if _fail["count"] >= 5:
        delay = min(900, 2 ** (_fail["count"] - 5))
        _fail["until"] = time.time() + delay


def note_success():
    _fail["count"] = 0
    _fail["until"] = 0.0


# -------------------------------------------------------------------- HTTP

SECURITY_HEADERS = {
    "Cache-Control": "no-store",
    "X-Content-Type-Options": "nosniff",
    "X-Frame-Options": "DENY",
    "Referrer-Policy": "no-referrer",
}


class Handler(http.server.BaseHTTPRequestHandler):
    protocol_version = "HTTP/1.1"

    def version_string(self):
        return "StratoScan"

    def log_message(self, fmt, *args):
        # Never log the query string or body: they carry the WiFi password
        # and the Tailscale auth key.
        path = self.path.split("?", 1)[0]
        print(f"setup {self.command} {path}", flush=True)

    # -- helpers ---------------------------------------------------------

    def _send(self, code, obj=None, body=None, ctype="application/json"):
        payload = body if body is not None else json.dumps(obj or {}).encode()
        self.send_response(code)
        self.send_header("Content-Type", ctype)
        self.send_header("Content-Length", str(len(payload)))
        for k, v in SECURITY_HEADERS.items():
            self.send_header(k, v)
        self.end_headers()
        if self.command != "HEAD":
            self.wfile.write(payload)

    def _err(self, code, token, message):
        self._send(code, {"error": {"code": token, "message": message}})

    def _body(self):
        try:
            n = int(self.headers.get("Content-Length") or 0)
        except ValueError:
            return None
        if n > MAX_BODY:
            return None
        try:
            return json.loads(self.rfile.read(n) or b"{}")
        except Exception:
            return None

    def _authed(self):
        auth = self.headers.get("Authorization") or ""
        return auth.startswith("Bearer ") and valid_session(auth[7:])

    def _public_blocked(self):
        """The gateway marks anything that came from the public tunnel.

        Belt and braces alongside LOCAL_ONLY_PATHS: if the gateway's filter
        were ever bypassed again, this still refuses the request.
        """
        return self.headers.get("X-FR-Public") is not None

    # -- routing ---------------------------------------------------------

    def do_GET(self):
        self._route()

    def do_POST(self):
        self._route()

    def do_HEAD(self):
        self._route()

    def _route(self):
        if self._public_blocked():
            self._send(404, {})
            return
        path = self.path.split("?", 1)[0].rstrip("/") or "/setup"
        st = load_state()

        if path in ("/setup", "/setup/index.html"):
            return self._serve_ui()
        if path == "/setup/api/hello":
            return self._send(200, {
                "product": "StratoScan",
                "claimed": bool(st.get("claimed")),
                "steps": st.get("steps", {}),
                "hasScreen": claim_code() is not None,
                # The public (Funnel) address, if one is live: the phone app
                # uses it away from home. Already public by definition, and
                # this route is refused on the Funnel itself.
                "publicUrl": public_url(),
                # The radar's name, so a paired phone at home follows a rename.
                "name": radar_name(st),
                # Who this is, so the app setting it up finds the same radar
                # again on the home network (by <hostname>.local) and pairs
                # with it. Both are public facts on the LAN anyway.
                "unit": unit_id(),
                "hostname": socket.gethostname(),
            })
        if path == "/setup/api/claim" and self.command == "POST":
            return self._claim(st)
        if path == "/setup/api/login" and self.command == "POST":
            return self._login(st)

        # everything below requires a session
        if not self._authed():
            return self._err(401, "unauthenticated", "Sign in to continue.")

        if path == "/setup/api/status":
            return self._status(st)
        if path == "/setup/api/airports":
            return self._airports()
        # GET only: this came before the POST route below and caught every
        # POST too, so saving the time zone from the setup page fetched the
        # list instead and changed nothing (found 2026-10-02).
        if path == "/setup/api/locale" and self.command == "GET":
            return self._locale()
        # GET only, for the same reason as locale: this used to catch the
        # POST below, so Check and Install on the setup page did nothing.
        if path == "/setup/api/ota" and self.command == "GET":
            return self._send(200, call_setupd("ota_status", {})["result"])
        if path == "/setup/api/feeding" and self.command == "GET":
            return self._proxy_verb("feeding_status")
        if path == "/setup/api/feeding" and self.command == "POST":
            b = self._body()
            return self._proxy_verb("set_feeding", {"flightaware": b.get("flightaware")})
        if path == "/setup/api/pair" and self.command == "GET":
            return self._pair_reply(pair_verb("status"))
        if path == "/setup/api/pair" and self.command == "POST":
            b = self._body() or {}
            return self._pair_reply(pair_verb(b.get("action"), b.get("phone")))
        if path == "/setup/api/health" and self.command == "GET":
            return self._proxy_verb("health_status")
        if path == "/setup/api/health" and self.command == "POST":
            b = self._body()
            return self._proxy_verb("set_health_report", {"enabled": b.get("enabled")})
        if path == "/setup/api/geocode":
            from urllib.parse import parse_qs, urlparse
            q = (parse_qs(urlparse(self.path).query).get("q") or [""])[0]
            return self._send(200, call_setupd("geocode", {"query": q})["result"])
        if path == "/setup/api/wifi/scan":
            return self._proxy_verb("wifi_scan")
        if path == "/setup/api/wifi/connect" and self.command == "POST":
            return self._wifi_connect()
        if path == "/setup/api/wifi/confirm" and self.command == "POST":
            return self._proxy_verb("wifi_confirm")
        if path == "/setup/api/wifi/rollback" and self.command == "POST":
            return self._proxy_verb("wifi_rollback")
        if path == "/setup/api/location" and self.command == "POST":
            return self._location(st)
        if path == "/setup/api/setup/join" and self.command == "POST":
            return self._setup_join(st)
        if path == "/setup/api/setup/offer" and self.command == "POST":
            # Already online (Ethernet, or WiFi set some other way): offer the
            # phone's code now rather than after a join.
            h = (self._body() or {}).get("secretHash")
            if not (isinstance(h, str) and RE_SECRET_HASH.match(h)):
                return self._err(400, "bad_request", "That pairing code is not usable.")
            return self._proxy_verb("pair_offer_hash", {"hash": h})
        if path == "/setup/api/name" and self.command == "POST":
            r = set_name((self._body() or {}).get("name"))
            if r is None:
                return self._err(400, "bad_name", f"Use 1-{NAME_MAX} letters, numbers or spaces.")
            return self._send(200, {"result": r})
        if path == "/setup/api/airport" and self.command == "POST":
            return self._airport(st)
        if path == "/setup/api/locale" and self.command == "POST":
            return self._set_locale(st)
        if path == "/setup/api/ota" and self.command == "POST":
            b = self._body() or {}
            verb = {"check": "ota_check", "apply": "ota_apply"}.get(b.get("action"))
            if not verb:
                return self._err(400, "bad_action", "Use check or apply.")
            return self._proxy_verb(verb)
        if path == "/setup/api/tailscale/status":
            return self._proxy_verb("tailscale_status")
        if path == "/setup/api/tailscale/up" and self.command == "POST":
            return self._tailscale_up(st)
        if path == "/setup/api/tailscale/funnel" and self.command == "POST":
            b = self._body() or {}
            return self._proxy_verb("tailscale_funnel", {"enabled": bool(b.get("enabled"))})
        if path == "/setup/api/hotspot" and self.command == "POST":
            b = self._body() or {}
            return self._proxy_verb("hotspot_start" if b.get("on") else "hotspot_stop")
        if path == "/setup/api/password" and self.command == "POST":
            return self._change_password(st)
        if path == "/setup/api/reset" and self.command == "POST":
            return self._reset(st)
        if path == "/setup/api/reboot" and self.command == "POST":
            b = self._body() or {}
            if b.get("confirm") != "REBOOT":
                return self._err(400, "confirm_required", "Confirmation missing.")
            return self._proxy_verb("reboot")

        self._send(404, {})

    # -- handlers --------------------------------------------------------

    def _serve_ui(self):
        try:
            with open(UI_FILE, "rb") as f:
                self._send(200, body=f.read(), ctype="text/html; charset=utf-8")
        except FileNotFoundError:
            self._send(500, body=b"setup UI missing", ctype="text/plain")

    def _claim(self, st):
        if st.get("claimed"):
            return self._err(409, "already_claimed",
                             "This device has already been set up.")
        if throttled():
            return self._err(429, "too_many_attempts", "Too many tries. Wait a moment.")
        b = self._body() or {}
        code, pw = b.get("claimCode") or "", b.get("password") or ""
        expected = claim_code()
        if expected is None:
            return self._err(503, "no_claim_code",
                             "The device has not finished starting up.")
        if not hmac.compare_digest(code.strip().upper(), expected.strip().upper()):
            note_failure()
            return self._err(403, "bad_claim_code",
                             "That code does not match the one on the screen.")
        if not (8 <= len(pw) <= 128):
            return self._err(400, "weak_password", "Use at least 8 characters.")
        note_success()
        st.update({"schema": 1, "claimed": True,
                   "password": hash_password(pw),
                   "steps": st.get("steps", {})})
        save_state(st)
        return self._send(200, {"token": new_session(), "expiresIn": SESSION_TTL})

    def _login(self, st):
        if not st.get("claimed"):
            return self._err(409, "not_claimed", "This device has not been set up yet.")
        if throttled():
            return self._err(429, "too_many_attempts", "Too many tries. Wait a moment.")
        b = self._body() or {}
        if not verify_password(b.get("password") or "", st.get("password")):
            note_failure()
            return self._err(401, "bad_password", "That password was not accepted.")
        note_success()
        return self._send(200, {"token": new_session(), "expiresIn": SESSION_TTL})

    def _change_password(self, st):
        b = self._body() or {}
        if not verify_password(b.get("currentPassword") or "", st.get("password")):
            return self._err(401, "bad_password", "Current password was not accepted.")
        new = b.get("newPassword") or ""
        if not (8 <= len(new) <= 128):
            return self._err(400, "weak_password", "Use at least 8 characters.")
        st["password"] = hash_password(new)
        save_state(st)
        drop_sessions()
        return self._send(200, {"changed": True})

    def _pair_reply(self, r):
        if r.get("ok"):
            return self._send(200, {"result": r.get("result")})
        return self._err(400, r.get("code", "failed"), friendly(r.get("code", ""), r.get("detail", "")))

    def _proxy_verb(self, verb, params=None):
        r = call_setupd(verb, params)
        if r.get("ok"):
            return self._send(200, {"result": r.get("result")})
        return self._err(400, r.get("code", "failed"),
                         friendly(r.get("code", ""), r.get("detail", "")))

    def _wifi_connect(self):
        b = self._body()
        if b is None:
            return self._err(400, "bad_request", "Could not read that request.")
        return self._proxy_verb("wifi_connect", {
            "ssid": b.get("ssid"), "psk": b.get("psk"), "hidden": bool(b.get("hidden"))})

    def _setup_join(self, st):
        b = self._body() or {}
        ssid, psk, h = b.get("ssid"), b.get("psk") or "", b.get("secretHash")
        if not isinstance(ssid, str) or not ssid.strip() or not isinstance(psk, str):
            return self._err(400, "bad_request", "Pick a network first.")
        if h is not None and not (isinstance(h, str) and RE_SECRET_HASH.match(h)):
            return self._err(400, "bad_request", "That pairing code is not usable.")
        st["join"] = {"ssid": ssid, "state": "joining", "at": int(time.time())}
        save_state(st)
        threading.Thread(target=join_in_background, args=(ssid, psk, h), daemon=True).start()
        # 202: the answer has to leave before the setup network does.
        return self._send(202, {"result": {"state": "joining", "ssid": ssid}})

    def _location(self, st):
        b = self._body() or {}
        r = call_setupd("set_location", {"lat": b.get("lat"), "lon": b.get("lon")})
        if not r.get("ok"):
            return self._err(400, r.get("code", "failed"),
                             friendly(r.get("code", ""), r.get("detail", "")))
        st.setdefault("steps", {})["location"] = True
        st["location"] = r["result"]
        save_state(st)
        return self._send(200, {"result": r["result"],
                                "nearestAirports": nearest_airports(
                                    r["result"]["lat"], r["result"]["lon"])})

    def _airport(self, st):
        b = self._body() or {}
        r = call_setupd("set_airport", {"code": b.get("code"),
                                        "atcMount": b.get("atcMount", "")})
        if not r.get("ok"):
            return self._err(400, r.get("code", "failed"),
                             friendly(r.get("code", ""), r.get("detail", "")))
        st.setdefault("steps", {})["airport"] = True
        st["airport"] = r["result"]
        save_state(st)
        return self._send(200, {"result": r["result"]})

    def _tailscale_up(self, st):
        b = self._body() or {}
        r = call_setupd("tailscale_up", {
            "authKey": b.get("authKey"), "hostname": b.get("hostname"),
            "enableFunnel": bool(b.get("enableFunnel"))}, timeout=150)
        if not r.get("ok"):
            return self._err(400, r.get("code", "failed"),
                             friendly(r.get("code", ""), r.get("detail", "")))
        st.setdefault("steps", {})["remote"] = True
        save_state(st)
        return self._send(200, {"result": r["result"]})
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

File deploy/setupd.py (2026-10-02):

#!/usr/bin/env python3
"""Root helper for the StratoScan setup server.

This is the privilege boundary. The HTTP server (setup-server.py) runs
unprivileged and cannot touch the system directly; it asks this process to
perform a fixed set of verbs over a unix socket. The HTTP parser is the part
most likely to be attacked and is therefore exactly the part that must not be
root.

Design rules, all of which exist because breaking them strands or exposes the
appliance:

  * Closed verb enum. There is no generic "run nmcli" or "run systemctl"
    passthrough, so a compromised web tier cannot escalate to arbitrary
    commands -- only to the specific, validated operations below.
  * Every parameter is re-validated HERE, not merely in the caller. The web
    tier's validation is a UX convenience; this is the security control.
  * No shell, ever. subprocess with an argv list, absolute paths, a fixed
    minimal environment, and an explicit timeout.
  * Secrets (WiFi PSK, Tailscale auth key) never appear in argv, where any
    local user could read them from /proc, nor in the journal. They are
    passed through 0600 files on tmpfs that are unlinked immediately.
  * Every state write is atomic and fsynced, including the directory entry.
    A power cut mid-write must never leave a half-written config that stops
    the device booting onto the network.
  * Network changes are add-then-switch with an armed rollback. The working
    profile is never edited or deleted; a new candidate profile is created
    with autoconnect off and only promoted once connectivity is proven.
"""
import contextlib
import fcntl
import json
import os
import re
import shutil
import shlex
import socket
import socketserver
import subprocess
import sys
import time

SOCK_PATH = "/run/stratoscan/setupd.sock"
RUN_DIR = "/run/stratoscan"
STATE_DIR = "/var/lib/stratoscan-setup"
PENDING = os.path.join(STATE_DIR, "pending.json")
LOCK = os.path.join(STATE_DIR, "lock")
READSB_DEFAULT = "/etc/default/readsb"
READSB_ORIG = os.path.join(STATE_DIR, "readsb.default.orig")
READSB_BACKUP = os.path.join(STATE_DIR, "readsb.fr-backup")
CONFIG_JSON = "/var/www/html/config.json"
OFFLINE_MAP_DIR = "/var/www/html/offline-map"
OFFLINE_MAP = "/opt/stratoscan/offline-map.py"
AIRPORTS_JSON = "/opt/stratoscan/airports.json"

CANDIDATE_PROFILE = "fr-candidate"
HOTSPOT_PROFILE = "fr-hotspot"
CONFIRM_WINDOW_S = 180

ENV = {"PATH": "/usr/sbin:/usr/bin:/sbin:/bin", "LC_ALL": "C"}
NMCLI = "/usr/bin/nmcli"
TAILSCALE = "/usr/bin/tailscale"
SYSTEMCTL = "/usr/bin/systemctl"

# Continental US. Deliberately not global: the airport table is CONUS-only,
# and a coordinate outside it means the user mistyped rather than that they
# are genuinely in Alaska.
# Global. These were 24..49.5 and -125..-66.5 -- the continental US -- which
# made the device unconfigurable anywhere else on Earth: a receiver in the
# Netherlands (52.16N, 4.49E) was rejected outright as "outside the
# continental US". A gifted unit has no reason to be US-only.
LAT_MIN, LAT_MAX = -90.0, 90.0
LON_MIN, LON_MAX = -180.0, 180.0

RE_TS_HOSTNAME = re.compile(r"^[a-z0-9]([a-z0-9-]{0,30}[a-z0-9])?$")
RE_TS_AUTHKEY = re.compile(r"^tskey-[A-Za-z0-9_-]{10,200}$")
RE_ATC_MOUNT = re.compile(r"^[a-z0-9][a-z0-9_-]{2,39}$")


class Err(Exception):
    def __init__(self, code, detail=""):
        super().__init__(code)
        self.code = code
        self.detail = detail


# ---------------------------------------------------------------- utilities

def run(argv, timeout=30, check=False, input_bytes=None):
    """subprocess with no shell, fixed env, absolute paths and a timeout."""
    try:
        p = subprocess.run(argv, env=ENV, timeout=timeout, capture_output=True,
                           input=input_bytes, shell=False)
    except subprocess.TimeoutExpired:
        raise Err("timeout", argv[0])
    if check and p.returncode != 0:
        raise Err("command_failed", redact(p.stderr.decode("utf-8", "replace"))[:400])
    return p


_SECRETS = []


def redact(text):
    """Strip any known secret from text before it can reach a log."""
    for s in _SECRETS:
        if s:
            text = text.replace(s, "<redacted>")
    return text


def atomic_write(path, data, mode=0o600):
    """Write + fsync the file AND its directory.

    Without the directory fsync a power cut can leave the rename unrecorded,
    which for /etc/default/readsb means the receiver may not start.
    """
    d = os.path.dirname(path)
    os.makedirs(d, exist_ok=True)
    tmp = os.path.join(d, f".{os.path.basename(path)}.tmp")
    with open(tmp, "w") as f:
        f.write(data)
        f.flush()
        os.fsync(f.fileno())
    os.chmod(tmp, mode)
    os.replace(tmp, path)
    dfd = os.open(d, os.O_DIRECTORY)
    try:
        os.fsync(dfd)
    finally:
        os.close(dfd)


@contextlib.contextmanager
def state_lock():
    os.makedirs(STATE_DIR, exist_ok=True)
    with open(LOCK, "w") as f:
        try:
            fcntl.flock(f, fcntl.LOCK_EX | fcntl.LOCK_NB)
        except BlockingIOError:
            raise Err("busy", "another change is in progress")
        try:
            yield
        finally:
            fcntl.flock(f, fcntl.LOCK_UN)


def secret_file(name, value):
    """Hand a secret to a subprocess without putting it in argv."""
    os.makedirs(RUN_DIR, mode=0o700, exist_ok=True)
    path = os.path.join(RUN_DIR, name)
    atomic_write(path, value, mode=0o600)
    return path


# --------------------------------------------------------------- validation

def v_lat(v):
    if isinstance(v, bool) or not isinstance(v, (int, float)):
        raise Err("bad_lat", "not a number")
    if v != v or v in (float("inf"), float("-inf")):
        raise Err("bad_lat", "not finite")
    if not (LAT_MIN <= v <= LAT_MAX):
        raise Err("lat_out_of_range", f"{v} is not a latitude")
    return float(v)


def v_lon(v):
    if isinstance(v, bool) or not isinstance(v, (int, float)):
        raise Err("bad_lon", "not a number")
    if v != v or v in (float("inf"), float("-inf")):
        raise Err("bad_lon", "not finite")
    if not (LON_MIN <= v <= LON_MAX):
        raise Err("lon_out_of_range", f"{v} is not a longitude")
    return float(v)


def v_ssid(v):
    if not isinstance(v, str):
        raise Err("bad_ssid")
    b = v.encode("utf-8")
    if not (1 <= len(b) <= 32):
        raise Err("bad_ssid", "must be 1-32 bytes")
    if any(c in v for c in ("\x00", "\r", "\n")):
        raise Err("bad_ssid", "control characters")
    # nmcli has no reliable "--" terminator across all subcommands, so an
    # SSID that begins with a dash could be read as an option. Rejected
    # rather than risk it; genuinely rare, and documented in the UI.
    if v.startswith("-"):
        raise Err("ssid_leading_dash", "network names starting with '-' are not supported")
    return v
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

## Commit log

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2026-08-17 Show a real aircraft photo in the detail panel
    Adds the photo lookup I skipped when building the detail panel earlier:
    planespotters.net's photo API requires a descriptive custom User-Agent
    identifying the calling application, which browser fetch()/XMLHttpRequest
    can never set themselves (browsers own that header exclusively). Solved
    with a small local-only proxy on the Pi (deploy/photo-proxy.py) that adds
    the proper header server-side, cached in-memory per hex for 24h; lighttpd
    routes /photo/<hex> to it (deploy/89-flightwall-photo-proxy.conf) so the
    browser's fetch stays same-origin, exactly like aircraft.json/receiver.json
    already are. Runs as its own systemd service
    (deploy/flightwall-pho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
    [photo-proxy.py]
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2026-08-23 Security pass ahead of going public: Funnel coordinate leak, stored XSS, unauthenticated /approaches, and PII in current files
    - New deploy/funnel-gateway.py sits between Tailscale Funnel and lighttpd.
    /tar1090/data/receiver.json returns survey-precision coordinates, and
    Funnel exposes the whole site (not just index.html) to the public
    internet with no auth -- anyone could curl the exact home location.
    The gateway rounds those coordinates to 2 decimal places (~0.7mi) for
    Funnel traffic only; LAN/kiosk access (port 80 directly) is unaffected,
    since readsb itself needs the exact value for its own signal-range math.
    Verified live: public URL now rounded, LAN URL still exact.
    - sh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
    [approach-store.py, funnel-gateway.py]
2026-08-23 Stop leaking server version banners on the public-facing proxies; add baseline security headers
    All three Python services (funnel-gateway, approach-store, photo-proxy)
    were sending their real BaseHTTPRequestHandler Server header (Python/http.server
    version), and requests through funnel-gateway got a second, duplicate Server
    header layered on top from whatever lighttpd/upstream sent -- e.g. curling
    the public URL showed both "BaseHTTP/0.6 Python/3.13.5" and "lighttpd/1.4.79"
    on the same response. version_string() now returns a generic "FlightRadar"
    on all three, and funnel-gateway excludes the upstream's own Server header
    from what it forwards.
    Also added X-Frame-Options/X-Content-Type-Optio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
    [approach-store.py, funnel-gateway.py, photo-proxy.py]
2026-08-23 Track per-aircraft sighting counts, especially within the 2-mile alert radius
    New shared server-side store (deploy/sighting-store.py, matching
    approach-store.py's pattern) tracking two numbers per hex: total distinct
    visits, and how many of those came within ALERT_RADIUS_NM. Shared across
    every viewer and persisted across reboots, same reasoning as the approach
    track data -- a browser-local count would never be visible from a different
    device.
    Counts are recorded once per distinct event, not once per poll: `total`
    increments when a plane is newly added to `planes` (a real gap since last
    seen, not just still in view), `nearby` increments the same moment
    checkNearbyAlert's pl.alerted first fl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
    [sighting-store.py]
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2026-08-29 Add the enclosure's OpenSCAD source to the repo
    The case design lived only as a loose file in ~/Downloads, alongside
    dozens of unrelated STLs, with no history beyond ad-hoc .bak copies. It
    represents as much work as the software and none of it was recoverable if
    that folder were tidied.
    Committing the source only. The STLs are build output (~15MB of binary
    that changes wholesale on any edit) and are gitignored -- regenerate with
    openscad -D 'part="shell"' -o shell.stl enclosure/flightwall-enclosure.scad
    enclosure/README.md documents the four parts, the two test-coupon targets,
    and the dimensional traps that actually bit during this build: glass sheet
    vs panel module depth for the rabbet,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
    [flightwall-enclosure.scad]
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2026-08-29 Fix public bypass of the gateway's local-only path filter
    The filter compared the RAW request path, so it did not actually keep
    privileged endpoints off the public tunnel. lighttpd percent-decodes and
    collapses traversal before routing, so three variants reached /wake while
    none of them string-compared equal to it. Confirmed live against the
    deployed device before the fix -- /./wake, /x/../wake and /%77ake each
    returned 204 (display powered on) instead of 404, reachable by anyone
    holding the Funnel URL. Introduced in 1500098 earlier today.
    The path is now decoded (repeatedly -- one pass turns %2577 into %77, not
    into 'w'), backslash-folded, slash-collapsed and normpath'd before
    matching. Ev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
    [funnel-gateway.py]
2026-08-29 Add the root helper for the setup server
    The privilege boundary for device provisioning. The HTTP tier (next commit)
    runs unprivileged and can only reach the system through the closed 14-verb
    enum here -- there is no generic 'run nmcli' or 'run systemctl' passthrough,
    so compromising the HTTP parser does not yield arbitrary root commands.
    Choices that exist because of specific failure modes:
    - WiFi is add-then-switch with commit-confirm. The working profile is never
    edited or deleted; a candidate profile is created with autoconnect off and
    promoted only after connectivity is PROVEN (address + gateway + reachable),
    because NetworkManager reports 'activated' for an association that nev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
    [setupd.py]
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2026-08-29 Add factory reset and password change to the setup page
    Both go on the setup page, behind the password -- deliberately NOT on the
    radar's gear panel, which has no authentication. Anyone who walks up to the
    kiosk can open that panel, and a 'wipe this device' button there would be
    triggerable by a guest tapping the screen.
    Two reset tiers, because they answer different questions:
    - Reset settings clears the location and home airport but leaves WiFi and
    Tailscale alone, so the device is still reachable afterwards. A reset that
    dropped the network would be indistinguishable from a brick to anyone
    without a keyboard.
    - Erase everything is for handing the unit on. It removes the WiFi profi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
    [setup-server.py, setupd.py]
2026-08-29 Allow full setup and reset from the radar's own screen
    The device can now be set up end to end without a phone: WiFi (scan, pick,
    type the password), receiver location, home airport, and a full reset --
    all from the touchscreen, under a new Device setup section in the menu.
    This needed an on-screen keyboard, which is a hard requirement rather than a
    convenience: a WiFi password has to be typeable somehow, and a recipient may
    have no phone to hand. It opens on the layout the field actually needs
    (numeric for coordinates, capitals for the ERASE confirmation), masks
    secrets on screen while returning the real value, and takes the whole
    display because a 1080px round panel has no room to share.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
    [setup-server.py]
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2026-08-29 Add remote access to the on-device setup screens
    Completes the on-screen setup: WiFi, location, airport, remote access,
    password and reset are all reachable from the radar itself.
    Tailscale is set up by INTERACTIVE LOGIN rather than by pasting an auth key.
    A tskey is ~50 characters and typing one on a touch keyboard is miserable
    enough that people would simply not do it. Instead the device runs
    'tailscale up' without a key, captures the short login URL it prints, shows
    that on screen, and polls until the backend reports Running. The owner signs
    in on a phone; nothing long is typed on the radar. A login already in flight
    returns the same URL rather than starting a second one, which would
    inv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
    [setup-server.py, setupd.py]
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2026-08-29 Fix the web tier being locked out of its own state file
    Reported symptom: after tapping reset, the device asked for a password to be
    set again, and the owner's existing password no longer worked.
    Nothing had been erased. Both units declared StateDirectory=flightradar-setup,
    so systemd created it for whichever started first -- the root helper --
    giving 0700 root:root. The unprivileged web tier could not even enter the
    directory, so load_state() silently fell back to its "unclaimed" default.
    That fallback is deliberate and still correct (a corrupt state file must
    never lock an owner out of their own hardware), but here it masked a
    permission fault as a factory-fresh device: the unit reported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
    [setup-server.py, setupd.py]
2026-08-30 Show what is being typed on the device keyboard
    Reported from the device: the keyboard works but there is no way to tell
    what has actually been entered.
    There was a field above the keys, but two things made it useless:
    - Anything marked secret was masked, so a WiFi password -- the single most
    error-prone thing anyone types here -- showed only bullets. On an
    unfamiliar on-screen keyboard a mistyped password is near-certain, and
    masking made it invisible until the join failed with no clue why.
    - The text was 17.6px. That is reasonable on a phone held at 30cm and
    useless on a wall-mounted panel viewed at arm's length.
    Secret fields now start REVEALED, with a Hide key for anyone who w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
    [setupd.py]
2026-08-30 Add a captive portal, keep the setup hotspot up, and stop the gateway hanging on redirects
    Three related fixes for first-run setup by someone with only a phone.
    1. Captive portal. A phone joined to an AP with no internet does not simply
    use it: iOS and Android probe for connectivity, decide the network is
    useless, and quietly route traffic over cellular -- so typing the setup
    address reaches the internet and fails while the phone shows itself
    connected to the hotspot. Observed exactly that on this device: the page
    served fine on 10.42.0.1 and the phone still could not load it.
    Answering those probes with a redirect is what tells the OS the network
    needs sign-in, keeping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
    [funnel-gateway.py, net-watchdog.py, setup-server.py]
2026-08-30 Fix Funnel silently failing after a device rename
    Setting a hostname during setup renames the Tailscale node, and two separate
    faults meant the public URL then did not exist -- while the device reported
    itself connected and nothing looked wrong in either place.
    1. The serve config stayed bound to the OLD name. After a rename from
    flightwall to flightradar-rdu, `serve status` still advertised
    [device].ts.net, funnel was off, and the advertised URL was
    for a name the node no longer had. The serve config is now reset before
    being re-applied, and re-applied automatically whenever the node was
    already publishing, since a rename invalidates it.
    2. The funnel CLI form was obsolete.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
    [setupd.py]
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2026-09-01 Show connectivity on the radar, and add a Restart to Device setup
    Two things a display in another room needs to answer without a laptop: is
    this working, and can I make it try again.
    The status pill is deliberately always visible rather than only appearing on
    failure. The question it answers is "is it working?", and something that is
    invisible when healthy cannot answer that -- you can never tell working from
    broken-and-silent, which is exactly the state this session started in.
    Connectivity comes from NetworkManager's own probe, reported by setupd as a
    new field on net_status, rather than this page making an outbound request to
    some third party to test the line. "limited"/"portal" is the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
    [setup-server.py, setupd.py]
2026-09-02 Stop the watchdog from taking a healthy radar off the network
    The Pi has been dropping off every couple of days and needing a power cycle.
    The cause was this watchdog, not the WiFi.
    have_connectivity() was a single ping with a 3s timeout, run every 120s, and
    one failure went straight to hotspot_start -- which puts wlan0 into AP mode
    and takes the unit off the LAN entirely. WiFi loses a frame for entirely
    ordinary reasons (a mesh steering the client, a channel scan, the router
    rebooting), all of which recover on their own in seconds. This turned every
    one of them into an outage lasting until someone reached over and pulled the
    plug.
    Evidence, since the journal was volatile and had none: Net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
    [net-watchdog.py]
2026-09-02 Stop the connectivity pill polling the device six times a minute
    The pill added yesterday refreshed /onboard every 30s. That endpoint is not
    cheap: it shells out to roughly six nmcli processes plus a tailscale call,
    measured at 200-540ms per request on this device. Before the pill existed it
    was only ever fetched at startup and after a setup action, so this was new,
    permanent background load -- on a Pi that is already sitting at its thermal
    limit with the fan maxed out, and on the very subsystem (NetworkManager)
    whose stability was the thing being fixed the same day.
    Two changes. The client polls every three minutes instead of thirty seconds:
    nothing it displays changes quickly, an SSID or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
    [setup-server.py]
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2026-09-03 Remove the SDR dongle pocket from the shell floor
    It was a fitted open-topped tray sized to the dongle. In the assembled unit
    it does not work: the dongle plus its USB lead and antenna pigtail do not sit
    the way a rigid tray assumes, so the pocket fought the cable routing instead
    of helping it. The dongle just lies in the cavity, which is what was
    happening in practice anyway.
    Removes the tray, the four dongle_* globals it was the only user of, and the
    three comments elsewhere that described its footprint as an area to avoid --
    those would otherwise send the next reader looking for geometry that is no
    longer there.
    Verified rather than assumed: intersecting the shell with the volume the
    po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
    [flightwall-enclosure.scad]
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2026-09-03 Add a kitten enclosure alongside the retro one
    Same radar, different animal. The existing case moves to "Retro Radar
    Enclosure" and a second design joins it, built on the idea that the round
    display is a cat's face.
    Every dimension touching a physical part is copied verbatim from the retro
    build, which is printed and validated: the 203.34mm panel, the Pi's 58x49
    standoffs, the two 100x45 speakers, the 30mm fan, the M3 screw ring, the
    USB-C and SMA bulkheads. Only the shape is new, so a build moves between the
    two cases without rework.
    The cat is in the shell's ears, the bezel's nose and whisker grooves, and the
    stand's paws and curled tail. The speakers keep their exact bracket and
    footpri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
    [checks.scad, flightwall-enclosure.scad, kitten-enclosure.scad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]
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2026-09-04 Make the kitten stand's paws and tail lifelike
    PAWS were a flat capsule with three domes stuck on top. A real foreleg is
    narrow and taller at the ankle, spreading and flattening forward into a pad,
    with toes splayed across the front and clefts between them. Now built from
    hulled ellipsoids so the top domes rather than ending in a flat disc, with
    four toe lobes and a cleft cut between each pair.
    The toes did not work on the first attempt: they sat behind the pad's front
    sphere, entirely inside the hull, contributing nothing -- the paws rendered
    as plain teardrops. The toe tips now define the paw's front edge and the pad
    is held back behind them, so they lead and the clefts have something to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
    [checks.scad, kitten-enclosure.scad]
2026-09-04 Wrap the kitten's tail tight and drape it over the right paw
    It was held out at arm's length: 18mm proud of the plinth at the widest and
    51mm past the front, curling in empty space ahead of both feet. It now hugs
    the plinth edge round the right side, climbs the right paw's outboard flank
    and comes to rest across the top of the foot, with the toes showing beneath
    and in front. Overhang drops to 7mm at the side and 26mm at the front, and
    the paws are now the deepest part of the stand rather than the tail.
    That inverts what the interference check should assert. Tail and paw now
    deliberately meet, so "must not touch" is the wrong test; what must not
    happen is the tail passing THROUGH the foot a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
    [checks.scad, kitten-enclosure.scad]
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2026-09-04 Give a ghost the same panel a local contact gets
    Tapping a network ghost showed six fields where a local aircraft shows
    nine, and badged it "adsb.lol" where a local one names the airline -- so
    the same flight looked like a different class of object depending on
    which receiver happened to hear it. The missing fields were missing from
    the proxy, not the panel: forward squawk, vertical rate (baro_rate, or
    geom_rate when a transponder only reports the GNSS-derived one) and the
    emergency flag, all of which adsb.lol already sends.
    The panel now shows heading, vertical rate, squawk, sightings and the
    notable-aircraft marker alongside what it had, badges the operator via
    the same derivation local c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
    [network-compare.py]
2026-09-04 Give ghosts their representative photo, and default the comparison on
    Three things, all in the network comparison.
    The photo. tryStockPhoto read the aircraft type from `planes`, the map of
    what THIS antenna heard -- so a ghost, which by definition is not in it,
    fell straight through to the placeholder even when its type was known and
    printed in the panel directly above the empty frame. GA tails felt it
    hardest: they rarely have a planespotters photo of the specific airframe,
    so the representative-photo path was the only one they were ever going to
    get. Resolve the type from the ghost track too. Checked against five live
    ghosts that were all blank before: a Cessna 172, a Bonanza, a PA-28 and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
    [network-compare.py]
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2026-09-04 Track sightings by day of week alongside hour of day
    Same shape as the hour histogram and incremented in the same place: one
    bucket per ISO weekday, from the device's local clock, because "when is it
    busy here" is a question about this house's week and not about UTC. Monday
    is index 0 in both the store and the chart labels, so the array and the
    axis cannot drift apart.
    A store written before this existed simply has no week in it. That is not
    corruption, so it is repaired to an empty week and fills from live traffic
    rather than being treated as a broken file -- the same path `hours` already
    takes, and the migration checks cover it.
    The chart says how much of the week it has actually seen. O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
    [sighting-store.py]
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2026-09-04 Restart the kiosk when the display stops painting
    Found on the device after it was reported frozen. Chromium's GPU command
    buffer failed to allocate at 15:35:21 and logged the same fatal error
    345,827 times over the next fifty minutes. Nothing was painted again: the
    panel kept showing the frame that happened to be up, complete with stale
    "0 AIRCRAFT / NO SIGNAL", while readsb underneath was perfectly healthy and
    serving fresh traffic the whole time.
    The page was alive by every internal measure. Its timers kept firing --
    the network-comparison store was still being written one second before I
    looked -- so nothing the page could check about itself would have caught
    this, and nothing outside t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
    [wake-listener.py]
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2026-09-05 Add a two-tone kitten stand: white paws, black toes, white tail tip
    A fork, not a replacement -- "Kitten Enclosure" is untouched and still
    printable, and the head is dimensionally identical, so a head from either
    design sits in either stand. Only the stand differs.
    The paws and tail are about 15% bigger. In two colours they stop being a
    silhouette detail and become the thing the eye lands on, so they have to
    carry that attention. How far that could go was decided by the head rather
    than by taste: the cradled shell's underside comes down to about z=27, and
    paws_vs_head and tail_vs_head are what said when it had gone far enough.
    The stand is split into five bodies in one coordinate frame --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
    [checks.scad, front_trim.stl, kitten-enclosure-twotone.scad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]
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2026-09-05 Smooth the curves: resolution by chord length, not facet count
    The visible faceting came from a fixed $fn, which makes the flats grow with
    the feature -- so the largest, most looked-at surfaces were the roughest. At
    $fn=96 the head's 223mm rim carried 7.3mm flats and the cradle 8.2mm, while
    every 3mm screw hole also got 96 sides it had no use for. The paws and tail
    were worse in their own way, each pinned to a hand-picked count: 44 for a
    43mm pad, 28 for the tail, 20 for a 3mm cleft.
    Replaced with $fs=0.4 and $fa=0.5, so the chord -- the width of one flat,
    which is what the eye reads as faceting -- is capped rather than the count.
    The head goes from 7.3mm flats to 0.97mm, every sphere in th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
    [checks.scad, front_trim.stl, kitten-enclosure-twotone.scad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]
2026-09-05 Smooth the original kitten enclosure too, and unmask the tail's rings
    Same treatment as the two-tone fork: curve resolution set by chord length
    ($fs=0.4, $fa=0.5) instead of a fixed facet count. The head's 223mm rim goes
    from 7.3mm flats to 0.97mm, the cradle from 8.2mm, and every sphere in the
    paws, toes and tail to 0.4mm -- one extrusion width, below what a 0.4mm
    nozzle can reproduce. Cheaper than raising $fn would have been, since the
    savings on 96-sided 3mm screw holes pay for the big surfaces.
    Smoothing the circumference exposed something underneath it. The tail is
    hulls between consecutive spheres, so every sphere leaves a crease running
    around the tube. The general faceting had been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
    [checks.scad, front_trim.stl, kitten-enclosure-twotone.scad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]
2026-09-05 Smooth the retro enclosure, and remove the misplaced whisker grooves
    Three things.
    The six indentations on the printed kitten faceplate were the whisker
    grooves, and they were in the wrong place. The nose sits at -y, the bottom
    of the face; the grooves were rotated about 0 degrees, the right-hand side.
    So all six landed 90 degrees from the nose they were meant to flank, which
    is exactly how they read in the hand: six unexplained arcs, each 16.8mm,
    down one side of the bezel. Removed from both kitten designs along with the
    module and its two parameters. Reinstating them properly would mean
    rotating them about the nose's own angle; the comment always said "either
    side of the nose", so the int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
    [flightwall-enclosure.scad, front_trim.stl, kitten-enclosure-twotone.scad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]
2026-09-05 Put the whiskers back, beside the nose this time
    Three short arcs each side, placed off nose_angle rather than a literal,
    each sweeping away from the nose so the two sides actually mirror --
    rotate_extrude only sweeps counter-clockwise, so the clockwise side has to
    start a full arc further round and sweep back, which the original did not
    do either.
    Bounded at both ends by what is actually there: the nose is 17mm wide at
    this radius, which is +-4.6 degrees, and the neighbouring screw holes sit at
    +-45. The three offsets are 7, 18 and 29 degrees, leaving clearance at both
    ends, and whisker_vs_nose and whisker_vs_screws pin both.
    The check that matters is whisker_off_nose, because the origina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
    [checks.scad, front_trim.stl, kitten-enclosure-twotone.scad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]
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

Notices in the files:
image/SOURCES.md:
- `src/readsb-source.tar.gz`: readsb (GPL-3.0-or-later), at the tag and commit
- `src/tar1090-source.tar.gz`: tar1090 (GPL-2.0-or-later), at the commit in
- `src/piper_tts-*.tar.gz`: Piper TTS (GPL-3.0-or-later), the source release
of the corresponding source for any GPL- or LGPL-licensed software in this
